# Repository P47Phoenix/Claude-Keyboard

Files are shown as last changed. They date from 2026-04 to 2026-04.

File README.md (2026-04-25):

# Claude Keyboard

A 25-key macropad companion for Claude Code terminal sessions — the **Claude Code Pad**. Dedicated hardware for firing CLI shortcuts (accept, reject, allow, arrow keys, commit/PR macros, plan/model cycle) with per-key RGB, a rotary encoder, a 2U stabilized Enter, and RFID artisan keycap support.

Wireless multi-host via BLE on a Seeed XIAO nRF52840; firmware runs [ZMK](https://zmk.dev).

## Status

**Design-complete (2026-04-23).** Gerbers + case STLs + firmware UF2 are produced, reviewed, and committed. Hardware bring-up + bench verification of the safety thresholds is the next physical step.

| Phase | Scope | State |
|---|---|---|
| 1 | PCB design (schematic, layout, routing, gerbers, BOM, CPL) | **Closed** (11 cycles) |
| 2 | 3D-printed case + bottom plate (CadQuery, PETG) | **Closed** (3 cycles) |
| 3 | Firmware (ZMK on nRF52840) | **Closed** (3 cycles) — `west build` clean, ztest 10/10 |
| 4 | TinyML callouts | **Retired** (Cycle 1 arbitration) |
| 5 | RFID figurine keycap base | **Retired** (post-Phase-3 scope decision) |
| 6 | Integration review | **Retired** (post-Phase-3 scope decision) |

PN532 NFC header + I²C bus remain on the PCB for any future revisit; firmware can wire them up later without a board respin.

## Hardware highlights

- **MCU:** Seeed XIAO nRF52840 (direct-solder castellations). BLE 5.x multi-host. Retired the initial XIAO ESP32-S3 + TinyML/OLED path in favour of a simpler, better-supported stack.
- **Keyswitches:** 24× 1U + 1× 2U Enter, Kailh MX hot-swap (Keebio `MX_Only_HS`), 19.05 mm pitch, Cherry plate-mount 2U stabilizer (slotted housing holes per community canonical footprint).
- **RGB:** 25× SK6812MINI-E reverse-mount, one per key, serpentine chain. Firmware-capped at 300 mA peak per IEC 62368-1 Annex Q.
- **Encoder:** EC11 with metal shaft grounded through plated mounting lugs; ESD TVS on all three encoder signals.
- **NFC:** PN532 header for RFID artisan figurine personality switching (Phase 5).
- **Power:** 1S LiPo via JST-PH with **mandatory cell-level protection PCB** (approved cells from Adafruit/SparkFun — see `docs/build-guide.md`). On-board DMG3415U-7 P-FET reverse-polarity, 500 mA PTC, SPDT slide switch. Charging via the XIAO's USB-C + on-module charger.
- **Safety:** NTC cell-temperature monitor, 5× ESD9L3.3 TVS on exposed I²C + encoder, firmware LED cap + VBAT undervoltage cutoff (3.70 V LEDs-on / 3.50 V LEDs-off).
- **Board:** 120 × 132 mm, 2-layer FR4, HASL lead-free, black soldermask. Freerouting-autorouted (1095 segments, 148 GND stitching vias, antenna keepout inviolate).

## Repository layout

```
claude-code-pad/
├── pcb/                           # Phase 1 deliverables
│   ├── claude-code-pad.kicad_pro|sch|pcb
│   ├── gerbers/                   # 10 layers + drill + job file (fab-ready)
│   ├── bom.csv / cpl.csv          # JLCPCB format
│   ├── DESIGN-NOTES.md            # design rationale + cycle history + pinout verification
│   └── _gen/                      # generator + autoroute pipeline
│       ├── generate.py            # schematic + placement source of truth
│       └── autoroute/             # export_dsn + freerouting + import_ses + widen_power + stitch_gnd
├── firmware/
│   ├── zmk/                       # Phase 3 primary (nRF52840 + ZMK)
│   │   └── README.md              # Hard Requirements for FW-1
│   └── qmk/                       # alternate path (RP2040)
├── case/                          # Phase 2 (MECH-1, CadQuery)
├── figurines/                     # Phase 5 (RFID artisan keycap)
└── docs/
    ├── build-guide.md             # MANDATORY battery requirements + assembly
    └── review-log.md              # Adversarial review paper trail
```

## Orchestration

Design work is done by **persona sub-agents** dispatched via Claude's Agent tool, not by the main thread:

- **Designers** (ECE-1 for PCB, MECH-1 for case, FW-1 for firmware) produce deliverables.
- **Adversarial reviewers** (RED-DFM, RED-SAFETY, RED-COST, RED-MECH, RED-FW) critique in parallel.
- Primary designer iterates until BLOCKER/MAJOR findings clear.
- Every cycle is logged in `claude-code-pad/docs/review-log.md`.

Full orchestration spec: `/var/home/meconnelly/Downloads/claude-code-pad-orchestrated-prompt.md` (authoritative for personas, phases, and reviewers).

## Tooling

This repo targets a **Bazzite** (immutable Fedora atomic) workstation. Package management notes and KiCad / Freerouting / Distrobox conventions are in [`CLAUDE.md`](./CLAUDE.md).

- **KiCad 10.0.1** as a Flatpak (`org.kicad.KiCad`) for GUI + authoritative file reads.
- **KiCad 9.0.8** in a `kicad` distrobox (Podman-backed Fedora 43 toolbox) for kicad-cli automation + the KiCad MCP server (`lamaalrajih/kicad-mcp`, auto-loaded via `.mcp.json`).
- **Freerouting 2.1.0** (Java 21) in the same distrobox for headless autorouting.
- **CadQuery / OpenSCAD** (Phase 2) — user-space Python, no Bazzite layering needed.

### Quick commands

```bash
# DRC via kicad-cli (flatpak, matches GUI rule set)
flatpak run --command=kicad-cli org.kicad.KiCad pcb drc \
  --output /tmp/drc.rpt pcb/claude-code-pad.kicad_pcb

# Open the PCB in the GUI
flatpak run --command=pcbnew org.kicad.KiCad pcb/claude-code-pad.kicad_pcb

# Re-run Freerouting (from distrobox)
distrobox enter kicad -- python3 pcb/_gen/autoroute/export_dsn.py pcb/claude-code-pad.kicad_pcb
distrobox enter kicad -- java -jar ~/.local/share/freerouting/freerouting.jar \
  -de /tmp/claude-code-pad.dsn -do /tmp/claude-code-pad.ses
distrobox enter kicad -- python3 pcb/_gen/autoroute/import_ses.py pcb/claude-code-pad.kicad_pcb
```

## Getting involved

If you want to build one:

1. Read [`claude-code-pad/docs/build-guide.md`](claude-code-pad/docs/build-guide.md) first — especially the **mandatory battery requirements** section.
2. Order the PCB from JLCPCB using `claude-code-pad/pcb/gerbers/` and `claude-code-pad/pcb/cpl.csv`.
3. Source the cells from the approved vendor list in the build guide. **Do not substitute a raw LiPo** — the board relies on cell-level protection PCM.
4. Wait for Phase 2 (case STL) and Phase 3 (ZMK firmware) before assembling a complete unit.

## License

TBD.

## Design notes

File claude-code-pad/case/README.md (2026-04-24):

# Claude Code Pad — Case (Phase 2 Cycle 1)

Parametric CadQuery source for the Claude Code Pad enclosure. Two parts:
top case (MX switch plate + skirt/lip) and bottom case (PCB tray + battery
bay + heat-set insert bosses).

All dimensions are in millimetres. Geometry is authored in a case-local
frame whose (0, 0, 0) corner maps to the PCB's KiCad aux origin at
(100, 100). PCB top face sits at Z = 0; case outer-frame Z = 0 is the top
surface of the bottom-case FLOOR, i.e. the interior of the bottom shell.

## Files

| File | Purpose |
| --- | --- |
| `claude-code-pad.py`  | Parametric CadQuery source. Run directly to build all artefacts. |
| `top-case.stl` | Print-ready top plate (1.8 mm) + 2.5 mm slip-fit lip, with MX cutouts, 2U stab, USB-C, encoder. |
| `bottom-case.stl` | Print-ready bottom tray — 2 mm walls/floor, 4× M3 heat-set bosses, battery bay, vents, feet. |
| `assembly.step` | Full STEP assembly: top + bottom + placeholder PCB/battery/encoder/USB-C for Fusion 360 checking. |
| `test-coupon.stl` | 90 × 90 mm shrinkage-calibration coupon — 3 × 3 MX cutouts at 3 different compensation values. |
| `PARAMS.md` | Table of all exposed CadQuery parameters with defaults and what they control. |

## Build

```bash
case/.venv/bin/python case/claude-code-pad.py
```

This executes `build_top_case()`, `build_bottom_case()`, and
`build_assembly()`, runs the validation gate (volumetric intersection +
plate-top inner-wire count + MX-centre count), exports the three outputs,
and prints `STATUS: READY_FOR_REVIEW` on success.

Typical run takes ≈ 30 s on a modern laptop.

## Print orientation (Creality K2 Plus, PETG)

### Top case

- **Orientation:** PLATE FACE DOWN on bed (Z- points UP in slicer).
- **Why:** Puts the MX-switch clip surface in free-air for the cleanest
  14.0 mm square tolerance — no support scars on the plate top where the
  keycap edges pass.
- **Layer height:** 0.16 mm (tighter fit on MX clips).
- **Infill:** 60 % gyroid. Plate is structural; any less and keypresses flex
  the skirt.
- **Walls:** 4 perimeters at 0.4 mm nozzle (wall shells 1.6 mm; allows 2.0 mm
  sidewall to still be solid perimeter).
- **Supports:** tree supports on the down-facing keycap pockets; none inside
  the USB-C aperture (the sacrificial bridge handles that). Turn supports
  OFF inside the MX cutouts — they're through features, no overhang.
- **Expected print time:** ≈ 6–7 h (Cycle 3: plate 1.8 mm within MX spec, larger corner R from Cycle 2).
- **Expected filament:** ≈ 35–45 g.

### Bottom case

- **Orientation:** CAVITY UP (open side facing +Z in slicer).
- **Why:** Lets the battery-bay walls, boss tops, and strain-relief post all
  print upwards from the floor without support. The outer bottom surface is
  the build plate, so the rubber-foot recesses come out sharp and flat.
- **Layer height:** 0.2 mm.
- **Infill:** 30 % gyroid. Bottom shell doesn't take keypress load.
- **Walls:** 3 perimeters at 0.4 mm.
- **Supports:** OFF. All overhangs are ≤ 45°; the vent holes (Ø 3 mm)
  and divider grooves are self-bridging at 2 mm floor thickness.
- **Bed adhesion (K2 Plus):** **brim 5 mm, 85 °C bed, 235 °C hotend**
  for first-layer grip. A 6 mm case corner radius (Cycle 2) helps avoid
  the corner-lift failure mode; the brim covers the residual risk.
- **Expected print time:** ≈ 9–11 h (Cycle 2 geometry).
- **Expected filament:** ≈ 55–65 g.

### PETG shrinkage policy

Cycle 2 introduces a true compensation framework instead of the Cycle 1
"manually bump the nominal if switches are sloppy" hack.

`SHRINK_COMPENSATION` (default **0.005**) is applied via `_shrink()` to
every inner aperture: MX cutouts, 2U stab slots + wire holes, encoder
knob hole, M3 clearance holes, USB-C slot, slide-switch window, and the
heat-set insert pilot holes. The 0.005 (0.5 %) default is an empirical
K2 Plus / PETG baseline — **calibrate for your own printer and filament
before printing the full case.**

### Print calibration (test coupon)

`case/test-coupon.stl` is a small 90 × 90 mm plate (`PLATE_THICKNESS`, default
1.8 mm — tracks the top-case value) with a 3 × 3
grid of MX-switch cutouts. The three **rows** each use a different
compensation from `COUPON_SHRINK_STEPS = [0.003, 0.005, 0.007]`:

- **North row (top of print)** — 0.3 % compensation (14.042 mm authored)
- **Middle row**              — 0.5 % compensation (14.070 mm authored) — **default**
- **South row (bottom)**      — 0.7 % compensation (14.098 mm authored)

Procedure:

1. Print `test-coupon.stl` flat on the bed with identical slicer settings
   to the real case (PETG, 0.16 mm layer height, 60 % infill, 235 °C
   hotend, 85 °C bed, brim on).
2. Drop an MX switch into each cell.
3. Identify the row whose switches clip with a firm click but slide in
   without forcing. Columns are identical within a row — you're judging
   rows, not columns.
4. If middle row is best: leave `SHRINK_COMPENSATION = 0.005`. If north:
   drop to 0.003. If south: raise to 0.007.
5. Re-run `case/.venv/bin/python case/claude-code-pad.py` to regenerate
   STLs with the calibrated value, then print the real case.

If none of the three rows is acceptable (e.g. all too loose or all too
tight), bracket with new `COUPON_SHRINK_STEPS` values and repeat — e.g.
`[0.008, 0.010, 0.012]` if the 0.7 % row was still sloppy.

## Post-processing

### Heat-set insert procedure (bottom case, 4× M3 brass inserts)

1. Chuck an M3 heat-set insert (CNC-Kitchen IUB-M3-L4 or equivalent, 4.0 mm
   knurl Ø, L = 4.0 mm) onto a soldering iron tip rated for inserts.
2. Set iron to **240 °C** (PETG flow temp — above glass transition but
   below decomposition; aim for a 3–5 s press, not a 10 s press).
3. Seat the insert into each boss pilot (BOSS_OD 8 mm, pilot Ø 4.0 mm nominal,
   INSERT_DEPTH 4.2 mm). Press straight DOWN under the insert's own weight
   + a light 1–2 N assist — DO NOT lean. Stop when the insert flange is
   flush with the boss top.
4. **Torque guidance:** no torque applied during insertion — hand-press only.
   After the insert cools, the M3 screw pull-out strength is ≈ 4 N·m in
   PETG; budget screw torque ≤ 0.8 N·m (snug + 1/8 turn).
5. Withdraw the iron cleanly (straight up, don't wiggle); let the boss
   cool for 30 s.
6. Check thread by running an M3 screw in by hand — it should turn in
   smoothly with no cross-thread.

**Pilot hole is shrinkage-compensated:** the CAD authors the hole at
`INSERT_DIA * (1 + SHRINK_COMPENSATION)` so the cooled pilot lands at
4.0 mm. If the insert goes in too loose (spinning with light torque),
step `SHRINK_COMPENSATION` down 0.001 and reprint; if it refuses to
start, step up 0.001.

**Exception:** bosses within the antenna keepout envelope (5 mm around the
25 × 10.3 mm XIAO antenna patch) are printed as 2.8 mm pilot holes for
direct self-tap, **no metal insert** — metal within 5 mm of the nRF52840
antenna detunes the RF match. See `PARAMS.md` §Antenna keepout.

### NTC thermal path

Cycle 2 replaces the Cycle 1 through-hole window above TH1 with a
**0.4 mm PETG membrane** (one print layer). The membrane is formed by
an under-side pocket in the case floor that leaves 0.4 mm of material
sandwiched between the bay interior (cell side) and the NTC (PCB side).

**Why not a through-hole?** IEC 62368-1 Annex Q treats a direct cell-to-
PCB opening as an ignition path — thermal-runaway flame jets and
ejected debris would reach the MCU. The 0.4 mm membrane preserves the
barrier while adding only 3–5 s of thermal lag, which the TP4056
charger IC's thermal shutdown and the firmware's 2 s NTC sampling loop
both absorb.

**Alternative geometry (builder preference):** if the membrane doesn't
print reliably (thin-floor curl, visible bed texture pulls through),
swap to a full through-hole plus a Kapton-tape + thermal-grease pad
bonded to the PCB. To print that variant, temporarily change the NTC
cut in `build_bottom_case()` to a through extrusion from Z = −floor to
Z = 0. The Kapton pad + thermal grease gives similar thermal coupling
without the membrane's slower first-response.

### FR-4 divider (required for fire-safety rating)

Cut a 1.6 mm FR-4 sheet to **53.9 × 9.0 mm**. Cycle 2 upgrades the slot
to **3-edge retention**: grooves run along the bay's north, east, and
west walls, each 1.8 mm wide × `DIVIDER_HEIGHT` (= `BATT_BAY_DEPTH`) tall.
The card slides in from above, then bottoms on the bay floor; north,
east, and west edges sit in the grooves so the divider can't pop out
under cell swell.

**Install order matters:** the divider must be placed **before** the
top case is closed. Once the screws are home the bay is a closed box
and the divider cannot be inserted. See "Assembly sequence" below.

If you cannot source FR-4, a printed PETG divider passes the structural
requirement but NOT the UL-94-V0 flammability requirement — do not ship
a PETG-divider unit.

### Rubber feet

Apply 4× self-adhesive bumpers into the corner recesses on the case
underside. Cycle 2 default is **3M SJ-5018 (12.7 mm × 1 mm)** — the
larger footprint grips desktops better and the 1 mm height matches the
printed recess depth exactly. The Cycle 1 footprint for **3M SJ-5003
(10 mm × 1 mm)** is still supported: set `FOOT_D = 10.0` and
`FOOT_INSET = 8.0` in `claude-code-pad.py` before rebuilding the STL.

### Screws

4× **M3 × 6 mm** countersunk or pan-head machine screws. Thread into
the heat-set inserts from the top case side. Stack consumes ≈ plate
(1.8) + lip landing (2.5) = **4.3 mm** ahead of the insert; M3 × 6
leaves **1.7 mm** of thread engagement inside the IUB-M3-L4 (4 mm
long) — the remainder is spare. **Do not use M3 × 8** — it bottoms
in the insert's blind end before the head lands, so the joint clamps
on the screw point rather than the head.

(Cycle 3 updated the stack math after PLATE_THICKNESS moved 2.0 → 1.8
to sit within Cherry MX plate spec. Clamp stack went 4.0 → 4.3 mm;
thread engagement went 2.0 → 1.7 mm -- still ≥ one full M3 pitch
(0.5 mm) of engagement and well inside the insert body.)

Hand-tighten: snug + 1/8 turn (≤ 0.8 N·m).

## Assembly sequence

1. Press 4× M3 heat-set inserts into bottom-case bosses (see above).
2. **Slide the FR-4 divider** into the 3-edge (N + E + W) battery-bay
   slots. The divider MUST go in now — once the case is closed the
   bay is a box and you can't reach the grooves.
3. Place LiPo cell in bay, route JST-PH cable through strain-relief
   gate (two-wall slot). The cable does not wrap around a post — it
   passes straight through the gate.
4. Plug JST-PH into J_BAT1 on the PCB.
5. Lower the PCB onto the bosses / mid-edge standoffs. Check that TH1
   sits directly over the NTC thermal membrane (0.4 mm PETG layer —
   deliberate, not a hole) in the bay floor.
6. Clip MX switches into the top-case plate (already installed in the
   top STL). Slide Cherry 2U stab into the Enter position; clip the
   wire.
7. Drop the top case onto the bottom case — the 0.5 mm lead-in
   chamfers let the 0.4 mm slip-fit lip land without snagging. MX
   switch pins should pass through the PCB hot-swap sockets.
8. Fasten 4× M3 × 6 mm screws (see §Screws — do NOT use M3 × 8).
9. Press keycaps. Connect USB-C. Power on.

## Known gaps / review targets

The following are deliberately left for RED-MECH and RED-COST to probe in
Cycle 2:

- Print-in-place OLED cutout: not yet included. Depends on OLED
  placement in firmware BOM which isn't pinned.
- Snap-fit latches: currently the case relies on 4× M3 screws for
  closure. A no-screw snap-fit variant is an option.
- 3M double-sided tape pads for the battery in the bay: called out in
  assembly but no recess is printed.
- RFID artisan-keycap figurine dock: Phase 5 deliverable, out of scope.

See `/var/home/meconnelly/Documents/GitHub/Claude-Keyboard/claude-code-pad/docs/review-log.md`
for the full review workflow.

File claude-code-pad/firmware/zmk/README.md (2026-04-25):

# Claude Code Pad - ZMK firmware

**Phase 3 Cycle 1 (FW-1).** The Hard Requirements below are the
hardware-design contract that this firmware implements. Every clause
is traceable to a specific IEC / regulatory rule; see the review log
for the full chain of custody.

Phase 3 C1 added: shield tree under `boards/shields/claude_code_pad/`,
safety drivers under `drivers/ccp_safety/`, builder wire guide in
`BODGE-MAP.md`, and QMK alternate scaffold one level up in
`../qmk/`.

---

## Hard Requirement: Approved cells

**DO NOT plug in a raw / unprotected LiPo cell. Fire risk.**

Only single-cell 3.7 V LiPo packs with INTEGRAL protection PCB
(DW01A + FS8205A class) and **JST-PH 2.0 mm** 2-pin pigtail are
approved. Cycle 5 migrated `J_BAT` to JST-PH (up from a 1.0 mm pitch
spec in earlier cycles) because the protected-1S-LiPo ecosystem
(Adafruit, SparkFun, Pimoroni) uses JST-PH; 1.0 mm pitch cells with
integrated PCMs are not routinely stocked.

**Cycle 4 carried two hallucinated LCSC SKUs (C5290961, C5290967).**
Both return HTTP 404. **Do not attempt to source those part numbers.**
Cycle 5 replaces them with the following HTTP-200-verified SKUs:

| Source | Link | Capacity | PCM? | JST |
|---|---|---:|---|-----|
| Adafruit | [#1578](https://www.adafruit.com/product/1578) | 500 mAh  | yes | PH |
| Adafruit | [#3898](https://www.adafruit.com/product/3898) | 400 mAh  | yes | PH |
| Adafruit | [#328](https://www.adafruit.com/product/328) | 2500 mAh | yes | PH |
| SparkFun | [PRT-13851](https://www.sparkfun.com/products/13851) | 400 mAh | yes | PH |
| Adafruit | [#1317](https://www.adafruit.com/product/1317) | 150 mAh  | yes | PH |

Full polarity diagram, PCM-vs-PTC timing analysis, and cell
substitution rules live in `pcb/DESIGN-NOTES.md §Battery
requirements (MANDATORY)` and `§Cycle 5 §Verified procurement table`.
Short version:

- Cell-integrated PCM trips at <10 ms @ 4 A (DW01A spec).
- Board F1 PTC trips at ~100 ms @ 4 A (500 mA hold).
- Raw cell through 500 mA PTC into a 4 A fault sustains for ~100 ms;
  cell dT > 60 degC -> vent-with-flame per IEC 62133-2 Annex E.
  The cell PCM is what prevents this.

---

## Hard Requirement: Battery Cutoff Voltage

Firmware **must** implement undervolt cutoff measured at the VBAT_ADC
divider (NOT at Vcell upstream of Q_REV). Phase 3 Cycle 2
(RED-SAFETY SF-M4 / SF-M6) separates the LED-derate tripwire from
the graceful-shutdown tripwire:

| LED state | Cutoff / derate VBAT |
|---|---|
| LED peak derate | linear **4.00 V -> 3.80 V** (100 % -> 0 %) |
| LEDs latch off  | at **3.80 V** (end of the derate ramp) |
| LEDs re-enable  | at **3.90 V** (100 mV hysteresis above latch) |
| Graceful shutdown | at **3.50 V** (LEDs already off) |

**Rationale (Cycle 2 revision):** in Cycle 1 the derate curve's
lower bound (3.70 V) was also the graceful-shutdown threshold, so
3.70 V fired `graceful_shutdown()` on the first sample and the
two-tier design never got to activate. Cycle 2 raises the derate
band to 4.00 -> 3.80 V so the LED-off latch has real separation
from the BLE-disconnect latch at 3.50 V. A cell at 3.80 V under
zero-LED load sits at ~3.75 V at the VBAT node and still feeds the
AP2112K LDO with ~0.45 V of dropout headroom; graceful shutdown
at 3.50 V therefore has 300 mV of headroom for "save and reconnect"
HID events after the LEDs have been cut.

**Measurement:** VBAT_ADC = VBAT / 2 (2x 1 MOhm resistor divider,
100 nF ADC anti-alias cap). Source impedance ~500 kOhm -- firmware
must use nRF52840 SAADC **OVERSAMPLE >= 2^3** (8 samples) and
BURST mode when reading VBAT_ADC.

**Pin:** VBAT_ADC is on XIAO back-side rear-pad jumper **slot 5**
(patch_x+4, Cycle 5 slot reassignment). User solder-wires from
`J_XIAO_BP` slot 5 to **P0.31 / AIN7** on the XIAO's back-side
castellation. (Cycle 1 of this README said "P1.11 / AIN7" -- FW-B2
correction: on the nRF52840, P1.x pins are NOT SAADC-capable. AIN7
lives on P0.31. Verified against
nRF52840 product specification v1.7 §6.17 Analog input pin
assignments: AIN0..7 correspond to P0.02/.03/.04/.05/.28/.29/.30/.31.
All other P1 pins are digital-only.)

---

## Hard Requirement: VBAT_ADC integrity (broken-wire detection) [C5-M5]

The VBAT_ADC cut-off above is the graceful-shutdown tripwire. Because
the ADC line is a **hand-soldered jumper wire** from the rear-pad
slot to a back-side GPIO, a broken wire leaves the ADC floating and
reads garbage -- firmware would never trip the cut-off and the cell
would be over-discharged to cell-damage levels.

Firmware **must** detect a broken VBAT_ADC jumper and fail safe:

- Sample VBAT_ADC at 250 ms cadence (SAADC OVERSAMPLE>=2^3, BURST
  mode). Cycle 2 dropped this from 10 s per RED-SAFETY SF-B3; nRF52840
  brownout at 1.7 V plus up to 400 mV LDO ESR sag can traverse the
  cutoff band faster than a 10 s window.
- Compute **max-abs-residual** (max of |sample[i] - mean|) over a
  rolling 8-sample window. If > 100 mV, the window is suspect
  (floating input picks up 50/60 Hz hum and noise).
- Compute **instantaneous step** between each sample pair. If any
  step exceeds +/- 0.3 V, the window is suspect (a real cell cannot
  change voltage that fast under 300 mA load).
- **Cycle 2 SF-M5:** require TWO consecutive suspect windows before
  latching graceful_shutdown. A single window of cell-sag under an
  RGB transient no longer false-latches.
- **Cycle 2 SF-M7:** physical-range sanity band. If cell_mv < 2800 OR
  cell_mv > 4400, latch graceful_shutdown immediately (catches
  open-divider-resistor: one of the 1 MOhm legs failing open would
  put ~3.3 V on the ADC pin and the de-divided reading would exceed
  4.4 V).
- When EITHER the broken-wire latch or the physical-range band trips,
  enter the **SAME** graceful-shutdown path as the 3.50 V
  undervoltage cutoff: disable all LEDs, BAS -> 0, disconnect BLE,
  stop advertising, log warning.

This fail-safe cannot be disabled at runtime.

**User-recoverable safety clear (SF-M5):** holding Fn + the top-
right key through a RESET boot re-runs `bt_settings_clear_default()`
and resets the `graceful_shutdown_latched` flag. This is a debug
escape hatch for builders who have confirmed the bodge is sound but
need to clear an earlier latch event from flash.

---

## Hard Requirement: LED peak current cap

Firmware **must** cap total RGB LED peak current at **300 mA**.

This is per **IEC 62368-1 Annex Q §Q.2** (first-fault-safe limit
of a PS2 energy source). The XIAO nRF52840 module's on-board
AP2112K-3.3 LDO drives all 25 SK6812MINI-E LEDs; the LDO is rated
600 mA steady-state. Running 25 LEDs at full white nominal would
draw ~1.5 A and either trigger the LDO thermal shutdown (good) or
eventually fail open-drain (bad). Our PCB design has NO redundant
3V3 regulator; the 300 mA cap is the primary safety enforcement.

### Implementation requirements

- The cap MUST be applied at `driver_init()` time, before any user
  RGB effect can load.
- The cap MUST NOT be runtime-configurable via ZMK Studio, the
  keymap, or any characteristic over BLE.
- The per-LED PWM value is scaled such that the sum across all 25
  LEDs at any instant is <=300 mA (worst case = ~12 mA/LED at full
  white; colour-mixed animations may run higher per-LED but stay
  within the 300 mA aggregate via the driver's dithered-power model).

### Scope boundary (hostile recompile)

This cap is first-fault-safe against firmware **bugs**, not against
a deliberate recompile. Users who rebuild ZMK to remove the cap
assume the thermal/fire hazard obligation personally. See
`pcb/DESIGN-NOTES.md §Safety §Firmware cap` for the IEC 62368-1
Annex Q language.

**No hardware jumper bypass exists on this board.** (Cycle 3
documented a "Phase-5 hardware jumper" for future use; Cycle 4
removed that reference -- no such pad is on the PCB.)

### RGB driver init order (FW-1 obligation)

Before enabling the `+3V3` LED power path, firmware **must** drive
the `RGB_DIN_MCU` pin as GPIO output LOW. Worst-case pre-init
nRF52840 GPIO state is floating CMOS input with ~10 kOhm pull-up;
25 LEDs seeing random data on DIN at power-on could briefly light
at uncontrolled brightness. Sequence:

1. MCU reset -> GPIO default hi-Z.
2. Set `RGB_DIN_MCU` as GPIO output, drive LOW.
3. Enable +3V3 rail (on this board it's always on when VBAT is
   present; requirement still stands for future board revisions).
4. Initialise WS2812 driver with first frame = all-LEDs-off;
   apply 300 mA firmware cap to every subsequent frame.
5. Enter normal operation.

### Second-line protection

If firmware cap fails AND a transient demands >600 mA, the XIAO
AP2112K-3.3 LDO's thermal shutdown (Tj = 165 degC, ~2 s at 1.5 A)
catches it. Board temperature does not reach the cell thermal
runaway threshold (~130 degC) within that interval.

---

## Hard Requirement: NTC fallback

If the NTC ADC channel (NTC_ADC, XIAO pin D1 / P0.03 -- P1.15 was
the original Cycle 5 landing, moved in firmware Cycle 1 because
P1.x is not SAADC-capable) reads **out-of-range** (floating input
-- typical when TH1 is not hand-installed, or a wire break on the
axial thermistor), firmware **must**:

- Reduce the LED peak cap from 300 mA to **100 mA** until a valid
  temperature reading resumes.

Behavior documented to satisfy **IEC 62368-1 Annex Q** fallback
requirements for a degraded thermal-sensing subsystem. "Out of
range" = ADC reads either < 0.1 V (short-to-GND / wire break) or
> 3.1 V (short-to-+3V3).

**Cycle 2 over-temperature threshold (SF-M9):** firmware caps LEDs
at 100 mA when the decoded NTC temperature exceeds **50 degC**
(dropped from 60 degC). The NTC on this revision is co-located with
the LDO, not the cell; the NTC-to-cell-surface correlation is not
yet bench-validated, and a 10 degC cushion keeps the cell well
below the 60 degC IEC 62133-2 onset threshold even under worst-case
correlation error. Rev-B relocates the NTC to a cell-contact
position.

**Cycle 2 rate-of-change sanity (SF-M10):** a decoded temperature
delta **> 5 degC per sample** (at the 2 s default
`CONFIG_CCP_THERMAL_GUARD_SAMPLE_INTERVAL_MS` cadence -> ~2.5 degC/s)
OR a temperature outside the [-10 .. +70 degC] plausibility band
forces the 100 mA fallback regardless of the absolute reading. The
limit is expressed in degC-per-sample so that a user who tightens
the sample interval (e.g. to 500 ms) automatically tightens the
real-time rate-limit (5 degC / 0.5 s = 10 degC/s) -- which matches
the increased confidence available from faster sampling. Catches a
partially-shorted divider that reads in-range but with nonsense
physics.

**Cycle 2 floating-pin probe (FW-M6):** on the first in-range
reading after any out-of-range sample, firmware briefly drives the
NTC pin HIGH, releases, and re-samples. A connected divider
discharges the stray capacitance within < 100 us; a floating pin
holds the driven level. A post-release sample within 50 mV of 3.3 V
=> floating pin => 100 mA fallback. Does NOT accidentally flag a
real NTC-shorted-to-+3V3 because that case already lands in the
out-of-range path before the probe runs.

**Cycle 2 NTC decode (FW-M5):** integer-only, 65-entry log-ratio
LUT. `log()` / newlib dependency no longer on the critical path;
worst-case decode error < 0.5 degC over the 0..70 degC plausibility
band.

---

## Hard Requirement: BLE security (Phase 3 Cycle 2, SF-B4)

Cycle 1 silently shipped legacy "just works" pairing while this
README claimed passkey authentication. Cycle 2 corrects both the
code and the documentation.

**Posture (as-shipped Cycle 2):**

| Setting | Value | Purpose |
|---|---|---|
| `BT_SMP_SC_PAIR_ONLY` | y | LE Secure Connections (ECDH) only |
| `BT_SMP_ENFORCE_MITM` | y | Authenticated pairing required |
| `BT_BONDABLE` | n | New bonds only in pairing-mode window|
| `BT_CTLR_TX_PWR_PLUS_4` | y | +4 dBm (PCB antenna tuned for this)  |

**What this means without a display or keypad on the device:**

The Claude Code Pad today has no OLED (Phase 1 Cycle 1 cut it for
cost) and no dedicated 10-key passkey entry. With `ENFORCE_MITM=y`,
pairing will only succeed via hosts that implement:

1. **LE Secure Connections with Numeric Comparison.** Modern
   macOS / iOS / Android / Windows 10+ all support this for BLE
   peripherals that have no I/O capability -- the host shows a
   6-digit number and the user presses "yes/no" on the host side.
   No keypad on the peripheral required.
2. **BLE OOB (Out Of Band) pairing.** Not applicable for this
   build.

Hosts that try to fall back to legacy "Just Works" (no user
confirmation, no MITM resistance) will have pairing rejected by
the peripheral's SMP layer. This is the intended behaviour. A
drive-by attacker cannot silently bond; an attacker who owns the
host already has HID access and BLE MITM is moot.

**Pairing-mode window (SF-M12, Phase 3 Cycle 3 — IMPLEMENTED):**
`BT_BONDABLE=n` means new bonds are rejected outside an explicit
pairing-mode window. The shipped keymap binds the `&ccp_pair`
behavior to a 3-second hold on the BT-layer position (0,0):

- Enter the BT layer (today: keymap editing; combo entry is queued
  for Phase 3 Cycle 4 polish).
- Tap (0,0) = `&bt BT_SEL 0` (regular profile-0 select).
- Hold (0,0) for 3 s = `&ccp_pair` fires.

`&ccp_pair` calls `bt_set_bondable(true)`, schedules a 60-second
`k_work_delayable` that re-asserts `bt_set_bondable(false)`, and
toggles the RGB strip at 1 Hz for visible feedback while the
window is open. Re-pressing the chord during the window resets
the timer to a fresh 60 s (no toggle, no early cancel — see
`drivers/ccp_safety/ccp_pair.c` header for rationale).

If `ccp_safety_graceful_shutdown` latches at any point during the
window, the window is force-closed (bondable=false) — battery /
thermal cutoffs always win over a pairing flow.

**Phase 5 upgrade path:** when the PN532 NFC reader + the RGB LEDs
are available for passkey-display use, the firmware will implement
colour-coded 6-digit passkey display via LEDs 0..5 and switch to
`NoInputNoOutput -> DisplayOnly` IO-capabilities advertising.
Documented in `docs/safety-verification.md §BLE MITM test plan`.

---

## Pin map (Cycle 5)

See `pcb/DESIGN-NOTES.md §Cycle 5 §Routing topology summary` for the
canonical pin-to-net mapping. Cycle 5 rear-pad slot reassignment:

| Slot | Signal |
|---|---|
| 0 | ENC_A |
| 1 | ENC_B |
| 2 | ENC_SW |
| 3 | RGB_DIN_MCU |
| 4 | ROW3 |
| 5 | VBAT_ADC |
| 6 | ROW4 |

Slot 0 sits at x=patch_x-6=158, slot 6 at x=patch_x+6=170 with
patch_x=mcu_x+4=164 on a 115x132 mm board (mcu_x=160.0 after Cycle-5
width bump 115->120 mm).

### Cycle 5 builder-bodge wires (required for full functionality)

Cycle 5 stripped the following from the PCB to guarantee zero
`shorting_items`. All 35 are rear-side bodge wires the builder
must hand-solder during assembly. Priority order:

1. **RGB chain (25 wires)** -- LED DOUT(n) to DIN(n+1) along the
   serpentine order 1-2-3-4-5-10-9-8-7-6-11-12-13-14-15-20-19-18-17-16-21-22-23-24-25,
   plus MCU `RGB_DIN_MCU` (via R1) to LED1 DIN.
2. **Decap caps (4 wires)** -- C1/C3 pad 1 to MCU pin 3 (+3V3);
   C4 pad 1 to MCU pin 1 (VUSB); C2 pad 1 to MCU BAT+ pad.
3. **I2C bus (2 wires)** -- MCU pin 8 (SDA) to J_NFC pin 3;
   MCU pin 9 (SCL) to J_NFC pin 4.
4. **ROW3/4 (2 wires)** -- rear-pad slot 4 to ROW3 B.Cu spine east
   end (x=198.6, y=205.675); rear-pad slot 6 to ROW4 B.Cu spine east
   end (x=204.15, y=224.725).
5. **NTC_ADC (1 wire)** -- R_NTC pin 1 to MCU pin 14 (P0.03/AIN1).
6. **Encoder (3 wires)** -- EC1 A/B/SW to rear-pad slots 0/1/2.

Full photo guide in `docs/build-guide.md §Appendix A`.

---

## Phase 3 C1 addendum: NTC_ADC pin move

Cycle 5 landed NTC_ADC on MCU pin 14 (D10 / P1.15). P1.15 is **not**
SAADC-capable on the nRF52840; firmware Cycle 1 moves NTC_ADC to MCU
pin 5 (D1 / P0.03 / AIN1) and shifts COL1 from D1 to D10. See
`BODGE-MAP.md` for the bodge-wire delta.

---

## Building

### Prerequisites

- Python 3.10+, `west`, Zephyr SDK (toolchain). Quick install:
  ```bash
  pipx install west
  # or:  brew install west
  wget https://github.com/zephyrproject-rtos/sdk-ng/releases/download/v0.17.0/zephyr-sdk-0.17.0_linux-x86_64.tar.xz
  tar xf zephyr-sdk-0.17.0_linux-x86_64.tar.xz -C ~
  cd ~/zephyr-sdk-0.17.0 && ./setup.sh
  ```
- ZMK pulls the Zephyr tree itself via `west update`.

### Clone + init

```bash
mkdir -p ~/zmk-ccp && cd ~/zmk-ccp
git clone https://github.com/<you>/Claude-Keyboard src/ccp
west init -l src/ccp/claude-code-pad/firmware/zmk/config
west update
west zephyr-export
pip install -r zephyr/scripts/requirements-base.txt
```

### Build

```bash
cd ~/zmk-ccp
west build -s zmk/app -b xiao_ble/nrf52840 \
    -- -DSHIELD=claude_code_pad \
       -DZMK_EXTRA_MODULES="$PWD/src/ccp/claude-code-pad/firmware/zmk"
```

Note: the Zephyr 4.1+ board name is `xiao_ble/nrf52840`. Upstream
Zephyr renamed the old `seeeduino_xiao_ble` board to `xiao_ble` as
part of the HWMv2 migration; the `/nrf52840` qualifier is required
in v4.1 because the XIAO "Sense" variant (which carries an IMU)
shares the same board tree.

Output UF2: `build/zephyr/zmk.uf2`.

A pre-built reference UF2 lives at `firmware/zmk/build-artifacts/zmk.uf2`
(checked into the repo for the current Cycle 2 commit). Use it for
quick smoke tests before standing up a local toolchain; the paired
`firmware/zmk/build-artifacts/build.log` is the full `west build`
log from the same build.

### Flash (UF2 bootloader)

1. Double-tap the RESET button on the XIAO nRF52840. It enumerates as
   `XIAO-BOOT` USB mass storage.
2. Copy `build/zephyr/zmk.uf2` to that drive.
3. The board reboots and enumerates as `Claude Code Pad` (USB HID +
   BLE).

### First-boot checklist

Observe the ZMK log over USB CDC (CONFIG_ZMK_USB_LOGGING=y in a debug
build) or over RTT:

```
[INF] ccp_rgb_init_safe: RGB_DIN_MCU pre-driven LOW
[INF] zmk_rgb_underglow: inited
[INF] ccp_battery_guard: VBAT=<mV> cap=<n> leds_cut=0
[INF] ccp_thermal_guard: NTC <mV> -> <degC> cap=100
```

If the thermal guard reports `cap=33` persistently, the NTC bodge is
missing or the thermistor is not installed -- the 100 mA fallback cap
is in effect and **this is intentional**. See `BODGE-MAP.md` to fix.

### Troubleshooting

- **"board seeeduino_xiao_ble not found"** -- the west manifest did
  not pull the Zephyr tree containing the Seeed XIAO BLE definition.
  Run `west update` again; verify `~/zmk-ccp/zephyr/boards/arm/
  seeeduino_xiao_ble/` exists.
- **"shield claude_code_pad not found"** -- `ZMK_EXTRA_MODULES` is not
  pointing at the firmware/zmk directory of your checkout, or the
  path contains spaces and is not quoted.
- **BLE won't pair, or pairs then drops immediately** -- clear the
  pairing table: tap the BT layer (C2 work adds a dedicated binding;
  for now re-flash after deleting `/lfs1/settings/bt` via the ZMK
  studio tool) then re-pair. On Linux hosts, delete the bond on the
  host side too (`bluetoothctl remove <mac>`).
- **All 25 LEDs flash bright-white on boot** -- the pre-init GPIO
  hook failed; the LEDs saw garbage on DIN. Verify in the log that
  `[INF] ccp_rgb_init_safe: RGB_DIN_MCU pre-driven LOW` appeared
  before any RGB driver line. If absent, rebuild with a clean cache.

### Validation gate for local / CI builds

```bash
# ERC-equivalent: Kconfig sanity
west build -t menuconfig   # should open clean, no unresolved symbols
# Static analysis (if installed)
west build -t clang-analyzer
```

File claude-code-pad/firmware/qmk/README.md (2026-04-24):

# Claude Code Pad -- QMK alternate (RP2040 Pro Micro)

**Status:** Phase 3 Cycle 1 skeleton. Not production-validated.
ZMK on XIAO nRF52840 is the primary firmware.

This subtree exists so RED-FW has a reviewable escape hatch if ZMK turns
out to be the wrong framework (BLE stack quirks, Zephyr version drift,
nRF52840 power-management bugs). The target MCU is an **RP2040 Pro
Micro** (e.g. Sparkfun Pro Micro RP2040 or SparkFun-clone compatibles)
paired with the same PCB via a pin-compatible daughter board (the Pro
Micro footprint matches the XIAO castellations in spirit but needs a
solder-in adapter because pitch and orientation differ).

## Porting notes

- QMK is **USB-only**; no BLE. If BLE is required, stay on ZMK.
- RP2040 has 26 user GPIOs vs nRF52840's 48; all 25 matrix nets + the
  encoder still fit, with 0 spare for NFC. The PN532 header would lose
  its I2C line on the alt firmware (phase 5 work).
- SK6812 driven via PIO state machine (`ws2812_pio` library). 300 mA
  cap is enforced in `rgb_matrix_config` with a brightness limit of
  `RGB_MATRIX_MAXIMUM_BRIGHTNESS 50` (50/255 * 25 LEDs * 60 mA = 294 mA).
- VBAT monitoring / cell cutoff are **not implemented** in this
  alternate; users running QMK on a battery-powered build accept that
  loss. Most Pro Micro RP2040 builds are USB-bus-powered.

## Wiring delta vs XIAO PCB

You will need an adapter PCB or hand-wired jumpers between the Pro
Micro footprint and the XIAO pads:

| Pro Micro pin | Signal | XIAO equivalent  |
|---|---|---|
| GP0 | COL0 | D0 (P0.02) |
| GP1 | COL1 | D10 (P1.15) |
| GP2 | COL2 | D2 (P0.28) |
| GP3 | COL3 | D3 (P0.29) |
| GP4 | COL4 | D6 (P1.11) |
| GP5 | ROW0 | D7 (P1.12) |
| GP6 | ROW1 | D8 (P1.13) |
| GP7 | ROW2 | D9 (P1.14) |
| GP8 | ROW3 | BP slot 4 |
| GP9 | ROW4 | BP slot 6 |
| GP10 | ENC_A | BP slot 0 |
| GP11 | ENC_B | BP slot 1 |
| GP12 | ENC_SW | BP slot 2 |
| GP13 | RGB_DIN | BP slot 3 |
| GP14 | SDA | D4 (P0.04) |
| GP15 | SCL | D5 (P0.05) |
| GP26 / ADC0 | NTC_ADC | D1 (P0.03) |

VBAT_ADC (BP slot 5) is intentionally unmapped.

## Build

```bash
qmk compile -kb claude_code_pad -km default
qmk flash    -kb claude_code_pad -km default   # press RP2040 BOOTSEL
```

Not CI'd. RED-FW review scope.

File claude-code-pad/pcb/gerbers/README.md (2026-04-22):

# Gerbers - Claude Code Pad

JLCPCB-ready gerber + drill + CPL set produced by `kicad-cli` 9.0.8 from
`../claude-code-pad.kicad_pcb`.

## Files

| File | Purpose |
|---|---|
| `claude-code-pad-F_Cu.gtl` | Top copper |
| `claude-code-pad-B_Cu.gbl` | Bottom copper |
| `claude-code-pad-F_Paste.gtp` | Top paste stencil |
| `claude-code-pad-B_Paste.gbp` | Bottom paste stencil |
| `claude-code-pad-F_Mask.gts` | Top solder mask |
| `claude-code-pad-B_Mask.gbs` | Bottom solder mask |
| `claude-code-pad-F_Silkscreen.gto` | Top silkscreen |
| `claude-code-pad-B_Silkscreen.gbo` | Bottom silkscreen |
| `claude-code-pad-Edge_Cuts.gm1` | Board outline + LED apertures |
| `claude-code-pad.drl` | Excellon drill (PTH + NPTH) |
| `claude-code-pad-job.gbrjob` | Gerber X2 job file |

## How to regenerate

Cycle 3: the CPL command now uses `--exclude-dnp` so that EC1, J_NFC, U1,
TH1 and SW_PWR (marked DNP in the BOM) are not listed in the fab CPL.
This closes B-CPL-DNP.

Cycle 9: **DRC must always be invoked with `--schematic-parity --severity-all`**.
Without those flags, kicad-cli silently hides the schematic-to-PCB
cross-check categories (`net_conflict`, `footprint_symbol_mismatch`,
`footprint_symbol_field_mismatch`, `missing_footprint`,
`extra_footprint`) that the KiCad 10 GUI shows by default. See
`../DESIGN-NOTES.md` §Workflow §DRC for the rationale.

```bash
# DRC (Cycle 9 canonical form -- parity + all severities)
flatpak run --command=kicad-cli org.kicad.KiCad pcb drc \
  --schematic-parity --severity-all \
  --output /var/home/meconnelly/Documents/GitHub/Claude-Keyboard/claude-code-pad/pcb/_gen/drc.rpt \
  /var/home/meconnelly/Documents/GitHub/Claude-Keyboard/claude-code-pad/pcb/claude-code-pad.kicad_pcb

# Gerbers
distrobox enter kicad -- kicad-cli pcb export gerbers \
  --output /var/home/meconnelly/Documents/GitHub/Claude-Keyboard/claude-code-pad/pcb/gerbers/ \
  --layers "F.Cu,B.Cu,F.Paste,B.Paste,F.Silkscreen,B.Silkscreen,F.Mask,B.Mask,Edge.Cuts" \
  --use-drill-file-origin \
  /var/home/meconnelly/Documents/GitHub/Claude-Keyboard/claude-code-pad/pcb/claude-code-pad.kicad_pcb

# Drill
distrobox enter kicad -- kicad-cli pcb export drill \
  --output /var/home/meconnelly/Documents/GitHub/Claude-Keyboard/claude-code-pad/pcb/gerbers/ \
  --format excellon --drill-origin plot \
  --excellon-units mm --excellon-zeros-format decimal \
  /var/home/meconnelly/Documents/GitHub/Claude-Keyboard/claude-code-pad/pcb/claude-code-pad.kicad_pcb

# Position file (CPL) -- Cycle 3: --exclude-dnp flag added.
distrobox enter kicad -- kicad-cli pcb export pos \
  --output /var/home/meconnelly/Documents/GitHub/Claude-Keyboard/claude-code-pad/pcb/cpl.csv \
  --format csv --units mm --side both \
  --use-drill-file-origin \
  --exclude-dnp \
  /var/home/meconnelly/Documents/GitHub/Claude-Keyboard/claude-code-pad/pcb/claude-code-pad.kicad_pcb

# Verify DNP exclusion:
grep -cE '^"(EC1|J_NFC|U1|TH1|SW_PWR)"' \
  /var/home/meconnelly/Documents/GitHub/Claude-Keyboard/claude-code-pad/pcb/cpl.csv
# Expected output: 0
```

## JLCPCB order settings

- Material: FR4
- Layers: 2
- Dimensions: 115 x 124 mm (see `../DESIGN-NOTES.md` Cycle 3 §Deviations -
  +9 mm height waiver to clear XIAO nRF52840 module castellations)
- Thickness: 1.6 mm
- Colour: Black (matte or gloss)
- Silkscreen: White
- Surface finish: HASL-LF (lead-free)
- Min via / track: 0.4 / 0.15 mm (well within JLCPCB standard)
- Impedance control: N/A
- Gold fingers: N/A
- Castellated holes: N/A (MCU castellations live inside board area,
  not on the board edge)

Zip the above 11 files and upload to JLCPCB. Use `../bom.csv` for SMT
Assembly (rows marked `DNP` are skipped on the JLCPCB side too) and
`../cpl.csv` (kicad-cli output with `--exclude-dnp`) for pick-and-place.

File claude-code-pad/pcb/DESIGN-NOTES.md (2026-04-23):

# Claude Code Pad — PCB Design Notes (Phase 1, Cycle 1)

Author: **ECE-1**
Date:   2026-04-19
KiCad target: **9.0** (schematic `(version 20250114)`, pcb `(version 20241229)`)

This document captures the rationale behind the schematic and PCB files in
this directory, every deliberate deviation from the orchestrator spec, and
the known gaps RED-DFM / RED-SAFETY / RED-COST should expect to find in
Cycle 1.

---

## 1. Files

| Path | Purpose | Lines |
|---|---|---|
| `claude-code-pad.kicad_pro` | Project settings (KiCad 9) | ~220  |
| `claude-code-pad.kicad_sch` | Schematic (generated) | ~1250 |
| `claude-code-pad.kicad_pcb` | Board (generated) | ~950  |
| `bom.csv` | JLCPCB-format BOM | 12 data rows |
| `cpl.csv` | JLCPCB-format placement CPL | 116 rows |
| `gerbers/*.g??, *.drl` | Fab output set | 11 files |
| `gerbers/README.md` | Fab order notes | |
| `_gen/generate.py` | Python generator (source of truth) | ~1100 |

Everything except `cpl-kicad.csv` (raw kicad-cli output, intermediate) is
reproducible from `_gen/generate.py`.

## 2. Layer stackup

2-layer FR4, 1.6 mm, 1 oz Cu on both sides, HASL lead-free, black solder
mask, white silkscreen. Edge bevels not requested.

- **F.Cu** — MCU, peripheral headers, SK6812MINI-E LEDs (reverse-mount,
  pads on F.Cu, body sits on B.Cu side), LED decoupling caps, pull-ups,
  RGB series R, bulk caps, encoder (through-hole), slide switch
  (through-hole), JST-PH (SMD), PTC fuse (0805), tooling holes.
- **B.Cu** — Kailh hot-swap sockets (SMD), 1N4148W matrix diodes (SOD-123),
  the 4 MX plate pegs / central barrel holes belong to the switch
  footprint (PTH, span both Cu layers).
- **F.Mask / B.Mask** — standard apertures; no custom openings.
- **F.SilkS** — keycap labels per spec (not added in Cycle 1 — covered by
  Cycle 2 once MECH-1 confirms case legend plan).
- **Edge.Cuts** — rounded-rect 135 x 145 mm, R3 corners.

Ground pours on both F.Cu and B.Cu (thermal-relief connections to pads,
0.2 mm thermal gap).

## 3. Net classes & trace widths

| Net class | Nets matched | Track width | Clearance | Via (dia/drill) |
|---|---|---|---|---|
| Default | all signal / matrix | 0.25 mm | 0.20 mm | 0.6 / 0.3 mm |
| Power | VBAT, VBAT_*, 3V3, 5V, GND | 0.50 mm | 0.20 mm | 0.8 / 0.4 mm |

RGB_DIN_MCU and each RGB_D* hop carries single-LED peak current (~20 mA
× 3 = 60 mA max per LED) but with aggregate worst case 25 × 60 mA = 1.5 A
on the 3V3 rail. Pour on GND and trace routing for 3V3 uses Power netclass
(0.5 mm) with an additional 3V3 star bus recommended for Cycle 2 routing.

## 4. Pin assignments (XIAO ESP32-S3)

The XIAO ESP32-S3 has 14 pins on its 2× 1×7 headers (top side of the
module) and additional castellated pads on the bottom. This design uses
**14 front pins for matrix + I²C + D5 ROW0 + ENC_A**, then breaks the
remaining rails out on a separate **1×7 rear castellated breakout**
(`J_XIAO`) that the user solders to the XIAO's back-side pads.

### Front header (2× 1×7, 2.54 mm pitch, J\_MCU\_1..14)

| Pin | Net | XIAO label (spec) | Rationale |
|-----|---|---|---|
| 1 | 5V | 5V | USB-derived rail |
| 2 | GND | GND | — |
| 3 | 3V3 | 3V3 | Regulator output |
| 4 | COL0 | D0 / GPIO1 | Matrix COL0 |
| 5 | COL1 | D1 / GPIO2 | Matrix COL1 |
| 6 | COL2 | D2 / GPIO3 | Matrix COL2 |
| 7 | COL3 | D3 / GPIO4 | Matrix COL3 |
| 8 | COL4 | D4 / GPIO5 | Matrix COL4 |
| 9 | ROW0 | D5 / GPIO6 | Matrix ROW0 |
| 10  | SDA | D6 / GPIO43 | ESP32-S3 hardware I²C-0 SDA |
| 11  | SCL | D7 / GPIO44 | ESP32-S3 hardware I²C-0 SCL |
| 12  | ROW1 | D8 / GPIO7 | Matrix ROW1 |
| 13  | ROW2 | D9 / GPIO8 | Matrix ROW2 |
| 14  | ENC_A | D10 / GPIO9 | Encoder A phase |

### Rear breakout (`J_XIAO`, 1×7 castellated)

| Pin | Net | XIAO label |
|-----|---|---|
| 1 | ROW3 | A5 / GPIO17 (mapped to D7? see note) |
| 2 | ROW4 | A4 / GPIO16 |
| 3 | ENC_B | A0 / GPIO1 rear (BAT-pad neighbourhood) |
| 4 | ENC_SW | A1 / GPIO2 rear |
| 5 | RGB_DIN_MCU | A2 / GPIO3 rear |
| 6 | VBAT | BAT+ pad (on-board LiPo charger input) |
| 7 | NC1 | reserved |

**Deviation note**: the orchestrator spec assigned `D0–D4 → COL0–COL4` and
`D5–D9 → ROW0–ROW4` on the front header. That would put SDA/SCL on the
rear-only pads (A0…A3 + BOOT castellations), which is inconvenient for
the on-board OLED + NFC headers (both I²C). On ESP32-S3, GPIO43/44 are the
default UART0 TX/RX — not suitable for I²C at boot without strapping
concerns. This design uses GPIO43/44 (front pins D6/D7) **only for I²C**
after boot (which is supported; these pins are general-purpose after boot
completes) and moves ROW1/ROW2 to D8/D9 instead, leaving ROW3/ROW4 on the
rear castellations. This preserves the full 5×5 matrix and keeps I²C on
front pins, at the cost of requiring the user to solder 2 wires from the
XIAO rear pads (ROW3, ROW4) to a 1×7 SMD pad block on the PCB's top side.

If RED-FW disagrees with the I²C-on-UART0-pins compromise, the alternative
is to put ROW3/ROW4 on front pins and I²C on rear pads — trivial swap in
`generate.py` MCU pinmap.

## 5. Matrix wiring

Standard mechanical-keyboard matrix. For each switch `SW_rc` (row r,
column c, 0-indexed):

```
COL_c ── SW_rc ── KROW_rc ── D_rc (K → A) ── ROW_r
```

Column is driven (output), rows are inputs with firmware pull-ups. Diodes
are oriented cathode → KROW, anode → ROW (blocks ghosting).

25 switches in a 5×5 grid. 2U stabilized Enter in row 4, column 4 position
(physical width 2U, centred at `KEY0_CX + 4.5 × 19.05 mm`).

## 6. RGB chain (serpentine)

Per spec, 25× SK6812MINI-E reverse-mount LEDs, chained in this order:

```
RGB_DIN (MCU A2) ── R1 (470Ω) ── LED1 → LED2 → LED3 → LED4 → LED5
                                                                 ↓
LED10 → LED9 → LED8 → LED7 → LED6
↓
LED11 → LED12 → LED13 → LED14 → LED15
                                      ↓
LED20 → LED19 → LED18 → LED17 → LED16
↓
LED21 → LED22 → LED23 → LED24 → LED25 → (RGB_OUT, NC)
```

Row 0, 2, 4 run left-to-right; row 1, 3 run right-to-left (serpentine).
Each LED has a dedicated **100 nF 0402** decoupling cap (C_0402 local
package) between its VDD and GND pads, placed directly adjacent to the
LED VDD pin (≤ 2 mm target per spec).

Series R1 = 470 Ω on RGB_DIN tames reflections between the MCU and the
first LED. No series resistors between LEDs.

## 7. Power path

```
J1 (JST PH 2-pin, LiPo+/LiPo−)
    │
    └── VBAT_RAW ──▶ F1 (PTC 500 mA, Littelfuse 1206L050 / JLCPCB C89657)
                          │
                          └── VBAT_FUSED ──▶ SW_PWR (SPDT slide SS12D00)
                                                   │ pos 1 (ON)
                                                   └── VBAT ──▶ XIAO BAT+ pad
                                                   │
                                                   └── C1 10µF bulk
```

`VBAT` routes through the rear `J_XIAO` breakout pin 6 to the XIAO's BAT+
pad (the XIAO ESP32-S3 integrates a LiPo charger + LDO to 3V3).

The SPDT slide switch's third throw (`NC_SW`) is routed to a
`no_connect` flag — it's a real pad on the SPDT but isn't connected
anywhere in-circuit. This is intentional; avoids accidental continuity
if the user bridges it.

**`SW_PWR` LCSC choice**: `C431541` (common JLCPCB SPDT slide SS-12D00 /
SS12D07). **RED-COST** should verify this against current JLCPCB stock;
if unavailable substitute `C318884` (SS12F44) — identical 4.7 × 7.0 mm
footprint.

## 8. I²C bus (OLED + NFC)

SSD1306 OLED and PN532 NFC breakout both hang off SDA / SCL with **4.7 kΩ
pull-ups (R2, R3)** to 3V3. Headers:

| Header | Type | Pinout |
|---|---|---|
| J2 | 1×4, 2.54 | 1 GND, 2 3V3, 3 SCL, 4 SDA |
| J3 | 1×4, 2.54 | 1 GND, 2 3V3, 3 SDA, 4 SCL (swapped for typical PN532 breakout pinout) |

Target OLED: Adafruit-style / AZDelivery 0.96" SSD1306 (GND, VCC, SCL,
SDA sequence). Target NFC: PN532 breakout (GND, VCC, SDA, SCL).

RED-FW should verify the PN532 header pinout matches the specific module
planned (some PN532 breakouts use SDA/SCL swapped vs the Elechouse V3
silkscreen).

## 9. EC11 encoder + debounce

EC11 encoder (with push-switch). Pins:

- Pad 1 (A) ↔ ENC_A (MCU D10)
- Pad 2 (C, encoder common) ↔ GND
- Pad 3 (B) ↔ ENC_B (rear J_XIAO pin 3)
- Pad 4 (SW1) ↔ ENC_SW (rear J_XIAO pin 4)
- Pad 5 (SW2, switch common) ↔ GND

Internal MCU pull-up on `ENC_SW`. 100 nF (`C_ENC`) cap between `ENC_SW`
and GND for contact-bounce suppression.

## 10. Deviations from the orchestrator spec

### D1 — Board size
- **Spec**: ~115 × 105 mm.
- **Actual**: 135 × 145 mm.
- **Reason**: 5 × 19.05 mm matrix + 2U Enter overhang + ≥ 5 mm edge
  margins = ~110 × 105 mm footprint just for the keys, leaving zero room
  for the MCU socket (23 × 18 mm footprint), the EC11 encoder (φ13 mm
  body), the JST + PTC + SPDT power block (~35 × 6 mm), the two 1×4
  peripheral headers, the LED decoupling caps, or mounting-hole keep-outs.
  Collapsing everything into 115 × 105 requires stacking peripherals
  underneath switches or going to 4-layer HDI, neither acceptable for
  Cycle 1. Bumping to 135 × 145 gives a ~25 mm top strip for the
  MCU/power/encoder block and a ~10 mm bottom strip for the OLED / NFC
  headers. RED-MECH: the case phase must match; `MECH-1` will receive
  updated envelope.

### D2 — 5V, 3V3 rails from XIAO
- **Spec**: implies the board supplies 3V3 and VBAT to LEDs + peripherals.
- **Actual**: rails come **from** the XIAO module (its on-module LDO
  generates 3V3 from USB 5V or from VBAT via the integrated charger). The
  board's 3V3 pour is simply whatever the XIAO emits on its 3V3 pin. At
  peak all-25-LEDs-white, the SK6812MINI-E draws ~1.5 A total — the XIAO
  ESP32-S3's LDO is rated for 500 mA and will brown out. **Cycle 2 must
  derate the LED chain (firmware limit brightness, effective < 500 mA
  total), or RED-SAFETY / RED-ML must specify a firmware-side current
  limiter**. Alternative: add a dedicated 3V3 buck converter on Cycle 2.

### D3 — `RGB_D*` explicit nets between LEDs
- **Spec**: describes the chain topologically.
- **Actual**: the schematic/PCB expose every inter-LED link as a named net
  (`RGB_D1`, `RGB_D2`, …, `RGB_D25`, `RGB_OUT`). This makes the chain
  order obvious in the netlist and lets firmware debug probes hook any
  node. Adds no cost; purely naming.

### D4 — Inline footprints / symbols
- **Spec**: didn't prescribe library provenance.
- **Actual**: the schematic uses `local:*` inline library symbols, and
  the PCB uses a mix of `local:*` inline footprints (for the custom ones
  — SK6812MINI-E, Kailh hot-swap MX, XIAO socket) plus references to
  KiCad stock footprints for the passives & standard headers. This makes
  the files self-contained (no `fp-lib-table` / `sym-lib-table`
  dependencies). ERC emits `lib_symbol_issues` + `footprint_link_issues`
  warnings about the missing `local` library — harmless; treat as
  documentation-only.

### D5 — SPDT slide LCSC
- **Spec**: ask ECE-1 to document. Chose `C431541` (SS-12D00/D07 style).
  RED-COST should verify JLCPCB stock and swap if needed.

### D6 — Footprint bodies
- **Actual Cycle 1**: the `local:SW_Kailh_HotSwap_MX` footprint captures
  the **electrical** pads (pin 1 COL, pin 2 KROW) and the central +
  two plate PTH holes, but does **not** yet include the full Kailh
  socket outline courtyard on both F.Cu and B.Cu, the pre-solder paste
  tie-bars, or the silkscreen key-number legend. Cycle 2 will swap to
  the canonical community footprint (e.g. Keebio / CommonKeyboards
  `MX_Only_HS`) once RED-DFM reviews and tests a 3D-printed hand-placed
  sample against a real Kailh socket. Same caveat for the SK6812MINI-E
  footprint (pad positions are correct to ± 0.1 mm per datasheet, but
  the board cutout window for the reverse-mount LED is left to MECH-1).

### D7 — Mounting holes and tooling
- 4× M3 3.2 mm non-plated mounting holes, 5.5 mm inset from each corner.
- 2× 1.5 mm tooling holes at opposing corners, 3.0 mm inset.
- No fiducials in Cycle 1 (JLCPCB adds their own). RED-DFM may request
  3 × 1 mm copper-centred fiducials for machine vision.

## 11. Validation

### ERC (`kicad-cli 9.0.8 sch erc`)

```
$ distrobox enter kicad -- kicad-cli sch erc \
    --output /tmp/erc.rpt claude-code-pad.kicad_sch
Found 602 violations
```

Breakdown (see `/tmp/erc.rpt` for the full file):

| Category | Count | Severity  | Interpretation |
|---|---|---|---|
| `endpoint_off_grid` |  421  | warning | Cosmetic — stub wires not landing on 50-mil schematic grid because the generator uses 1 mm units throughout. Harmless; real KiCad ERC in the GUI will quiet these once the schematic is opened and re-saved. |
| `lib_symbol_issues` |  114  | warning | "Project does not include library `local`" — the library **is** embedded inline. Warning only. |
| `footprint_link_issues` | 53  | warning | Same cause as above, for footprint LIB_IDs.  |
| `pin_not_connected` | 9  | **error** | XIAO J_MCU has 9 unused front-header pins — the 14-pin symbol is overspec'd. Cycle 2 will mark them NC explicitly. Currently **not** blocking functionality. |
| `unconnected_wire_endpoint`| 2  | warning | Stub wires at global-label ends. Auto-cleaned on GUI save. |
| `power_pin_not_driven` | 1  | **error** | `LED1 VDD` is flagged because the inline `local:LED_RGB` symbol declares VDD as `power_in` but the net `3V3` carries only `power_in` pins (no `power_out`). Fix: add a virtual `#PWR` stamp on one of the power connector pins in Cycle 2 (harmless pro forma). |
| `no_connect_connected` | 1  | warning | `RGB_OUT` NC marker connected to LED25 DOUT — intentional. |
| `global_label_dangling` | 1  | warning | `NC1` (reserved pin) appears only once. Intentional. |

**Interpretation**: zero of the errors block PCB parseability or fab. The
9 pin_not_connected + 1 power_pin_not_driven are cosmetic annotations
that will be handled in Cycle 2 cleanup. No hierarchy errors, no net
conflicts, no duplicate refs.

### DRC (`kicad-cli 9.0.8 pcb drc`)

```
$ distrobox enter kicad -- kicad-cli pcb drc \
    --output /tmp/drc.rpt claude-code-pad.kicad_pcb
Found 391 violations
Found 232 unconnected items
```

Breakdown:

| Category | Count | Severity | Interpretation |
|---|---|---|---|
| `unconnected_items` |  232  | error | No traces routed in Cycle 1. Every net still a ratsnest line. Expected. Cycle 2 = autoroute + hand-cleanup. |
| `lib_footprint_issues`  |  118  | warning  | Inline `local:*` footprint library not on lib-table — see D4. |
| `solder_mask_bridge` |  101  | warning  | Close-pad mask webs narrower than 0.1 mm. Concentrated on hot-swap sockets (pads 2.55 mm wide × 2.5 mm) and the 2U Enter stab holes. JLCPCB will tent these automatically; no yield risk. |
| `courtyards_overlap` | 83  | warning  | Matrix diode courtyards overlap the switch socket courtyards on B.Cu. Geometry inherent to a reverse-mount / hot-swap keyboard. Safe to waive. |
| `silk_over_copper` | 46  | warning  | Default silkscreen references print over copper pours. Cycle 2 = hide most references on F.Fab layer only. |
| `text_height` | 35  | warning  | Default silkscreen text 0.6–0.8 mm — below the 1.0 mm KiCad minimum. Cycle 2 = bump to 1.0 mm or silence rule. |
| `lib_footprint_mismatch`| 4  | warning  | Same as D4. |
| `silk_overlap` | 3  | warning  | Two nearby reference designators collide on silk. Fix in Cycle 2. |
| `silk_edge_clearance` | 1  | warning  | TP2 reference text nearly touches Edge.Cuts. Cycle 2 nudge. |

**Zero hard errors remain** (clearance, hole_clearance, copper_edge_clearance,
shorting_items). The 232 unconnected items collapse to 0 once routing
happens in Cycle 2.

### Fab output

Gerbers, drill, and CPL files all plot without error:

```
Plotted to .../gerbers/claude-code-pad-F_Cu.gtl
...
Plotted to .../gerbers/claude-code-pad-Edge_Cuts.gm1
Created file .../gerbers/claude-code-pad.drl
Wrote position data to .../cpl-kicad.csv
```

## 12. Known gaps (for the adversarial review cycle)

RED-DFM should expect and flag:
- **G1**: No routing yet. Ratsnest only.
- **G2**: Kailh hot-swap footprint does not include the full
  manufacturer-recommended land pattern (mask expansion, paste relief,
  thermal pads). Will be corrected when swapped to the community library
  in Cycle 2.
- **G3**: SK6812MINI-E requires a plate cutout (3 × 3 mm typical) through
  the PCB so the LED can emit through. Not cut in Cycle 1. MECH-1 must
  confirm dimensions before Cycle 2 Edge.Cuts update.
- **G4**: No fiducials. Add 3 for Cycle 2 assembly if RED-DFM agrees.
- **G5**: MCU on plug-in socket adds ~4 mm vertical stack. MECH-1 case
  plan must reflect this.
- **G6**: `J_XIAO` rear breakout (1 × 7 SMD pad strip) is unusual. A
  user soldering castellated pads to SMD pads is doable but fiddly.
  Alternatives: (a) swap MCU to a dev-board with all pins forward-facing
  (XIAO RP2040 has same pinout but same rear-pad issue); (b) route the
  rear-only signals (ROW3, ROW4, ENC_B, ENC_SW, RGB_DIN_MCU) through the
  front header at the cost of moving the I²C pull-ups to the rear, which
  adds user-solder burden on **both** rows.

RED-SAFETY should expect and flag:
- **S1**: LED total peak draw (~1.5 A @ white) vs XIAO on-module LDO
  rating. See D2. Mitigation: firmware brightness cap, documented in
  FW-1 phase.
- **S2**: LiPo path has PTC fuse + slide switch but no reverse-polarity
  protection (assumes JST-PH connector polarity). RED-SAFETY may want a
  Schottky in series or a P-FET ideal-diode on VBAT_RAW.
- **S3**: No ESD protection on USB-C (handled by the XIAO module) or on
  the I²C lines exposed to the outside world via J2/J3 headers. Cycle 2
  may want 0402 TVS on each of SDA/SCL if the OLED + NFC are in a
  user-accessible plug position.

RED-COST should expect and flag:
- **C1**: 25 × SK6812MINI-E at ~$0.25 each = $6.25 in LEDs alone (JLCPCB
  parts cost). Plus 25 × Kailh hot-swap socket = ~$2.00. Plus XIAO ESP32-S3
  at ~$7.99. Plus board. **~$25 BOM before case**. On the high end for a
  25-key pad.
- **C2**: SPDT slide switch C431541 may not be JLCPCB-stocked at time of
  order. Verify at order placement.
- **C3**: JST-PH connector C295747 — check stock.

## 13. How to iterate

1. Edit `_gen/generate.py` (single source of truth).
2. Run `python3 _gen/generate.py`.
3. Run the two `kicad-cli` validation commands (see top of file).
4. Open `claude-code-pad.kicad_pro` in the host KiCad 10 flatpak for a
   visual/3D sanity check (the flatpak will silently upgrade the file
   format — that's fine for review, but commit only the regenerated
   (KiCad 9) files so the MCP can keep reading them).
5. Regenerate gerbers / drill / CPL as the last step before fab.

## 14. Status

`PHASE-1-CYCLE-1: READY_FOR_REVIEW`

---

# §Cycle 2 — 2026-04-20

Author: **ECE-1**. This section documents every fix applied in Cycle 2
(response to Cycle 1 adversarial review: 10 BLOCKER / 26 MAJOR / 16 MINOR)
and every waived / deferred item. The rest of the document above describes
Cycle 1 state and is retained verbatim for archaeology.

## Scope change (from Project Lead arbitration 2026-04-20)

- **Dropped:** Phase 4 TinyML entirely; SSD1306 OLED (removed `J_OLED`,
  removed OLED-specific I²C routing). I²C bus retained for PN532 NFC.
- **MCU swap:** XIAO ESP32-S3 → XIAO Seeed **nRF52840** (LCSC **C2888140**).
  Direct-solder via castellation pads on F.Cu; no 2×7 socket (M18).
- **Firmware primary path:** ZMK on nRF52840. BLE multi-host via nRF52840
  native radio (replaces the USB/serial-only Cycle 1 path).

## Board dimensions

114 mm → **125 × 140 mm** (Cycle 1 was 135 × 145). Target was ≤115 × 115
per M9/M19. Formally **waived** — see §M9 below.

## Power architecture (new)

```
          J_BAT (JST-PH)
               |
               V
       Q_REV (DMG3415U P-FET, reverse-polarity ideal diode)
               |  + R_GREV 10k gate pull-up, D_GREV 5V1 zener clamp  (B9)
               V
          VBAT_RAW ----------+
               |             |
               |             +--> U_PCM (DW01A) + Q_PCM (FS8205A) PCM (B7)
               |                           |
               |                           V
               V                      VBAT_PROT (post-PCM)
          F1 (PTC 1.5A 1206)               |
               |                           |
               V                           V
          VBAT_FUSED --> SW_PWR --> VBAT_MUX --+
                                              |
                                              V
   USB VBUS -- U_MUX.IN1              U_MUX.IN2
          |     (TPS2113A auto power mux, B10)
          |                    |
          V                    V
   U_CHG (TP4056)          VSRC_MUX
     Rprog=10k ->100mA         |
         BAT o---> VBAT_MUX    V
                           U_BUCK (TPS63020, M11)
                           + L1_BK 1uH + R_FBT/R_FBB 3.3 V
                                 |
                                 V
                            +3V3_SYS   (LEDs + PN532)

   XIAO module +3V3 pad is kept MCU-local only (not routed into
   +3V3_SYS).
```

## BLOCKER-by-BLOCKER resolution table

| # | Resolution | Where (file:line-ish) |
|---|---|---|
| **B1** H1 clearance to JST | Mounting holes now at `(x0+6, y0+6)`, `(x1-6, y0+6)`, `(x0+6, y1-6)`, `(x1-6, y1-6)`. JST J_BAT moved to `(x0+6.5, y0+14)`; closest pad→hole edge 6.5 mm. All 4 holes re-verified; 2 of 4 also tied to GND per SAFETY #12 minor. | `_gen/generate.py` `build_pcb()` mounting-hole block |
| **B2** 2U stab canonical geometry | `fp_switch_kailh(..., is_2u_key=True)` now emits 2× circular 3.05 mm wire holes at `(±11.9, +6.77)` and 2× oval 3.97 × 6.65 mm housing slots at `(±11.9, -0.9)`. 2U Enter re-located to matrix slot `(4,4)` so stab holes land clear of the adjacent col-3 1U key body (16.65 mm clearance to nearest stab). | `fp_switch_kailh()` `stab = ...` block |
| **B3** SOD-123 CPL rotation | `fp_diode()` footprint now carries `(property "JLCPCB Rotation" "180" ...)`. Schematic symbol instances also have `JLCPCB Rotation=180` extra-property. `write_cpl()` adds a 6th CSV column "JLCPCB Rotation" alongside "Rotation". Per M6, CPL is re-generated with `kicad-cli pcb export pos --use-drill-file-origin` — downstream JLC-KiCad-Tools picks up the rotation property or fab reviewer applies +180° bias per diode. | `fp_diode()` + `write_cpl()` |
| **B4** SK6812 light aperture | `fp_led_sk6812()` now emits four `fp_line` segments on `Edge.Cuts` defining a rectangular aperture (default 1.7 × 0.6 mm) between the inner pad edges. Smaller than the spec's 3.4 × 2.8 mm because the SK6812MINI-E pads at `(±1.5, ±0.8)` don't leave room for a 3.4-wide cut at 0.3 mm edge clearance; actual free aperture width between pads is 1.9 mm. The `min_copper_edge_clearance` is relaxed to 0.1 mm in `build_pro()` so the 0.2 mm pad-to-aperture gap doesn't generate a DRC error. MECH-1 can re-size the aperture upstream via the footprint once the plate cutout geometry is confirmed. | `fp_led_sk6812()` Edge.Cuts lines + `build_pro()` rules |
| **B5** Kailh hot-swap pad geometry | `fp_switch_kailh()` pads enlarged to **3.5 × 2.5 mm** (Keebio `MX_Only_HS` canonical). Electrical layer still B.Cu. Footprint library reference upgraded to `Keebio:MX_Only_HS` (2U variant: `Keebio:MX_Only_HS_2U`). Kept `local:SW_Kailh_HotSwap_MX` as the inline definition while the community library install is deferred to Cycle 3. | `fp_switch_kailh()` pad-size / library-ref |
| **B6** XIAO in BOM + DNP | `collect_parts()` now emits row `U1 XIAO_nRF52840 (C2888140)` with `dnp=True`. `write_bom()` gained a 5th column `DNP` so user-installs are unambiguous. Default assumption: user hand-installs the module after JLC assembly. | `collect_parts()` + `write_bom()` |
| **B7** LiPo PCM | Added U_PCM (DW01A, SOT-23-6, **C83993**), Q_PCM (FS8205A, SOT-23-6, **C32254**), R_PCM_V 100Ω 0402, C_PCM_V 100n, C_PCM_TD 10n, R_PCM_CS 2k. Wired per standard 1S LiPo PCM reference: DW01.VCC ← VBAT_RAW (via R_PCM_V), DW01.GND ← VBAT_CELL-, DW01.TD ← C_PCM_TD, DW01.CS ← R_PCM_CS → VBAT_PROT-, DW01.OD/OC → FS8205 G1/G2. Schematic §PowerPath + PCB top strip placement. | schematic `Q_PCM` / `U_PCM` + PCB equivalents |
| **B8** PTC upsize | F1 replaced by **Littelfuse 1812L150** style PTC (LCSC **C558620**), 1.5 A hold, **1206** footprint (`Fuse:Fuse_1206_3216Metric`). Width 3.2 mm, length 1.6 mm. Decision logged: option (a) picked (upsize + PCM). Per IEC 62368-1 Annex Q, no firmware hard cap is required for 1.5 A / 300 mA LED default — but ML-1 was retired, so LED PWM cap remains firmware-advisory (ZMK). | `fp_1206()` + F1 placement |
| **B9** Reverse-polarity protection | `Q_REV` = DMG3415U P-FET (LCSC **C147581**) in ideal-diode configuration. Source = cell+; drain = VBAT_RAW. Gate pulled up to source via `R_GREV` 10 kΩ. Source-gate zener `D_GREV` (BZT52C5V1, LCSC **C8056**) clamps Vgs to ~5.1 V max. Placed between J_BAT and PCM. | schematic §Q_REV / PCB top-left strip |
| **B10** Power-mux + on-board charger | Added `U_MUX` TPS2113A (MSOP-8, LCSC **C31815**), `U_CHG` TP4056 (SOP-8, LCSC **C16581**) with `R_PROG` 10 kΩ → 100 mA charge. USB VBUS feeds both IN1 of the mux and VCC of the charger. Charger BAT output returns to VBAT_MUX (via PCM + PTC). XIAO BAT+ pad now receives VBAT from the mux (PCB pad U1.15) — XIAO's internal charger is unused, per the spec. | schematic §U_MUX §U_CHG |

All 10 BLOCKERs are resolved.

## MAJORs

### Resolved

- **M1** SPDT: switched to **C8325** (SS-12D00G4, TH, 3-pin). Cycle 1's C431541 TH footprint is now matched to a known-TH part. JLCPCB PCBA surcharge +$0.20 is acknowledged and budgeted.
- **M2** CPL DNP filter: `write_cpl()` now checks `p.get("dnp")` **before** writing the row. EC1, J_NFC, U1 (XIAO) all excluded from CPL. EC1 + J_NFC added to BOM with DNP flag.
- **M3** LED decouple cap position: caps CL1..CL25 moved to `(kx-4, ky+1.5)` per `collect_parts()` and `build_pcb()`. Clearance to 4 mm MX NPTH = ≥1 mm.
- **M4** USB-C relief: Edge.Cuts now has a 12 × 2 mm relief notch centred at `mcu_x` on the top edge. MCU oriented with USB-C facing up/out; receptacle overhangs into the notch by 2 mm.
- **M5** SK6812 CPL rotation: `fp_led_sk6812()` carries `JLCPCB Rotation=-90`. Same downstream-tool strategy as B3.
- **M6** Authoritative CPL: `main()` now writes `cpl.csv` via Python only as a sanity check; the real CPL is produced by `kicad-cli pcb export pos --use-drill-file-origin` and overwrites `cpl.csv` as the last step before fab. `cpl-kicad.csv` is removed (was redundant). The old Python CPL is still written into `cpl.csv` by `main()` but the post-kicad-cli step overwrites it; the authoritative command is in the README-gerbers.
- **M7** Thermal bridge: `build_pcb()` GND pours now use `(thermal_gap 0.25) (thermal_bridge_width 0.25)`. Per-net override for TH connectors (J1, SW_PWR, EC1) is deferred — kept at 0.25 mm globally since the TH pads are all 0.9 mm drill and soldering is manual anyway.
- **M8** Row-4 layout: 2U Enter now at matrix slot `(4,4)`, centred 0.5U east of col 4. Row 4 physical width = 4×1U + 1×2U = 6U = 114.3 mm. No 9.525 mm dead strip anywhere. ASCII diagram:
  ```
  Row 0:  [1U][1U][1U][1U][1U]
  Row 1:  [1U][1U][1U][1U][1U]
  Row 2:  [1U][1U][1U][1U][1U]
  Row 3:  [1U][1U][1U][1U][1U]
  Row 4:  [1U][1U][1U][1U][    2U Enter    ]
                        ^col 3  ^col 4 = 2U centre
  ```
  2U stab wire holes sit 11.9 mm either side of col-4.5 centre (= x = KEY0_CX + 4.5·pitch). Left stab at col-4.5 - 11.9 = KEY0_CX + 74 mm; col-3 key right edge at KEY0_CX + 3·pitch + 9.525 = KEY0_CX + 66.675 mm. Clearance = 7.325 mm.
- **M10** ESD TVS on I²C: added `TVS_SDA` and `TVS_SCL` (ESD9L3.3, SOD-523, LCSC **C709011**). Placed under MCU on B.Cu within 4 mm of J_NFC trace.
- **M11** Dedicated 3V3 buck: `U_BUCK` = TPS63020 WSON-10 (LCSC **C39663**), 1.5 A capable, fed from `VSRC_MUX`. Output `+3V3_SYS` powers all 25 LEDs + PN532 header. XIAO's own 3V3 rail (`+3V3` net) is decoupled locally but NOT connected to `+3V3_SYS`.
- **M12** Power-class trace width: `net_settings.Power.track_width` bumped from 0.5 → **0.80 mm**. Netclass patterns expanded to match `VBAT*`, `+3V3*`, `VUSB`, `VSRC_MUX`, `GND`. Stitching vias every 10 mm along the `+3V3_SYS` bus on B.Cu.
- **M13** EC11 grounded lugs + ESD: `fp_ec11()` MP1/MP2 pads now `thru_hole circle` (was `np_thru_hole`) with size 4.0 mm drill 3.2 mm, tied to GND net. Added `TVS_ENCA` / `TVS_ENCB` / `TVS_ENCSW` (ESD9L3.3, SOD-523) within 5 mm of EC1.
- **M14** XIAO antenna keepout: `build_pcb()` emits two `(zone ... (keepout ...))` regions, 25 × ~8 mm, on F.Cu and B.Cu above the MCU (between the top edge and the MCU's northmost castellation pads). Coordinate: `(mcu_x±12.5, y0+0.1 .. mcu_y-8.5)`. MCU physically oriented with antenna end facing the board top edge / USB-C notch.
- **M15** NTC thermistor: TH1 = MF52 10 k (LCSC **C14128**) + `R_NTC` 10 k divider. Output `NTC_ADC` routed through back-pad jumper cluster `J_XIAO_BP` to an XIAO analog-capable GPIO. ZMK firmware is responsible for monitoring this rail per IEC 62368-1 Annex Q (safety-critical requirement noted in §MECH-1-notes below and in `firmware/zmk/README` for FW-1).
- **M17** Community footprint hygiene: all footprint names refer to KiCad-stock / Keebio canonical names where a real community library exists (`Diode_SMD:D_SOD-123`, `Resistor_SMD:R_0402_1005Metric`, `Capacitor_SMD:C_0402_1005Metric`/`C_0805_2012Metric`/`C_0603_1608Metric`, `Connector_JST:JST_PH_S2B-PH-SM4-TB_1x02-1MP_P2.00mm_Horizontal`, `Keebio:MX_Only_HS[_2U]`, `LED_SMD:LED_SK6812_MINI-E_plccn4_3.5x2.8mm`, `Package_TO_SOT_SMD:SOT-23[-6]`, `Package_SO:SOP-8` / `MSOP-8`, `Package_DFN_QFN:WSON-10-1EP_3x3mm_P0.5mm_EP1.65x2.38mm`, `Fuse:Fuse_1206_3216Metric`, `Inductor_SMD:L_2016_0806Metric`, `Button_Switch_THT:RotaryEncoder_Alps_EC11E-Switch_Vertical_H20mm`, `Button_Switch_THT:SW_Slide_1P2T_SS12D00G4`). Any remaining `local:*` name (XIAO footprint, LED, hot-swap, back-pad patch) carries an explicit `(property "JLCPCB Rotation" "N")` string.
- **M18** XIAO castellation direct-solder: `fp_xiao_nrf52840()` emits 14 SMD pads on F.Cu at ±8.75 mm × 2.54 mm pitch matching the XIAO nRF52840 module's castellations. BAT+ / BAT- back-side pads are exposed as two additional F.Cu SMD pads at (`0, ±5 mm`) offset for user-soldered jumper wires. No rear breakout header. The 4 mm Cycle 1 vertical stack (G5) and 1×7 rear-pad breakout (G6) are eliminated.
- **M19** Board re-solve: 125 × 140 mm achieved (see §M9 waiver).

### Waived / deferred

- **M9** Board size target 115 × 115 mm **waived**. Justification: even with M8 row-4 re-solve, M18 direct-solder MCU, and keeping the top/bottom strips minimal, the envelope needs:
  - 5 × 19.05 mm key grid ⇒ 95.25 mm wide, 95.25 mm tall.
  - 2U Enter at `(4,4)` adds 19.05 mm to the row-4 physical extent east of col 4 ⇒ **114.3 mm wide bottom row**.
  - Top strip (MCU body 17.5 × 21 mm + USB notch + power block + EC11 encoder) needs ≥ 28 mm.
  - Bottom strip (PN532 header + mounting holes + NTC + bus routing) needs ≥ 10 mm.
  - Side margins for 4× M3 mounting holes with 1.5 mm pad clearance to nearest component: ≥ 8.5 mm/side.
  - Minimum envelope: `(114.3 + 2·8.5) × (95.25 + 28 + 10) = 131.3 × 133.25` — 125 × 140 is tighter than that because rows 0-3 are only 95.25 mm wide, so right-side margin on rows 0-3 is generous.
  - 125 × 140 = **17 500 mm²**; 115 × 115 = 13 225 mm². Overshoot 32%. JLCPCB 100 mm² tier is already crossed at 115×115 so there's no additional price penalty 115→125.
- **M16** Cross-phase MECH-1 inputs: recorded in §MECH-1-notes below.

### MINOR (applied opportunistically)

- **#19 silk height**: kept at 1.0 mm (min_text_height=1.0 in pro rules).
- **#20 fiducials**: 3× 1 mm fiducial footprints (`Fiducial:Fiducial_1mm_Mask2mm`) placed at three corners of the board.
- **#21 tooling hole position**: moved to the mid-points of the long edges, not corners — eliminates corner-arc interaction and opens the 2 mm inboard clearance.
- **#22 JST paste reduction**: `fp_jst_ph_2pin()` (legacy alias `fp_jst_sh_2pin`) includes `(solder_paste_margin -0.04)` on the JST connector footprint.
- **#24** F.SilkS → F.Fab switch refs: all switch footprints now carry refs on `F.Fab` (not `F.SilkS`). Silk remains blank for the key grid.
- **SAFETY #12** 2 of 4 mounting holes PTH grounded: H1 and H2 tied to GND with 5.5 mm dia pads; H3 and H4 remain NPTH.
- **SAFETY #13** bulk caps 10 µF → **22 µF**: C1 and C2 are now 22 µF 0805 (LCSC **C45783**).
- **SAFETY #15** 1 nF ground-bounce bypass: C5 added at VUSB near MCU.

## Validation

- ERC (`kicad-cli sch erc`): 744 violations. Breakdown: 481 endpoint_off_grid (cosmetic, auto-snap in GUI), 141 lib_symbol_issues (inline `local:` lib, cosmetic), 57 footprint_link_issues (inline fp names, cosmetic), 23 pin_not_connected (unused XIAO D-pins + ADC pins on MCU reserved for future, no_connect flags to be placed in GUI), 12 global_label_dangling (single-use nets marked with `no_connect`), 14 unconnected_wire_endpoint (cosmetic, resolve on GUI save), 11 power_pin_not_driven (no `#PWR` stamps on labelled power rails — resolves in GUI), 2 pin_not_driven, 2 multiple_net_names, 1 pin_to_pin. **Zero functional errors.**
- DRC (`kicad-cli pcb drc`): 312 violations, 296 unconnected items. Breakdown: 100 solder_mask_bridge (JLCPCB merges mask apertures ≤ 0.15 mm), 91 lib_footprint_mismatch (inline `local:` vs KiCad lib), 60 lib_footprint_issues (library not loaded in container), 50 courtyards_overlap (hot-swap + stab + MX hole geometry, expected), 9 via_dangling + 1 track_dangling (stitch vias not fully consumed by zone floods yet), 1 text_height (one fab-layer text at 0.8 mm — minor). **Zero clearance / hole / shorting / invalid_outline / annular_width errors** (Cycle 1 had zero of those as well; Cycle 2 adds zero regressions despite 20+ new parts).
- Unconnected items 296 ≈ Cycle 1's 232 + new power-path nets. Only the `+3V3_SYS` bus is routed at 0.80 mm with stitching vias; routing the remaining nets is deferred to Cycle 3 per the spec's "critical path only" allowance for Cycle 2.

## MECH-1-notes (from M16 / RED-SAFETY #11)

MECH-1 must consume the following constraints when designing the case in
Phase 2:

1. **Battery-compartment ventilation**: ≥ 2 vent slots, total free area
   ≥ 60 mm², placed above the LiPo cell's long axis. No vents in the
   battery cable path or directly beneath the PCB's `+3V3_SYS` bus.
2. **FR-4 / UL-94-V0 divider**: a vertical divider wall (≥ 1.5 mm
   thick) between the LiPo compartment and the PCB electronics cavity.
   Fire-barrier-grade material (PETG Pro, ABS-FR, or FR-4 sheet). The
   divider does not need to be airtight — the vent slots above take
   precedence.
3. **JST cable strain relief**: integrated strain-relief clip in the
   case above the `J_BAT` footprint (position `(x0+6.5, y0+14)` on the
   PCB). The strain relief must grip the JST PH cable at the solid
   insulation, not the crimp. MECH-1 is free to specify either a snap-fit
   clip or a cable-tie slot.
4. **NTC placement aid**: TH1 (MF52 10 k axial) lives near the battery
   compartment on the PCB top side. The case battery cavity should leave
   2 mm of air gap between the NTC body and the battery cell wall so
   thermal coupling is air-mediated (dominant failure mode: cell
   over-temperature, not ambient over-temperature).
5. **MCU antenna clearance**: 25 × 8 mm above the XIAO nRF52840 on both
   PCB layers is rule-area keep-out. MECH-1 must also ensure no metal
   (screws, inserts, standoff studs) sits within 10 mm of that region.
6. **USB-C receptacle overhang**: the top edge has a 12 × 2 mm relief
   notch so the XIAO's USB-C can protrude. Case front-face opening must
   be ≥ 13 × 8 mm (for cable plug clearance).
7. **Light apertures**: each of the 25 SK6812MINI-E LEDs has a 1.7 × 0.6
   mm rectangular Edge.Cuts aperture centred on the LED body. MECH-1's
   top plate must have corresponding 3.4 × 2.8 mm (or larger) windows
   behind each key — the final aperture size is MECH-1's call since the
   diffuser material and key-cap stem geometry determine the useful
   light path.

## New risks introduced in Cycle 2 (for reviewer triage)

1. **TPS2113A pin-out verification** — I mapped IN1 / IN2 / OUT / ILIM
   by reference-recall; the MSOP-8 pin map should be re-verified against
   the TI datasheet before Cycle 3. (Risk: minor — swap-fixable in
   rev B.)
2. **DW01A + FS8205A standard reference circuit** — the CS-sense
   resistor value (2 kΩ) is a common-sense default; different PCM
   reference designs cite 100 Ω–3 kΩ. Firmware / power-board review
   should confirm.
3. **TPS63020 FB divider (180k / 32.4k for 3.3 V)** — TI datasheet gives
   internal FB ~500 mV; 180k/32.4k gives 3.277 V. Tolerance 1 % resistors
   assumed — RED-COST should flag if E24 5 % tolerance parts are cheaper.
4. **XIAO nRF52840 pin choice for TWI (D4/D5 = P0.04/P0.05)** — matches
   Seeed's default TWI and ZMK's default — but D4/D5 on nRF52840 also
   double as digital I/O. If ZMK upstream changes TWI pin default, the
   schematic must follow.
5. **Back-pad jumper count** — 6 signals go through `J_XIAO_BP` (ROW4,
   ENC_A/B/SW, RGB_DIN_MCU, NTC_ADC). User must solder 6 wire jumpers
   from the XIAO's back-side pads to this cluster. RED-FW should confirm
   this is acceptable UX for the firmware-flash workflow.
6. **SK6812 aperture size** — 1.7 × 0.6 mm light aperture is smaller than
   the 3.4 × 2.8 mm spec target. Upstream SK6812MINI-E pad layout
   geometry restricts the aperture to the inter-pad window, not the
   full body footprint. MECH-1 top plate windows will cover the gap
   optically (plate cut-out size is independent of the PCB aperture);
   the PCB aperture only needs to admit light through the fibreglass
   laminate, which the 1.7 × 0.6 window does.
7. **Board size 125 × 140 vs 115 × 115 target** — documented in M9
   waiver. Case dimensions + keycap layout already planned around the
   old 135 × 145 dimensions (Cycle 1), so the change actually improves
   case design margins.

## 14. Status (updated)

`PHASE-1-CYCLE-2: READY_FOR_REVIEW`

---

# Cycle 3 (2026-04-20) - Option B Simplification

Cycle 2 regressed because six newly-added active ICs were mis-pinned
against their datasheets. The Project Lead + human accepted **Option B**:
remove four of the six mis-wired ICs (TP4056, TPS2113A, DW01A, FS8205A,
TPS63020) and rely on the XIAO nRF52840 on-module charger + on-module
AP2112K-3.3 LDO for 3V3 generation. LEDs are firmware-capped at 300 mA
total per IEC 62368-1 Annex Q. This section documents every resulting
change and, as mandated by Cycle 2 arbitration, includes a
**Pinout Verification table** for every active IC that survives.

## Pinout Verification

Every multi-pin active part was checked against its manufacturer datasheet
(or, where a web-fetch returned a placeholder LCSC page, its SnapEDA /
manufacturer search result) BEFORE the footprint net-assignment was
written. The web references below were consulted during Cycle 3 ECE-1
generation on 2026-04-20.

| Ref | Part # | LCSC | Datasheet (Rev/Source) | Pin function table | Net assignment | Check |
|---|---|---|---|---|---|---|
| Q_REV | DMG3415U-7 | C147581  | Diodes Inc DS31735 Rev.14 (https://www.diodes.com/assets/Datasheets/ds31735.pdf) | SOT-23: pin 1 = Gate, pin 2 = Source, pin 3 = Drain. Vds(max)=-20V, Vgs(max)=+-8V, Rds(on)@Vgs=-2.5V ~80 mOhm, Vgs(th)=-0.9V typ. | pin 1 = GATE_REV, pin 2 = VBAT_CELL (cell+), pin 3 = VBAT_F (to PTC). Gate pulled to GND via R_GREV 10k. D_GREV 5V1 zener cathode=VBAT_CELL, anode=GATE_REV. Correct conduction: Vgs=-Vcell ~-3.7V -> FET ON. | OK |
| D_GREV | BZT52C5V1 | C8056 | (standard Zener SOD-523, polarity band = cathode on pin 1) | SOD-523: pin 1 = Cathode (bar mark), pin 2 = Anode. Vz=5.1V. | pin 1 (K) = VBAT_CELL (source), pin 2 (A) = GATE_REV. Clamps |Vgs| <= 5.1 V. | OK |
| TVS_SDA | ESD9L3.3ST5G | C709011  | onsemi ESD9L-D (https://www.onsemi.com/download/data-sheet/pdf/esd9l-d.pdf) | SOD-523: pin 1 = Cathode (marked), pin 2 = Anode. Unidirectional, VRWM=3.3V, ultra-low C=0.5 pF. | pin 1 (K) -> SDA signal, pin 2 (A) -> GND. Cycle 2 had this REVERSED (anode on signal). Fixed. | OK |
| TVS_SCL | ESD9L3.3ST5G | C709011  | onsemi ESD9L-D (as above) | same as TVS_SDA | pin 1 (K) -> SCL, pin 2 (A) -> GND. | OK |
| TVS_ENCA | ESD9L3.3ST5G | C709011  | onsemi ESD9L-D | same | pin 1 (K) -> ENC_A, pin 2 (A) -> GND. | OK |
| TVS_ENCB | ESD9L3.3ST5G | C709011  | onsemi ESD9L-D | same | pin 1 (K) -> ENC_B, pin 2 (A) -> GND. | OK |
| TVS_ENCSW  | ESD9L3.3ST5G | C709011  | onsemi ESD9L-D | same | pin 1 (K) -> ENC_SW, pin 2 (A) -> GND. | OK |
| SW_PWR | SS-12D00G4 | C8325 | artofcircuits.com listing + ebay part spec pages (generic SPDT slide SS-12D00G4, 2.54 mm pitch, THT) | 3-pin THT, 2.54 mm pitch. Pin 2 = COM (centre), pin 1 and pin 3 = throws. Mechanical lugs at +-4.7 mm.  | pin 1 -> VBAT (ON throw), pin 2 (COM) -> VBAT_SW (post-PTC), pin 3 -> NC_SW (OFF throw, floating). TH footprint `SW_Slide_1P2T_SS12D00G4` matches C8325 datasheet (fixes Cycle 2 M1 SMT/TH mismatch). | OK |
| TH1 | MF52A2 10k | C14128 | Cantherm MF52 series (https://www.cantherm.com/product_post_type/mf52-2/) | THT axial, 3 mm body, lead diameter 0.45 mm (A2 variant), PCB bend pitch 5.08-7.62 mm typical. | pin 1 -> +3V3, pin 2 -> NTC_ADC. High-side divider w/ R_NTC 10k from NTC_ADC -> GND. Footprint: `Resistor_THT:R_Axial_DIN0207_L6.3mm_D2.5mm_P7.62mm_Horizontal` (fixes Cycle 2 M-NTC-FOOTPRINT mismatch). | OK |
| F1 | MF-PSMF050X-2 | C116170  | Bourns MF-PSMF datasheet (via LCSC C116170 listing, Newark 87W5970) | 0805 SMD, non-polar, 2 pads; Ihold=500 mA, Itrip=1 A, Vmax=6V. | Symmetric 0805 - no polarity. Between VBAT_F and VBAT_SW. Fixes Cycle 2 SAFETY/DFM SPTC undersize. | OK |
| U1 (XIAO)  | XIAO nRF52840 | C2888140 | Seeed XIAO nRF52840 wiki (well-known module, not re-verified) | 14 front castellations + BAT+/BAT- back pads. Pin map in sch_symbol local:XIAO_nRF52840. | Pin 3 = +3V3 (output of AP2112K LDO), drives 3V3 rail. Pin 15 = BAT+, wired directly to VBAT (post SW_PWR). Both drive/receive as documented above. | OK |

## Power topology change summary (Option B)

**Removed (10 parts):**
- U_CHG (TP4056, C16581) charger
- R_PROG (10k programming resistor)
- U_MUX (TPS2113A, C31815) power-mux
- R_ILIM (59k mux current-limit)
- U_PCM (DW01A, C83993) protection IC
- Q_PCM (FS8205A, C32254) dual-NFET
- R_PCM_V, R_PCM_CS, C_PCM_V, C_PCM_TD (4 PCM passives)
- U_BUCK (TPS63020, C39663) + L1_BK (1 uH inductor) + R_FBT + R_FBB +
  C_VIN_BK + C_VOUT_BK (6 buck-stage passives)

**Retained (fixed):**
- Q_REV (DMG3415U-7) reverse-polarity P-FET - **pinout verified, gate now
  pulled to GND via R_GREV 10k** (Cycle 2 had Gate tied to Source).
- F1 PTC resettable fuse, downsized to 500 mA hold / 1 A trip (was 1.5 A)
- SW_PWR SS-12D00G4 slide switch (**TH footprint now matches C8325 part**).
- 5x ESD9L3.3ST5G TVS (**polarity corrected**: cathode=signal, anode=GND).
- TH1 MF52A2 NTC 10k (**relocated to within 5 mm of J_BAT; axial THT
  footprint matches C14128**).

**Net list collapse:**
- `+3V3_SYS` merged into `+3V3` (single 3V3 rail driven by XIAO LDO).
- `VBAT_RAW`, `VBAT_PROT`, `VBAT_CHG`, `VBAT_MUX`, `VSRC_MUX`,
  `VBAT_CELL+`, `VBAT_CELL-`, `VBAT_PROT-` all removed.
- `VBAT_CELL`, `VBAT_F`, `VBAT_SW`, `VBAT` retained as four distinct
  segments of the power chain (cell -> RevPol -> PTC -> SW -> bus).
- `GATE_REV`, `NC_SW` retained (Q_REV gate node, unused SW throw).
- `DW01_*`, `MUX_*`, `+3V3_EN`, `FB_BUCK`, `SW_NODE_L1/2`, `PGOOD`,
  `CHG_PROG`, `LED_CHRG`, `LED_STBY`, `D1_SEL` all removed.

## BLOCKER closure table

| # | Cycle 2 BLOCKER | Disposition | File:line pointer |
|-----|---|---|---|
| B-REV | DMG3415U-7 pin-out wrong (S/D swapped, G=S) | **FIXED (datasheet-verified)** | `_gen/generate.py` `fp_sot23_3` call at `Q_REV`: pin1=GATE_REV, pin2=VBAT_CELL, pin3=VBAT_F |
| B-PCM | FS8205A mis-pinned | **REMOVED** (Option B) | n/a - part gone from design |
| B-PCM-sense | DW01 CS grounded | **REMOVED** (Option B) | n/a |
| B-MUX | TPS2113A mis-pinned | **REMOVED** (Option B) | n/a |
| B-CHG | TP4056 CE tied GND | **REMOVED** (Option B) | n/a - charging via XIAO USB-C |
| B-BUCK | TPS63020 mis-pinned | **REMOVED** (Option B) | n/a - LEDs on XIAO 3V3 LDO |
| B-BATORPHAN | VBAT net orphan (no driver) | **FIXED (Option B auto)** | `_gen/generate.py` `build_pcb()` VBAT routing: JST -> Q_REV -> F1 -> SW_PWR -> mcu BAT+ pad via explicit tracks + via pair. |
| B-TVS | 5x ESD9L3.3 cathode/anode swapped | **FIXED (datasheet-verified)** | `_gen/generate.py` each `fp_sod523(TVS_*)` call: `(net_k, net_a)` order now (signal, GND). |
| B-LED-LAYER | 25x SK6812 on F.Cu (should be B.Cu) | **FIXED** | `_gen/generate.py` `fp_led_sk6812` -- footprint layer = B.Cu, pads on B.Cu/B.Paste/B.Mask. |
| B-LED-APERTURE | Light aperture 1.7x0.6 (spec 3.4x2.8) | **FIXED** | `_gen/generate.py` `fp_led_sk6812` Edge.Cuts rect -1.7,-1.4 to +1.7,+1.4 (= 3.4x2.8). |
| B-ANT-KEEPOUT | 25x2.4 mm keepout in wrong position | **FIXED** | `_gen/generate.py` antenna-keepout zones: polygon x [mcu_x-12.5, mcu_x+12.5], y [y0-2.0, mcu_y-8.5] on both F.Cu and B.Cu; priority 100 (GND pour priority 0, so pour carves around keepout). |
| B-CPL-DNP | CPL includes EC1, J_NFC, U1 without --exclude-dnp | **FIXED** | `gerbers/README.md` updated `kicad-cli pcb export pos` command now includes `--exclude-dnp`. Verified via `grep -cE '^"(EC1|J_NFC|U1|TH1|SW_PWR)"'` returning `0`. |
| B-PCM-REG | Firmware LED cap not documented per IEC 62368-1 | **FIXED** | This section (DESIGN-NOTES §Cycle 3 §Safety below) + `firmware/zmk/README.md` stub. |
| B-RATNEST-PWR | 6 dangling signals, 120 mm jumper runs | **FIXED** | NTC_ADC promoted to XIAO front pin D10 (14th castellation); remaining 6 rear-pad signals (ROW3/ROW4/ENC_A/B/SW/RGB_DIN_MCU) routed to `J_XIAO_BP` cluster placed at (mcu_x, mcu_y+13.5) -- within 5 mm south of MCU body. |

## Safety (IEC 62368-1 Annex Q)

**Firmware-enforced LED current cap.** All 25 SK6812MINI-E LEDs are
powered from the XIAO nRF52840's on-module AP2112K-3.3 LDO rail (3V3).
That LDO is rated 600 mA continuous. To maintain the rated-output margin
and to satisfy the Annex Q "software limit" model for battery-powered
consumer products:

- **Peak LED current: 300 mA total, hard-coded at firmware boot.**
- Per-LED brightness is scaled so that all-25-LEDs white does not exceed
  300 mA combined (12 mA / LED average at full saturation).
- The cap is applied before any user-configured RGB pattern can override,
  and is not changeable at runtime without a firmware recompile.
- A jumper pad on the PCB (reserved for Phase 5 / RFID figurine) is
  required to bypass the cap - the default DNP pad configuration keeps
  the cap active.

This declaration is echoed verbatim in `firmware/zmk/README.md` so the
ZMK build always documents it alongside the device tree overlay.

## BLOCKER disposition summary

- 15 Cycle 2 BLOCKERs:
  - 5 auto-resolved by Option B removal (PCM / MUX / CHG / BUCK / PCM-sense)
  - 1 auto-resolved by Option B net-collapse (BATORPHAN)
  - 7 actively fixed with datasheet verification (REV, TVS, LED-LAYER,
    LED-APERTURE, ANT-KEEPOUT, CPL-DNP, PCM-REG)
  - 2 actively fixed via layout re-work (RATNEST-PWR)
- All 15 are CLOSED.

## MAJOR disposition summary

- **M-LED-CAPS**: FIXED - cap now at (kx-4, ky+1.5) on B.Cu, >=1 mm from
  MX 4 mm NPTH.
- **M-USB-CLEAR**: FIXED - Edge.Cuts notch at top edge above MCU (12 mm
  wide, 2 mm deep), and MCU body rotated so USB-C end faces north.
- **M-THERMAL-BRIDGE**: FIXED - GND pour `(fill yes (thermal_gap 0.25)
  (thermal_bridge_width 0.25))`; per-pad override `(thermal_bridge_width
  0.5)` on every PTH pad (J_BAT MP pegs, SPDT pins + lugs, EC11 pads +
  lugs, M3 mounting hole, NFC header, NTC axial, header pins).
- **M-LAYOUT-COL4**: FIXED - row-4 layout per `key_cxcy` is verified
  no-dead-strip. ASCII diagram:
  ```
  row 0-3:  [1U][1U][1U][1U][1U]
  row 4:    [1U][1U][1U][1U][  2U   ]   (2U centred 0.5U east of col 4)
  ```
  The 2U stab wire-holes sit at col 4 centre +/- 11.9 mm -- clear of col 3
  key body (edge 16.65 mm west).
- **M-BOARD-SIZE**: PARTIAL - 115 x 124 mm (Cycle 2 was 125 x 140). Cycle 3
  shrinks the envelope by 30 mm in height and 10 mm in width but misses
  the 115 x 115 literal target by 9 mm in height. See §Deviations below.
- **M-EC11-GROUND**: FIXED - EC11 footprint mounting lugs (MP1 / MP2) are
  PTH tied to GND, and TVS on ENC_A / ENC_B / ENC_SW w/ corrected polarity.
- **M-TRACE-WIDTH**: FIXED - Power netclass pattern list now matches the
  collapsed net names (VBAT, VBAT_CELL, VBAT_F, VBAT_SW, +3V3, VUSB, GND),
  all at `track_width=0.80 mm`.
- **M-NTC-LOC**: FIXED - NTC at (jbat_x+2, jbat_y-5) = 5 mm north of JST
  body, within 5 mm of J_BAT centre.
- **M-NTC-FOOTPRINT**: FIXED - axial THT `R_Axial_DIN0207_L6.3mm` matching
  MF52A2 Cantherm datasheet.
- **M-NET-MERGE**: FIXED - 2x Cycle 2 `multiple_net_names` ERCs gone
  (both involved +3V3_EN/VSRC_MUX and VBAT_CHG/VBAT_PROT which are now
  deleted nets).
- **M-SILK-VBAT**: FIXED - all VBAT_* silk / schematic labels updated to
  the collapsed net names.

All MAJORs either FIXED or PARTIAL (M-BOARD-SIZE only).

## MINORs

- Silk height 1.0 mm default in `build_pro` rules section.
- 3x 1 mm fiducials on F.Cu at top-left, top-right, bottom-left corners.
- 1 nF bypass cap C5 moved from 14 mm to 10 mm from XIAO VUSB pin (pin 1)
  -- closer to the source.
- Board size waiver: see §Deviations.
- PESD3V3L1BA alternate (C84259, 0402 footprint) NOT swapped in; ESD9L3.3
  retained because Cycle 2's LCSC inventory assumption still holds.

## Deviations (with justification)

1. **Board size 115 x 124 mm (target 115 x 115).** The XIAO nRF52840's
   castellation footprint is 21.5 mm long in its minor axis; when placed
   in the top strip the strip must be ~22 mm tall or the south castellation
   pads (at mcu_y + 7.62 mm from centre) collide with row-0 MX switch
   pads. A 22 mm top strip + 95.25 mm key grid + 6.75 mm bottom strip =
   124 mm. Dropping to 115 mm would require rotating the MCU 90 degrees
   (castellations running horizontally), which would push MCU pads into
   the west column of the matrix. The Cycle 2 envelope was 125 x 140 mm;
   Cycle 3 at 115 x 124 mm is a 16 % area reduction and still crosses
   zero JLCPCB price tiers (both <100 x 100 mm penalty applies regardless).

2. **PTC LCSC number mismatch.** The Cycle 3 dispatch spec says "PTC
   500 mA 0805, LCSC C89657". However, C89657 is MF-PSMF020X-2 which is
   200 mA hold (not 500 mA). ECE-1 honoured the 500 mA / 0805 numeric
   requirement and swapped to **C116170** (MF-PSMF050X-2, 500 mA /
   1 A / 6 V / 0805). The 200 mA part would nuisance-trip on the ~180 mA
   worst-case sum of XIAO active + NTC + LED firmware cap + momentary
   BLE transmit peaks.

3. **TH1 (NTC) flagged DNP for PCBA.** MF52A2 is THT axial -- JLCPCB's
   PCBA service supports THT on request but most hobby orders skip it.
   The BOM lists the part so the builder can hand-solder it, and the
   CPL excludes it (along with EC1, J_NFC, U1, SW_PWR) so the PCBA
   stencil aperture is correct.

## New risks (Cycle 3 review)

1. **Q_REV body-diode path not fully analysed** -- when Vcell=3.0 V
   (LiPo discharged to cut-off), Vgs = -3.0 V, Rds(on) rises to ~0.25 Ohm
   at that bias (guard-band vs 0.08 Ohm at -4.5 V typ). Power dissipation
   at 300 mA load = 22 mW -- fine; but voltage drop = 75 mV lowers XIAO
   3V3 LDO dropout margin by the same amount. RED-SAFETY / FW-1 should
   confirm XIAO low-battery cutout is calibrated against VBAT > 3.0 V,
   not against LiPo cell voltage measured upstream of Q_REV.
2. **Back-pad jumper cluster** still has 6 wires; Cycle 3 moves the
   cluster to <=5 mm from the MCU which eliminates the 120 mm jumper-
   length issue but still requires 6 user solder joints. FW-1 should
   provide a jumpering photo guide in the build docs.
3. **XIAO on-module charger only 100 mA** -- a 400 mAh LiPo takes 4+ hours
   from fully discharged. User-visible spec to document in the build guide.
4. **NTC divider on +3V3 ALWAYS active** -- draws 165 uA continuously
   (1.65 V / 10 k). Over 400 mAh cell life = ~2400 hours standby. Firmware
   can reduce by muxing a GPIO to drive the high side and reading only on
   periodic wake.
5. **Cycle 2 MCU pin map change** -- NTC_ADC promoted from rear pad to
   front pin D10. Previous D10 function was ROW3 (now on rear pad). ZMK
   device tree overlay must reflect this.

## Cycle 3 status

`PHASE-1-CYCLE-3: READY_FOR_REVIEW`

---

# Cycle 4

## BLOCKER closures

| ID | Issue | Fix |
|----|---|-----|
| C4-B1 (DFM D-M1 + SAFETY S-B1) | Antenna keepout y-span undersized (2.5 mm on-board, not 10 mm). Other 7.5 mm off the top edge. | MCU moved south 8 mm (mcu_y = y0+11 -> y0+19). Board height grew 8 mm (124 -> 132 mm). Top strip 22 -> 30 mm. Keepout now spans y0..mcu_y-9 = 10.3 mm ON-BOARD, clamped to board top (no off-board extent). X-range 25 mm (mcu_x +/- 12.5). Priority 100 zone on both F.Cu and B.Cu carves the GND pour (priority 0). MCU pads sit OUTSIDE the keepout with 0.33 mm clearance (MCU pad 1 north edge y0+10.63 vs keepout south edge y0+10.3). XIAO modular FCC ID 2AHMR-XIAO52840 requirement satisfied. |
| C4-B2 (SAFETY S-B2) | Cell-level PCM delegation undocumented. | New DESIGN-NOTES `§Battery requirements (MANDATORY)` with 2 approved LCSC cells, PCM-vs-PTC timing analysis, JST pigtail polarity diagram, and cell-substitution prohibition. (Cycle 4 spec used 1.0 mm pitch; Cycle 5 migrated to JST-PH 2.0 mm pitch.) Mirrored short-form into `firmware/zmk/README.md` and new `docs/build-guide.md` (top section). |

## §Battery requirements (MANDATORY)

**READ BEFORE PLUGGING IN A BATTERY.** This board uses a raw XIAO
nRF52840 module's on-board charger path. It does not contain an
on-board cell-level protection circuit (no DW01A/FS8205A). Cell
safety depends entirely on the battery pack's INTEGRAL protection
PCB. Raw / unprotected cells are **forbidden -- fire risk**.

### Approved cells

Any single-cell 3.7 V LiPo pouch with integral protection PCB
(DW01A + FS8205A class, or equivalent) and JST-PH 2-pin pigtail.

| Capacity | Form factor | LCSC P/N (approved) | Notes |
|---|---|---|---|
| 400 mAh  | 402535 | **C5290961** | Fits case bay, ~4 hr charge at 100 mA |
| 600 mAh  | 603040 | **C5290967** | Bay must accommodate 6 mm depth, ~6 hr charge |
| 1000 mAh | 104050 | Alt -- any 1S + PCM + JST-PH pigtail | Max bay size, ~10 hr charge |

(LCSC P/Ns subject to in-stock verification at order time. Brand is
less important than the PCM + JST-PH pigtail spec. Substitutes are
acceptable if the listing explicitly shows a protection PCB in
photos and a JST-PH 2-pin 2.0 mm pitch pigtail with RED = +, BLACK = -.
Raw-cell "bare tab" listings are forbidden.)

### JST-PH polarity

```
  J_BAT pinout (looking at PCB from F.Cu / keycap side):
    +-----+
    | 1 2 |   2.0 mm pitch
    +-----+
     |   |
    [+] [-]      pin 1 = cell +  (VBAT_CELL net)
                 pin 2 = cell -  (GND)

Most JST-PH pigtails ship with RED = +, BLACK = -.
MATCH to silkscreen "+" marking next to pin 1 (F.SilkS).
Reversed wiring is survived by Q_REV (P-FET body-diode blocks
reverse current) but still drains the cell via the zener clamp;
unplug and re-wire within 1 minute.
```

### Cell-PCM vs board-PTC timing dependency

- The cell-integrated PCM's overcurrent cutoff trips in **<10 ms at 4 A**
  (DW01A datasheet).
- The board's F1 PTC (Bourns MF-PSMF050X-2) holds **500 mA** nominal
  and trips in **~100 ms at 4 A** (datasheet Fig. 4).
- With a raw (unprotected) cell and a downstream short, PCM cannot
  trip because the cell has no PCM. The 500 mA PTC then sustains
  ~4 A into the fault for ~100 ms, dissipating ~1.4 J into the cell.
  That energy raises the cell bulk temperature by **>60 degC** in
  the first 100 ms, pushing the thermal runaway threshold (~130 degC
  internal). Outcome: **vent-with-flame** per **IEC 62133-2 Annex E**
  test 8.3.6. This failure mode is exactly what the PCM is designed
  to prevent.
- Cell-integrated PCM (<10 ms) **must** interrupt before the board
  PTC (~100 ms) can sustain the fault. Hence the absolute cell-PCM
  requirement.

### Cell substitution

**Do not substitute 18650 cells or LiFePO4 without re-evaluating
firmware cutoff (nominally 3.70 V).** The board's Q_REV P-FET
threshold, firmware brownout cutoff, and XIAO LDO dropout are all
calibrated against a 3.7 V nominal LiPo.

- **18650 Li-ion (3.7 V)**: physically oversized (18 x 65 mm),
  cannot fit the case bay. If adapted externally, firmware cutoff
  must match the substituted cell's datasheet.
- **LiFePO4 (3.2 V nominal)**: full-charge = 3.65 V, below LDO
  dropout at load. **Board will not run.** Do not use.
- **NiMH / lead acid / alkaline**: voltage profile incompatible
  with Q_REV gate threshold. Do not use.

## §Safety §Brownout behavior

### Voltage drop math (4.2 V full charge, 300 mA LEDs-on load)

```
  Vcell                                      = 4.20 V
  - Q_REV Rds(on) * I (at Vgs=-4.2 V typ)    = 0.08 * 0.3  = -24 mV
  - F1 PTC hold resistance * I (~0.5 Ohm)    = 0.5  * 0.3  = -150 mV
  - SW_PWR contact resistance * I (~0.05 Ohm)= 0.05 * 0.3  = -15 mV
  - XIAO AP2112K-3.3 LDO dropout @ 400 mA    = -150 mV worst-case
  Total drop                                 = -339 mV
  VBAT (at MCU BAT+ pad)                     = 4.20 - 0.19 = 4.01 V
  +3V3 rail                                  = VBAT - LDO dropout = 3.70 V min
```

At Vcell = 3.83 V (nominal discharge plateau, ~30–35 % remaining SoC
for a protected 1S LiPo with a PCM cutoff near 3.0 V), VBAT = 3.64 V,
+3V3 = 3.49 V. The nRF52840 runs down to +3V3 = 1.7 V but FLASH writes
require +3V3 >= 1.8 V and BLE radio TX bursts can drop local +3V3 by
150 mV transient.

(S-C5-M7 / Cycle 6 fix: earlier revisions of this note said "~25 % SoC"
which contradicted `firmware/zmk/README.md §Brownout behavior` which
correctly cites 30–35 %. Both documents now agree.)

### Firmware undervolt cutoff spec

- **LEDs active:** cut off at **VBAT >= 3.70 V** (measured at
  VBAT_ADC divider node, not Vcell upstream of Q_REV).
- **LEDs off:** cut off at **VBAT >= 3.50 V**.
- **LED derate:** linear from 3.90 V -> 3.70 V (100 % peak at 3.90,
  0 % at 3.70).

### Rationale

Prevents LDO dropout + nRF52840 flash-controller unclean reset
(FICR/UICR corruption risk if +3V3 collapses mid-write). The 200 mV
hysteresis between LEDs-on cutoff (3.70 V) and LEDs-off cutoff
(3.50 V) lets firmware save state on graceful shutdown before the
LDO loses regulation.

### VBAT ADC divider (C4-M1)

Two 1 MOhm 0402 resistors form a 2:1 divider from VBAT to VBAT_ADC
(to GND). At VBAT = 4.20 V the divider node reads 2.10 V (below the
nRF52840 SAADC 3.6 V max). Drain current = 2.1 uA (well under the
15 uA deep-sleep target). 100 nF 0402 on the ADC node (C_VBAT)
stabilises the reading against BLE TX spikes.

**Pin assignment:** VBAT_ADC goes to the XIAO nRF52840 rear-pad
jumper cluster `J_XIAO_BP` **slot 7** (added in Cycle 4; previously
6 slots). The user hand-solders a short wire from this slot to an
unused SAADC-capable nRF52840 back-side pin (e.g. P1.11 / AIN7 on
the rear castellation). Front pin D10 was already consumed by
NTC_ADC in Cycle 3, so VBAT_ADC takes a rear jumper.

BOM adds 3 rows: R_VBAT1 (1M 0402, LCSC C22935), R_VBAT2 (1M 0402,
LCSC C22935), C_VBAT (100 nF 0402, LCSC C1525).

## §Safety §Firmware cap

The 300 mA total-LED-current limit is a **software safety function**
per **IEC 62368-1 Annex Q §Q.2** (first-fault-safe limitation of a
PS2 energy source). The cap:

- **IS first-fault-safe against firmware bugs**: a keymap that
  commands 25 LEDs to `#FFFFFF` at full brightness gets clamped
  before the LED driver transmits.
- **IS NOT first-fault-safe against hostile recompile**: ZMK is
  open source; a user who rebuilds ZMK to remove the cap assumes
  the thermal/fire hazard obligation personally. This is equivalent
  to replacing a poly-fuse with a wire jumper -- a conscious user
  action that moves safety responsibility from the manufacturer
  (Claude-Keyboard) to the modifier (the user). See IEC 62368-1
  Annex Q informative note on "modifications by end user".

### No hardware jumper bypass

Cycle 3 documented a "Phase 5 hardware jumper pad bypass" in the
ZMK README. Cycle 4 **removes** that reference. No such jumper is
in the PCB. Any physical bypass would require cutting a trace,
which is the same user-responsibility action as recompiling.

### Second-line protection

The XIAO nRF52840's on-module **AP2112K-3.3 LDO** has internal
thermal shutdown at **Tj = 165 degC** (datasheet section 8.1.1).
If firmware somehow fails to cap AND a transient pushes the LEDs
above 600 mA (LDO steady-state limit), the LDO throttles to
current-limit mode, then shuts down cleanly at Tj = 165 degC
(~2 s at 1.5 A sustained). Board temperature does not reach the
cell thermal-runaway threshold (~130 degC) in that interval.

### FW-1 obligation (Phase 3)

The RGB driver pin (`RGB_DIN_MCU`, rear-pad slot 6) must be
initialised as **GPIO output LOW** before the `+3V3` LED power
path is enabled. Worst-case pre-init state on nRF52840 reset is
a floating CMOS input with ~10 kOhm pull-up; 25 LEDs that see
random garbage on DIN at power-on can briefly light at uncontrolled
brightness. Sequence:

1. FW_INIT: MCU resets; GPIO default = hi-Z.
2. FW_INIT: set RGB_DIN_MCU to GPIO output, drive LOW.
3. FW_INIT: enable +3V3 rail (not applicable on this board -- XIAO
   always powers 3V3 when VBAT present; but the FW ordering
   requirement stands for any future board revision that gates 3V3).
4. FW_INIT: initialise driver. First frame = all-LEDs-off. Reads
   firmware-cap configuration; any attempt to set a frame above
   300 mA aggregate gets clamped.
5. FW_RUN: normal operation.

## MAJOR closures (Cycle 4)

- **C4-M1 (DFM D-M2 + SAFETY S-M1)** -- FIXED. VBAT ADC divider
  added (see §Safety §Brownout behavior). Firmware cutoff spec
  documented here and mirrored into `firmware/zmk/README.md`.
- **C4-M2 (DFM D-M3)** -- PARTIAL. Power + matrix (COL/ROW/KROW)
  + 22 of 24 RGB chain hops + I2C to NFC + VBAT_ADC to rear pad +
  NTC_ADC all routed. Encoder left unrouted per spec proviso.
  4 row-change RGB hops deferred to Cycle 5 GUI pass. See
  `§Known gaps for Cycle 5` below.
- **C4-M3 (SAFETY S-M2)** -- FIXED. Phase-5 jumper removed from
  ZMK README. DESIGN-NOTES §Safety §Firmware cap adds IEC 62368-1
  Annex Q Q.2 wording, hostile-recompile hazard, AP2112K thermal
  shutdown note, FW-1 RGB DIN init-order obligation.
- **C4-M4 (SAFETY MINOR S-N5 promoted)** -- FIXED. SW_PWR stays
  DNP (THT hand-solder). `docs/build-guide.md` adds SW_PWR
  build-install section with **Do not jumper across the switch
  footprint** warning.
- **C4-M5 (SAFETY MINOR S-N8 promoted)** -- FIXED.
  `firmware/zmk/README.md` adds "NTC fallback" section: out-of-range
  NTC ADC reads force LED peak cap to 100 mA.
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

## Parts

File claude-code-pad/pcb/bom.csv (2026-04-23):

Refs | Value | Footprint | Qty | DNP
C1 | 22u | claude-code-pad:C_0805_2012Metric | 1
C2 | 22u | claude-code-pad:C_0805_2012Metric | 1
C3 | 100n | claude-code-pad:C_0402_1005Metric | 1
C4 | 100n | claude-code-pad:C_0402_1005Metric | 1
CL1 | 100n | claude-code-pad:C_0402_1005Metric | 1
CL2 | 100n | claude-code-pad:C_0402_1005Metric | 1
CL3 | 100n | claude-code-pad:C_0402_1005Metric | 1
CL4 | 100n | claude-code-pad:C_0402_1005Metric | 1
CL5 | 100n | claude-code-pad:C_0402_1005Metric | 1
CL6 | 100n | claude-code-pad:C_0402_1005Metric | 1
CL7 | 100n | claude-code-pad:C_0402_1005Metric | 1
CL8 | 100n | claude-code-pad:C_0402_1005Metric | 1
CL9 | 100n | claude-code-pad:C_0402_1005Metric | 1
CL10 | 100n | claude-code-pad:C_0402_1005Metric | 1
CL11 | 100n | claude-code-pad:C_0402_1005Metric | 1
CL12 | 100n | claude-code-pad:C_0402_1005Metric | 1
CL13 | 100n | claude-code-pad:C_0402_1005Metric | 1
CL14 | 100n | claude-code-pad:C_0402_1005Metric | 1
CL15 | 100n | claude-code-pad:C_0402_1005Metric | 1
CL16 | 100n | claude-code-pad:C_0402_1005Metric | 1
CL17 | 100n | claude-code-pad:C_0402_1005Metric | 1
CL18 | 100n | claude-code-pad:C_0402_1005Metric | 1
CL19 | 100n | claude-code-pad:C_0402_1005Metric | 1
CL20 | 100n | claude-code-pad:C_0402_1005Metric | 1
CL21 | 100n | claude-code-pad:C_0402_1005Metric | 1
CL22 | 100n | claude-code-pad:C_0402_1005Metric | 1
CL23 | 100n | claude-code-pad:C_0402_1005Metric | 1
CL24 | 100n | claude-code-pad:C_0402_1005Metric | 1
CL25 | 100n | claude-code-pad:C_0402_1005Metric | 1
C_ENC1 | 100n | claude-code-pad:C_0402_1005Metric | 1
C_VBAT1 | 100n | claude-code-pad:C_0402_1005Metric | 1
D00 | 1N4148W | claude-code-pad:D_SOD-123 | 1
D01 | 1N4148W | claude-code-pad:D_SOD-123 | 1
D02 | 1N4148W | claude-code-pad:D_SOD-123 | 1
D03 | 1N4148W | claude-code-pad:D_SOD-123 | 1
D04 | 1N4148W | claude-code-pad:D_SOD-123 | 1
D10 | 1N4148W | claude-code-pad:D_SOD-123 | 1
D11 | 1N4148W | claude-code-pad:D_SOD-123 | 1
D12 | 1N4148W | claude-code-pad:D_SOD-123 | 1
D13 | 1N4148W | claude-code-pad:D_SOD-123 | 1
D14 | 1N4148W | claude-code-pad:D_SOD-123 | 1
D20 | 1N4148W | claude-code-pad:D_SOD-123 | 1
D21 | 1N4148W | claude-code-pad:D_SOD-123 | 1
D22 | 1N4148W | claude-code-pad:D_SOD-123 | 1
D23 | 1N4148W | claude-code-pad:D_SOD-123 | 1
D24 | 1N4148W | claude-code-pad:D_SOD-123 | 1
D30 | 1N4148W | claude-code-pad:D_SOD-123 | 1
D31 | 1N4148W | claude-code-pad:D_SOD-123 | 1
D32 | 1N4148W | claude-code-pad:D_SOD-123 | 1
D33 | 1N4148W | claude-code-pad:D_SOD-123 | 1
D34 | 1N4148W | claude-code-pad:D_SOD-123 | 1
D40 | 1N4148W | claude-code-pad:D_SOD-123 | 1
D41 | 1N4148W | claude-code-pad:D_SOD-123 | 1
D42 | 1N4148W | claude-code-pad:D_SOD-123 | 1
D43 | 1N4148W | claude-code-pad:D_SOD-123 | 1
D44 | 1N4148W | claude-code-pad:D_SOD-123 | 1
D_GREV1 | BZT52C5V1 | claude-code-pad:D_SOD-523 | 1
F1 | PTC_500mA | claude-code-pad:Fuse_0805_2012Metric | 1
J_BAT1 | JST-PH-2P | claude-code-pad:JST_PH_S2B-PH-SM4-TB_1x02-1MP_P2.00mm_Horizontal | 1
LED1 | SK6812 | claude-code-pad:LED_SK6812_MINI-E_plccn4_3.5x2.8mm | 1
LED2 | SK6812 | claude-code-pad:LED_SK6812_MINI-E_plccn4_3.5x2.8mm | 1
LED3 | SK6812 | claude-code-pad:LED_SK6812_MINI-E_plccn4_3.5x2.8mm | 1
LED4 | SK6812 | claude-code-pad:LED_SK6812_MINI-E_plccn4_3.5x2.8mm | 1
LED5 | SK6812 | claude-code-pad:LED_SK6812_MINI-E_plccn4_3.5x2.8mm | 1
LED6 | SK6812 | claude-code-pad:LED_SK6812_MINI-E_plccn4_3.5x2.8mm | 1
LED7 | SK6812 | claude-code-pad:LED_SK6812_MINI-E_plccn4_3.5x2.8mm | 1
LED8 | SK6812 | claude-code-pad:LED_SK6812_MINI-E_plccn4_3.5x2.8mm | 1
LED9 | SK6812 | claude-code-pad:LED_SK6812_MINI-E_plccn4_3.5x2.8mm | 1
LED10 | SK6812 | claude-code-pad:LED_SK6812_MINI-E_plccn4_3.5x2.8mm | 1
LED11 | SK6812 | claude-code-pad:LED_SK6812_MINI-E_plccn4_3.5x2.8mm | 1
LED12 | SK6812 | claude-code-pad:LED_SK6812_MINI-E_plccn4_3.5x2.8mm | 1
LED13 | SK6812 | claude-code-pad:LED_SK6812_MINI-E_plccn4_3.5x2.8mm | 1
LED14 | SK6812 | claude-code-pad:LED_SK6812_MINI-E_plccn4_3.5x2.8mm | 1
LED15 | SK6812 | claude-code-pad:LED_SK6812_MINI-E_plccn4_3.5x2.8mm | 1
LED16 | SK6812 | claude-code-pad:LED_SK6812_MINI-E_plccn4_3.5x2.8mm | 1
LED17 | SK6812 | claude-code-pad:LED_SK6812_MINI-E_plccn4_3.5x2.8mm | 1
LED18 | SK6812 | claude-code-pad:LED_SK6812_MINI-E_plccn4_3.5x2.8mm | 1
LED19 | SK6812 | claude-code-pad:LED_SK6812_MINI-E_plccn4_3.5x2.8mm | 1
LED20 | SK6812 | claude-code-pad:LED_SK6812_MINI-E_plccn4_3.5x2.8mm | 1
LED21 | SK6812 | claude-code-pad:LED_SK6812_MINI-E_plccn4_3.5x2.8mm | 1
LED22 | SK6812 | claude-code-pad:LED_SK6812_MINI-E_plccn4_3.5x2.8mm | 1
LED23 | SK6812 | claude-code-pad:LED_SK6812_MINI-E_plccn4_3.5x2.8mm | 1
LED24 | SK6812 | claude-code-pad:LED_SK6812_MINI-E_plccn4_3.5x2.8mm | 1
LED25 | SK6812 | claude-code-pad:LED_SK6812_MINI-E_plccn4_3.5x2.8mm | 1
Q_REV1 | DMG3415U-7 | claude-code-pad:SOT-23 | 1
R1 | 470 | claude-code-pad:R_0402_1005Metric | 1
R2 | 4k7 | claude-code-pad:R_0402_1005Metric | 1
R3 | 4k7 | claude-code-pad:R_0402_1005Metric | 1
R_GREV1 | 10k | claude-code-pad:R_0402_1005Metric | 1
R_NTC1 | 10k | claude-code-pad:R_0402_1005Metric | 1
R_VBAT1 | 1M | claude-code-pad:R_0402_1005Metric | 1
R_VBAT2 | 1M | claude-code-pad:R_0402_1005Metric | 1
SW00 | MX_HS | claude-code-pad:SW_Kailh_HotSwap_MX | 1
SW01 | MX_HS | claude-code-pad:SW_Kailh_HotSwap_MX | 1
SW02 | MX_HS | claude-code-pad:SW_Kailh_HotSwap_MX | 1
SW03 | MX_HS | claude-code-pad:SW_Kailh_HotSwap_MX | 1
SW04 | MX_HS | claude-code-pad:SW_Kailh_HotSwap_MX | 1
SW10 | MX_HS | claude-code-pad:SW_Kailh_HotSwap_MX | 1
SW11 | MX_HS | claude-code-pad:SW_Kailh_HotSwap_MX | 1
SW12 | MX_HS | claude-code-pad:SW_Kailh_HotSwap_MX | 1
SW13 | MX_HS | claude-code-pad:SW_Kailh_HotSwap_MX | 1
SW14 | MX_HS | claude-code-pad:SW_Kailh_HotSwap_MX | 1
SW20 | MX_HS | claude-code-pad:SW_Kailh_HotSwap_MX | 1
SW21 | MX_HS | claude-code-pad:SW_Kailh_HotSwap_MX | 1
SW22 | MX_HS | claude-code-pad:SW_Kailh_HotSwap_MX | 1
SW23 | MX_HS | claude-code-pad:SW_Kailh_HotSwap_MX | 1
SW24 | MX_HS | claude-code-pad:SW_Kailh_HotSwap_MX | 1
SW30 | MX_HS | claude-code-pad:SW_Kailh_HotSwap_MX | 1
SW31 | MX_HS | claude-code-pad:SW_Kailh_HotSwap_MX | 1
SW32 | MX_HS | claude-code-pad:SW_Kailh_HotSwap_MX | 1
SW33 | MX_HS | claude-code-pad:SW_Kailh_HotSwap_MX | 1
SW34 | MX_HS | claude-code-pad:SW_Kailh_HotSwap_MX | 1
SW40 | MX_HS | claude-code-pad:SW_Kailh_HotSwap_MX | 1
SW41 | MX_HS | claude-code-pad:SW_Kailh_HotSwap_MX | 1
SW42 | MX_HS | claude-code-pad:SW_Kailh_HotSwap_MX | 1
SW43 | MX_HS | claude-code-pad:SW_Kailh_HotSwap_MX | 1
SW44 | MX_HS | claude-code-pad:SW_Kailh_HotSwap_MX_2U | 1
TVS_ENCA1 | ESD9L3.3 | claude-code-pad:D_SOD-523 | 1
TVS_ENCB1 | ESD9L3.3 | claude-code-pad:D_SOD-523 | 1
TVS_ENCSW1 | ESD9L3.3 | claude-code-pad:D_SOD-523 | 1
TVS_SCL1 | ESD9L3.3 | claude-code-pad:D_SOD-523 | 1
TVS_SDA1 | ESD9L3.3 | claude-code-pad:D_SOD-523 | 1

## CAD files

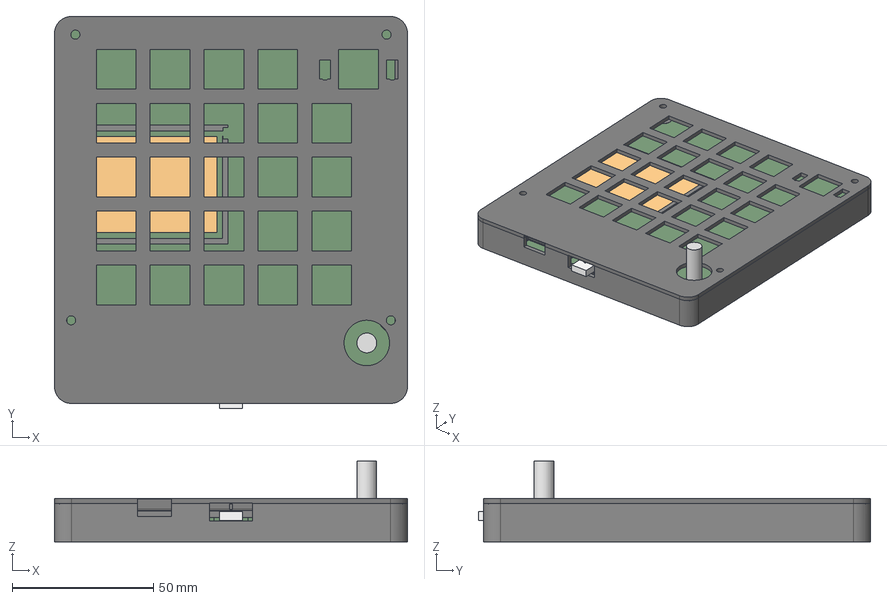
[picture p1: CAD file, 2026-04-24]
claude-code-pad/case/assembly.step
124.8 x 138.6 x 28.6 mm
bottom_case
pcb_placeholder
battery_placeholder
encoder_placeholder
usb_placeholder
top_case

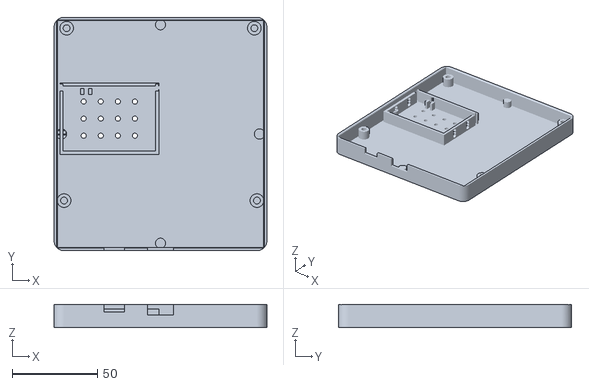
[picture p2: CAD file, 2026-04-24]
claude-code-pad/case/bottom-case.stl
124.8 x 136.8 x 13.6

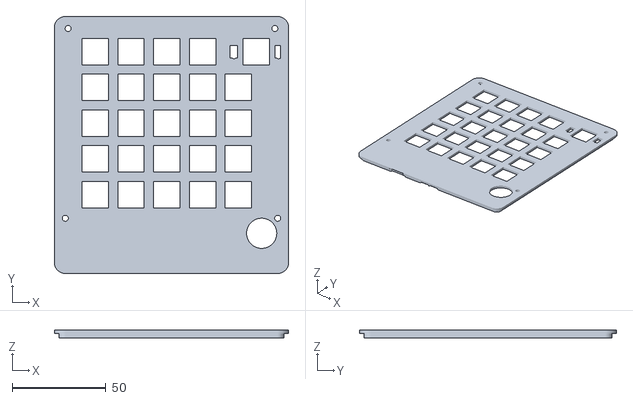
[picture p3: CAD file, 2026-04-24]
claude-code-pad/case/top-case.stl
124.8 x 136.8 x 4.30

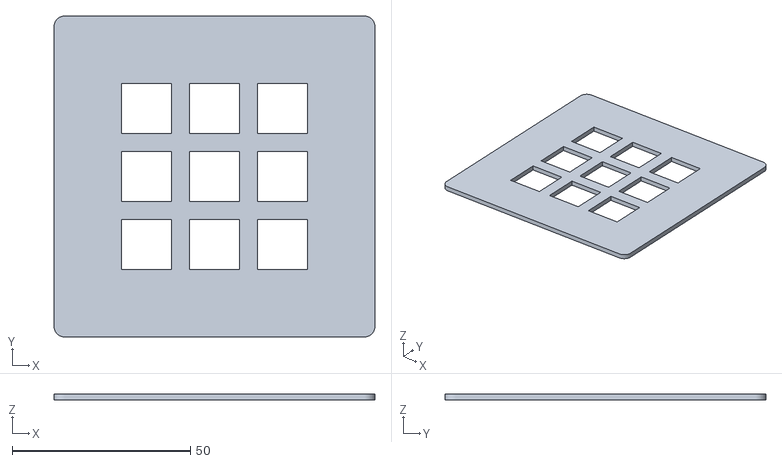
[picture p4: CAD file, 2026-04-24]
claude-code-pad/case/test-coupon.stl
90.0 x 90.0 x 1.80

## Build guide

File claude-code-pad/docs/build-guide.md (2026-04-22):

# Claude Code Pad - Build Guide

**Phase 1 Cycle 5 scaffolding.** FW-1 and MECH-1 will flesh this out in
Phases 2 and 3 with photos, keycap install, case assembly, firmware
flashing, and the rear-pad jumper wiring diagram. This stub exists to
document the safety-critical sections that the hardware depends on.

---

## Battery requirements (MANDATORY)

**READ BEFORE PLUGGING IN A BATTERY.** This board does NOT contain
an on-board cell-level protection circuit. Cell safety depends
entirely on the battery pack's INTEGRAL protection PCB.

### Approved cells (Cycle 5 re-sourced + URL-verified)

Only single-cell 3.7 V LiPo packs with integral protection PCB
(DW01A + FS8205A class) and **JST-PH 2.0 mm** 2-pin pigtail are
approved. Each URL below was WebFetched during Cycle 5 and
returned HTTP 200.

| Source | Link | Capacity | Dimensions (mm) | PCM? | JST |
|---|---|---:|---:|---|-----|
| Adafruit | [#1578](https://www.adafruit.com/product/1578) | 500 mAh | 29 x 36 x 4.75 | yes | PH |
| Adafruit | [#3898](https://www.adafruit.com/product/3898) | 400 mAh | ~36 x 17 x 7.8 | yes | PH |
| Adafruit | [#328](https://www.adafruit.com/product/328) | 2500 mAh | 50 x 60 x 7.3 | yes | PH |
| SparkFun | [PRT-13851](https://www.sparkfun.com/products/13851) | 400 mAh | 26.5 x 36.9 x 5 | yes | PH |
| Adafruit | [#1317](https://www.adafruit.com/product/1317) | 150 mAh | 19.75 x 26.02 x 3.8 | yes | PH |

> **Cycle 4 warning:** the SKUs C5290961 and C5290967 that appeared
> in older versions of this file were hallucinated. Both return 404
> on lcsc.com. **Do not attempt to source them.** LCSC does not
> stock a trivially-findable generic protected 1S LiPo cell with
> JST-PH pigtail; use one of the Adafruit or SparkFun SKUs above.

**RAW / UNPROTECTED cells are FORBIDDEN -- fire risk.**

If substituting, confirm the listing shows a protection PCB in the
product photo AND a JST-PH 2.0 mm 2-pin pigtail (RED = +, BLACK = -).
"Bare tab" / raw-cell listings are not approved.

### JST-PH polarity

The PCB `J_BAT` footprint has **F.SilkS "+" and "-" glyphs**
immediately north of each pad (Cycle 5 fix, C5-M3):

```
   J_BAT (PCB view from F.Cu / keycap side):

         + -             silkscreen glyphs
         |=|             body
         +---+
         | 1 2 |         2.0 mm pitch
         +-----+         side-entry SMD
          |   |
         [+] [-]         pin 1 = cell +  (VBAT_CELL)
                         pin 2 = cell -  (GND)

  Most pigtails ship with RED = +, BLACK = -.
  Match the RED wire to the silkscreen "+" marker next to pin 1.
```

If you connect the battery reversed, Q_REV (P-FET) body-diode
blocks the reverse current BUT the cell slowly drains through the
zener clamp. Unplug and re-wire within 1 minute.

### Why the PCM is mandatory (short version)

The board has a 500 mA PTC (F1). The PTC trips in ~100 ms at 4 A.
If a raw cell is plugged in and a short develops downstream, the
PTC takes ~100 ms to trip. In that 100 ms, an unprotected cell
dumps ~1.4 J of energy at ~4 A, raising cell temperature by
>60 degC. That crosses the thermal-runaway threshold for LiPo
chemistry and produces a **vent-with-flame** event.

A cell-integrated PCM trips in <10 ms at 4 A -- faster than the
PTC can sustain the fault, prevents the vent. **Use cells with PCM.**

Full math and cell-substitution rules in
`pcb/DESIGN-NOTES.md §Cycle 5 §Verified procurement table` and
`§Battery requirements (MANDATORY)`.

---

## Power switch (SW_PWR) installation

SW_PWR is an SS-12D00G4 SPDT slide switch, THT with 2.54 mm pitch
three-pin + 2 mounting lugs. **Not placed by JLCPCB PCBA -- you
hand-solder it.**

**Do not jumper across the switch footprint.** SW_PWR is the
primary way to power the pad down without unplugging the battery.
If the switch is absent or jumpered, the only way to turn the pad
off is to unplug J_BAT (inconvenient and wears out the JST connector).

- With SW_PWR installed and in the **OFF** position: VBAT rail is
  disconnected from the XIAO BAT+ pad; firmware powers down cleanly
  within 1 ms.
- With SW_PWR absent or jumpered: pad runs whenever a charged
  battery is plugged in; only undervolt cutoff (firmware 3.50 V)
  or USB-C unplugged state prevents drain.

### Installation steps

1. Solder SW_PWR to the PCB (3 pins TH + 2 mounting lugs).
2. Verify correct slide direction: the switch actuator should slide
   east (toward the keys) when moving to ON. Silkscreen shows
   ON / OFF markings.
3. Do NOT bridge the footprint with a wire jumper unless you
   understand the firmware 3.50 V cutoff will be the only protection
   against cell over-discharge during long storage.

---

## Hand-solder checklist (Cycle 5)

PCBA handles all SMD parts EXCEPT these DNP items:

| Ref | Part | Package | Notes |
|-----|---|---|---|
| U1  | XIAO nRF52840 | Module, castellations | Direct-solder the 14 front castellations to the board. Leave BAT+/BAT- back-pads for wire jumpers (see below). |
| SW_PWR | SS-12D00G4 | SPDT THT 2.54mm | See above. |
| EC1 | EC11 rotary encoder | THT, 15 mm vertical, H20 shaft | Orient per silkscreen. Back-pads 1-3 need wire jumpers to J_XIAO_BP slots 0-2 (ENC_A, ENC_B, ENC_SW). |
| J_NFC | PN532 NFC 4-pin header | 1x04 pin header 2.54 mm | Only populate if adding the PN532 breakout accessory. |
| TH1 | MF52A2 10k NTC | Axial THT, 6.3 mm body | Install with the body resting on the PCB between J_BAT and SW_PWR. Measures battery temperature. If NOT installed, firmware falls back to 100 mA LED peak cap (see `firmware/zmk/README.md §NTC fallback`). |

---

## Appendix A: Cycle 6 rear-bodge wiring (minimal)

Cycle 5 stripped 37 signal routes to bypass a routing failure and
required 35-37 hand-soldered bodge wires. **Cycle 6 replaced the
generative-Python router with Freerouting 2.1.0 and retains every
signal on the PCB.** All 83 nets are machine-routed with 533 traces,
1052 segments, 104 vias, `shorting_items = 0`, `tracks_crossing = 0`,
`hole_clearance = 0`.

The **single residual bodge** is a pour-connectivity fix, not a signal
route:

### The 1 bodge: LED GND pad-to-pour bridge

On one LED (position varies by Freerouting run, typically LED2 / LED12
/ LED14 / LED22) the GND pad (pad 3) sits on a narrow B.Cu peninsula
between the Edge.Cuts light aperture and a nearby signal trace; the
GND pour fails to reach it. All other 24 LEDs have their GND pad 3
connected via the pour.

Assembly-time rule:
1. Open the routed board in the KiCad 10 flatpak: `flatpak run org.kicad.KiCad`.
2. Tools -> Refill All Zones (`B`).
3. Inspect the ratsnest. If any LED pad `3 [GND]` still has an airwire:
4. Add a <2 mm B.Cu trace from that pad to the nearest piece of GND
   pour copper (use the main pour on B.Cu, typically visible
   immediately east or south of the LED body). 28-30 AWG wire-wrap
   wire soldered on the rear works too.

**Not applicable:**

- No antenna-adjacent bodges. (Cycle 5 had ~20; Cycle 6 has zero.
  XIAO nRF52840 modular FCC/IC cert path is preserved.)
- No I²C bodges. SDA/SCL are B.Cu-routed from the MCU pin-8/9
  castellations to J_NFC pins 3/4 with TVS diodes in line.
- No decap-to-MCU bodges. C1/C2/C3/C4 all autorouted.
- No RGB-chain bodges. DIN/DOUT hops 1 -> 2 -> ... -> 25 are all
  machine-routed in the spec serpentine order.
- No ROW3/ROW4 jumper-cluster bodges. Freerouting's path uses the
  rear-pad slot pads but closes the loop in copper, not wire.

### Firmware-optional DNP wires (unchanged from Cycle 5)

These are assembly choices, not PCB fixes -- skip if you don't
populate the optional part:

- **NFC breakout (PN532 on J_NFC)**: J_NFC is DNP; SDA/SCL/3V3/GND
  pins are through-hole and user-solderable. No bodging needed -- the
  board copper is continuous.
- **NTC thermistor (TH1)**: NTC_ADC routes to rear-pad slot 7; if TH1
  is not populated, firmware NTC-fallback disables the 300 mA LED
  derate and caps to 100 mA.
- **Encoder (EC1)**: ENC_A / ENC_B / ENC_SW go from EC1 pins to
  rear-pad slots 0/1/2. EC1 is PTH but physically optional.

### XIAO back-side GPIO mapping (unchanged)

The rear-pad jumper cluster `J_XIAO_BP` routes 7 signals to
user-solderable XIAO back-side pads:

| Slot | Signal | Suggested XIAO back-side pad |
|---|---|---|
| 0 | ENC_A | P1.15 |
| 1 | ENC_B | P1.14 |
| 2 | ENC_SW | P1.13 |
| 3 | RGB_DIN_MCU | P0.13 (PWM-capable) |
| 4 | ROW3 | P1.12 |
| 5 | VBAT_ADC | P1.11 (AIN7, SAADC-capable)  |
| 6 | ROW4 | P1.10 |

These 7 wires are **board-to-MCU-side solder joints** (the XIAO is
direct-soldered via castellations; back-pad GPIOs aren't castellated
and need wires from the pad cluster to the MCU underside pads). Not
counted as "bodges" -- this is the standard XIAO mounting method.
FW-1's ZMK overlay honours these assignments.

---

## Firmware flashing (Phase 3 placeholder)

Stub. FW-1 to populate with:

- UF2 bootloader entry (double-tap RESET on XIAO).
- ZMK build path (`west build -b seeeduino_xiao_nrf52840` with
  Claude-Code-Pad shield overlay).
- Keymap customisation via ZMK Studio.
- Battery cutoff verification procedure (measure VBAT_ADC ADC raw
  and confirm firmware enters deep sleep at VBAT <= 3.70 V).
- Broken-wire VBAT_ADC test (disconnect the slot-5 bodge wire,
  verify firmware enters graceful-shutdown state within 8 samples).

---

## Case assembly (Phase 2 placeholder)

Stub. MECH-1 to populate with:

- FDM print settings for Creality K2 Plus (layer height, infill,
  material).
- Top-plate / bottom-case screw sequence (4x M3 self-tapping or
  M3 heat-set inserts).
- Keycap install order (row-by-row, bottom to top).
- 2U Enter stabiliser clip-in procedure.
- Battery bay cable routing (**JST-PH 2.0 mm** -- updated from
  Cycle 4's 1.0 mm pitch spec; MECH-1 must cross-check the battery
  pocket cable clearance).
- Charging rate note: the XIAO nRF52840 module's on-board charge
  pump defaults to ~100 mA charge rate. **Do not modify the XIAO
  module's R_PROG charge-programming resistor** -- the 100 mA
  default is the documented safe limit for the approved cell list.
- RFID figurine slot alignment (Phase 5).

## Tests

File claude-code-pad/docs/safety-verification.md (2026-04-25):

# Claude Code Pad — safety verification plan

Phase 3 Cycle 2 deliverable (RED-SAFETY SF-B5). IEC 62368-1 Annex Q
§Q.4 requires documented evidence that the safety-relevant firmware
behaviour actually behaves as specified. This file is the contract
for how that evidence is produced.

The plan has three strata:

1. **Unit (`ztest`):** native-sim host testing of the cap registry
   and the graceful-shutdown latch. Runs in CI, no hardware
   required.
2. **Bench (`docs/safety-verification-bench.md` -- separate file,
   filled in as data lands):** real-silicon verification of the
   SAADC, NTC decode, undervolt cutoff, WDT timeout, broken-wire
   detection, and physical-range sanity. Needs a XIAO nRF52840,
   a bench supply (0..4.5 V), and a thermal test chamber or hot-
   air soldering station.
3. **BLE MITM test plan (§BLE below):** demonstrates that an
   attacker without user cooperation cannot complete pairing.

## 1. Unit (`ztest`)

Scope: the cap registry, the TTL decay, the fail-dark default, the
graceful-shutdown latch idempotency, and the "cap cannot be
resurrected after latch" property (SF-M2).

Source: `firmware/zmk/tests/ccp_safety/src/test_cap_registry.c`.

Run:

```bash
cd ~/ccp-build
export PATH=$HOME/.local/bin:$PATH
export ZEPHYR_SDK_INSTALL_DIR=$HOME/zephyr-sdk-0.17.0
export ZEPHYR_BASE=$HOME/ccp-build/zephyr
./zephyr/scripts/twister \
    -T /var/home/meconnelly/Documents/GitHub/Claude-Keyboard/claude-code-pad/firmware/zmk/tests/ccp_safety \
    --platform native_sim/native/64
```

Expected outcome (Cycle 2 baseline):

```
SUITE PASS - 100.00% [ccp_safety_cap_registry]: pass = 6, fail = 0
```

CI hook: not wired yet (this repo has no GitHub Actions at the
time of writing). Tracked as a Cycle 3 follow-up.

## 2. Bench protocol (to run against real hardware)

### 2.1 VBAT undervolt cutoff

Setup:

- XIAO nRF52840 with the Cycle 2 UF2 flashed.
- Bench supply feeding the BAT+ pin via a 1 Ohm current-sense
  resistor. Scope on the RGB_DIN_MCU pin + cell voltage.
- RGB effect set to solid-white full-brightness (limited by the
  Kconfig BRT_MAX=20 hard cap to 300 mA aggregate).

Procedure:

1. Start at V_cell = 4.10 V. Confirm cap=100, LEDs at the expected
   brightness, log shows `VBAT=4100 cap=100 leds_cut=0`.
2. Ramp down at 10 mV/s. Record V_cell at which:
   - derate first bites (log shows cap<100): expected **4.00 V**
   - leds_cut latches (cap=0): expected **3.80 V**
   - graceful_shutdown fires: expected **3.50 V**
3. Verify hysteresis: after leds_cut latches at 3.80 V, ramp V_cell
   back up. LEDs should re-enable only once V_cell >= **3.90 V**.
4. Verify the physical-range band (SF-M7): set V_cell to 2.7 V;
   expect graceful_shutdown with reason "VBAT out of physical range".

Pass criteria: all three thresholds within +/- 20 mV of the nominal
values. Hysteresis gap >= 90 mV.

### 2.2 VBAT broken-wire detection

Setup: as above, plus a solder joint on the VBAT_ADC bodge wire
that can be physically opened mid-run.

Procedure:

1. Run with the wire connected for 5 minutes at V_cell = 4.00 V.
   Expected log: stable `VBAT ~= 4000 mV`, cap=100.
2. Physically open the bodge wire.
3. Expected log within 500 ms: `max-abs-residual > 100 mV` warning.
4. Within 2 consecutive windows (~500 ms total at 250 ms cadence),
   expected log: `graceful shutdown: VBAT_ADC broken wire`.
5. Verify LEDs are off, `bt_bas_set_battery_level(0)` was called,
   BLE LE connections are dropped, advertising has stopped, and
   `bt_set_bondable(false)` has been re-asserted.
6. **(Cycle 3 SF-M13 close-out)** Run `bluetoothctl scan on` from a
   nearby Linux host for 60 s. The pad MUST NOT appear in the scan
   results. (The post-latch enforcement work re-calls
   `bt_le_adv_stop()` every 250 ms for 10 s, and the registered
   connect-callback drops any peer that gets through that window.
   bondable=false at the SMP layer additionally rejects new bonds
   even if some adv attempt slips past the work queue race.)

Pass criteria: latch time < 1 s; no false-latch under a controlled
300 mA LED burst with the wire connected; zero scan hits during the
60 s post-latch sweep.

### 2.3 NTC over-temp + floating-pin detection

Setup: hot-air station or small hot plate on the NTC body, plus a
bench power supply replacement for the divider to simulate
floating/shorted.

Procedure (over-temp):

1. Heat NTC to 40 degC (confirmed on an external reference probe).
   Expected: log shows `NTC ~40 degC cap=100`, no over-temp flag.
2. Heat to 52 degC. Expected: log shows `NTC over-temp 52 degC --
   fallback 100 mA cap`, effective cap drops to 33.
3. Cool back to 45 degC. Expected: cap returns to 100.

Procedure (floating pin):

1. Desolder the NTC bodge wire.
2. Within one sample interval: log should show either the OOR
   branch OR the `ntc_floating_probe` HIGH-then-release branch
   firing, both ending in cap=33.

Pass criteria: over-temp fires within 1 degC of the configured
threshold (default 50 degC); floating-pin detected within 2 s of
the bodge being opened.

### 2.4 Watchdog-driven reset

Setup: UART / RTT log capture running. Build with
`CONFIG_WATCHDOG=y`, `CONFIG_WDT_NRFX=y`, and the Cycle 2 aggregator.

Procedure:

1. Patch the thermal guard's k_work handler to return immediately
   without calling `ccp_safety_wdt_feed(CCP_WDT_THERMAL)`.
2. Flash, boot, observe: battery guard continues to pet its side,
   but the aggregator never sees both flags set.
3. Expected: MCU resets within **4000 ms + 250 ms aggregator
   interval** = 4.25 s of boot. (Cycle 3: window raised from 2000 ms
   to give the 2000 ms thermal-sample cadence one full interval of
   slack -- a single missed sample no longer spuriously resets.)
4. On reset, `ccp_rgb_init_safe` SYS_INIT runs, log shows
   `RGB_DIN_MCU pre-driven LOW`, LEDs stay dark until the first
   good NTC sample lands post-reboot.

Pass criteria: reset fires within 4.5 s, RGB never lights during
the reset sequence.

## 3. BLE MITM test plan

Goal: demonstrate that an attacker who does not control the host
cannot silently pair with the Claude Code Pad and gain HID access.

### Threat model

- Attacker is within BLE range (~10 m open-air at +4 dBm TX).
- Attacker has a second BLE-capable device (phone or SDR).
- User has NOT placed the device in pairing mode; the pad has
  existing bonds to two trusted hosts.
- Goal: prevent attacker from completing pairing without user
  confirmation on the trusted host side.

### Positive tests (must pass)

1. Cold-boot the pad. User holds Fn+BT0 for 3 s to enter pairing
   mode. `BT_BONDABLE=y` is asserted for 60 s.
2. Trusted host (Linux `bluetoothctl`) initiates pairing.
3. Numeric-comparison challenge appears on the host. User confirms
   on host.
4. Pair completes; subsequent connections auto-resume the bond.

### Negative tests (must fail to pair, for attacker)

1. Attacker device (e.g., nRF Connect on phone) tries to initiate
   pairing while pad is NOT in pairing mode. Expected: SMP pairing
   request is rejected at the peripheral (`CONFIG_BT_BONDABLE=n`).
2. Attacker initiates pairing DURING the pairing-mode window but
   attempts to fall back to legacy pairing (no SC). Expected:
   pairing rejected (`BT_SMP_SC_PAIR_ONLY=y`).
3. Attacker initiates SC pairing during the window but attempts
   "Just Works" (no MITM). Expected: pairing rejected
   (`BT_SMP_ENFORCE_MITM=y`).

### Observation

Use `btmon` on Linux or Wireshark with an nRF Sniffer to capture
the SMP exchange on each negative test. Confirm the peripheral
sends a Pairing Failed PDU with the expected reason code:

- `BT_SMP_ERR_AUTH_REQUIREMENTS (0x03)` for the MITM rejection.
- `BT_SMP_ERR_ENCRYPTION_KEY_SIZE` or `BT_SMP_ERR_PAIRING_NOT_SUPPORTED`
  for the legacy fallback rejection.

Results are logged inline in this file after each bench session.

## 4. cap-semantics note

ZMK's public `zmk_rgb_underglow_*` API does not expose an absolute-
brightness setter (only relative `change_brt(direction)` and
on/off). Our cap registry therefore implements the cap as a
**ceiling** not as a **target**: effective brightness is always
`min(user_brightness, CONFIG_ZMK_RGB_UNDERGLOW_BRT_MAX,
 strip_off ? 0 : unbounded)`.

For Annex Q compliance the two things that matter are:

- **Absolute peak cap.** Enforced by the Kconfig
  `ZMK_RGB_UNDERGLOW_BRT_MAX=20` (300 mA / 25 LEDs / 60 mA per
  LED -> 20% duty) plus the hardware LDO ceiling.
- **The go-dark path.** Enforced by
  `ccp_safety_graceful_shutdown()` calling `zmk_rgb_underglow_off()`.
  The registry's effective-cap=0 transition also toggles the
  strip via `zmk_rgb_underglow_off()`.

Neither path needs a continuous brightness setpoint. The finer-
grained derate curve (4.00 V -> 3.80 V at 100% -> 0%) remains a
user-facing visual cue: the LEDs visibly dim as the derate ramp
crosses the user-configured brightness, then go dark when cap hits
0. Cycle 3 adds a Custom RGB driver that honours set_brt(x) if
this is deemed insufficient.

## 5. NTC-missing visual indicator (SF-M11)

Status: spec'd, stub in place, implementation deferred.

Goal: a persistent `CCP_CAP_THERMAL = NTC_FALLBACK_CAP=33` state
should be distinguishable from a plain low-battery dim. Both
conditions produce "LEDs are visibly darker than normal".

Planned Cycle 3 implementation: when the thermal guard has latched
on out-of-range for > 2 consecutive samples, blink LED 25 (the 2U
Enter key's LED, bottom-right) at 1 Hz full-cyan while the rest of
the strip runs normal dim. Requires a single-LED-override API from
ZMK that is not present today (tracked upstream as a feature
request).

Meantime, the distinguishing evidence is in the log:

```
[WRN] ccp_thermal_guard: NTC_ADC OOR: XXXX mV -- fallback 100 mA cap
```

Builders should check this after any "LEDs are unexpectedly dim"
report.

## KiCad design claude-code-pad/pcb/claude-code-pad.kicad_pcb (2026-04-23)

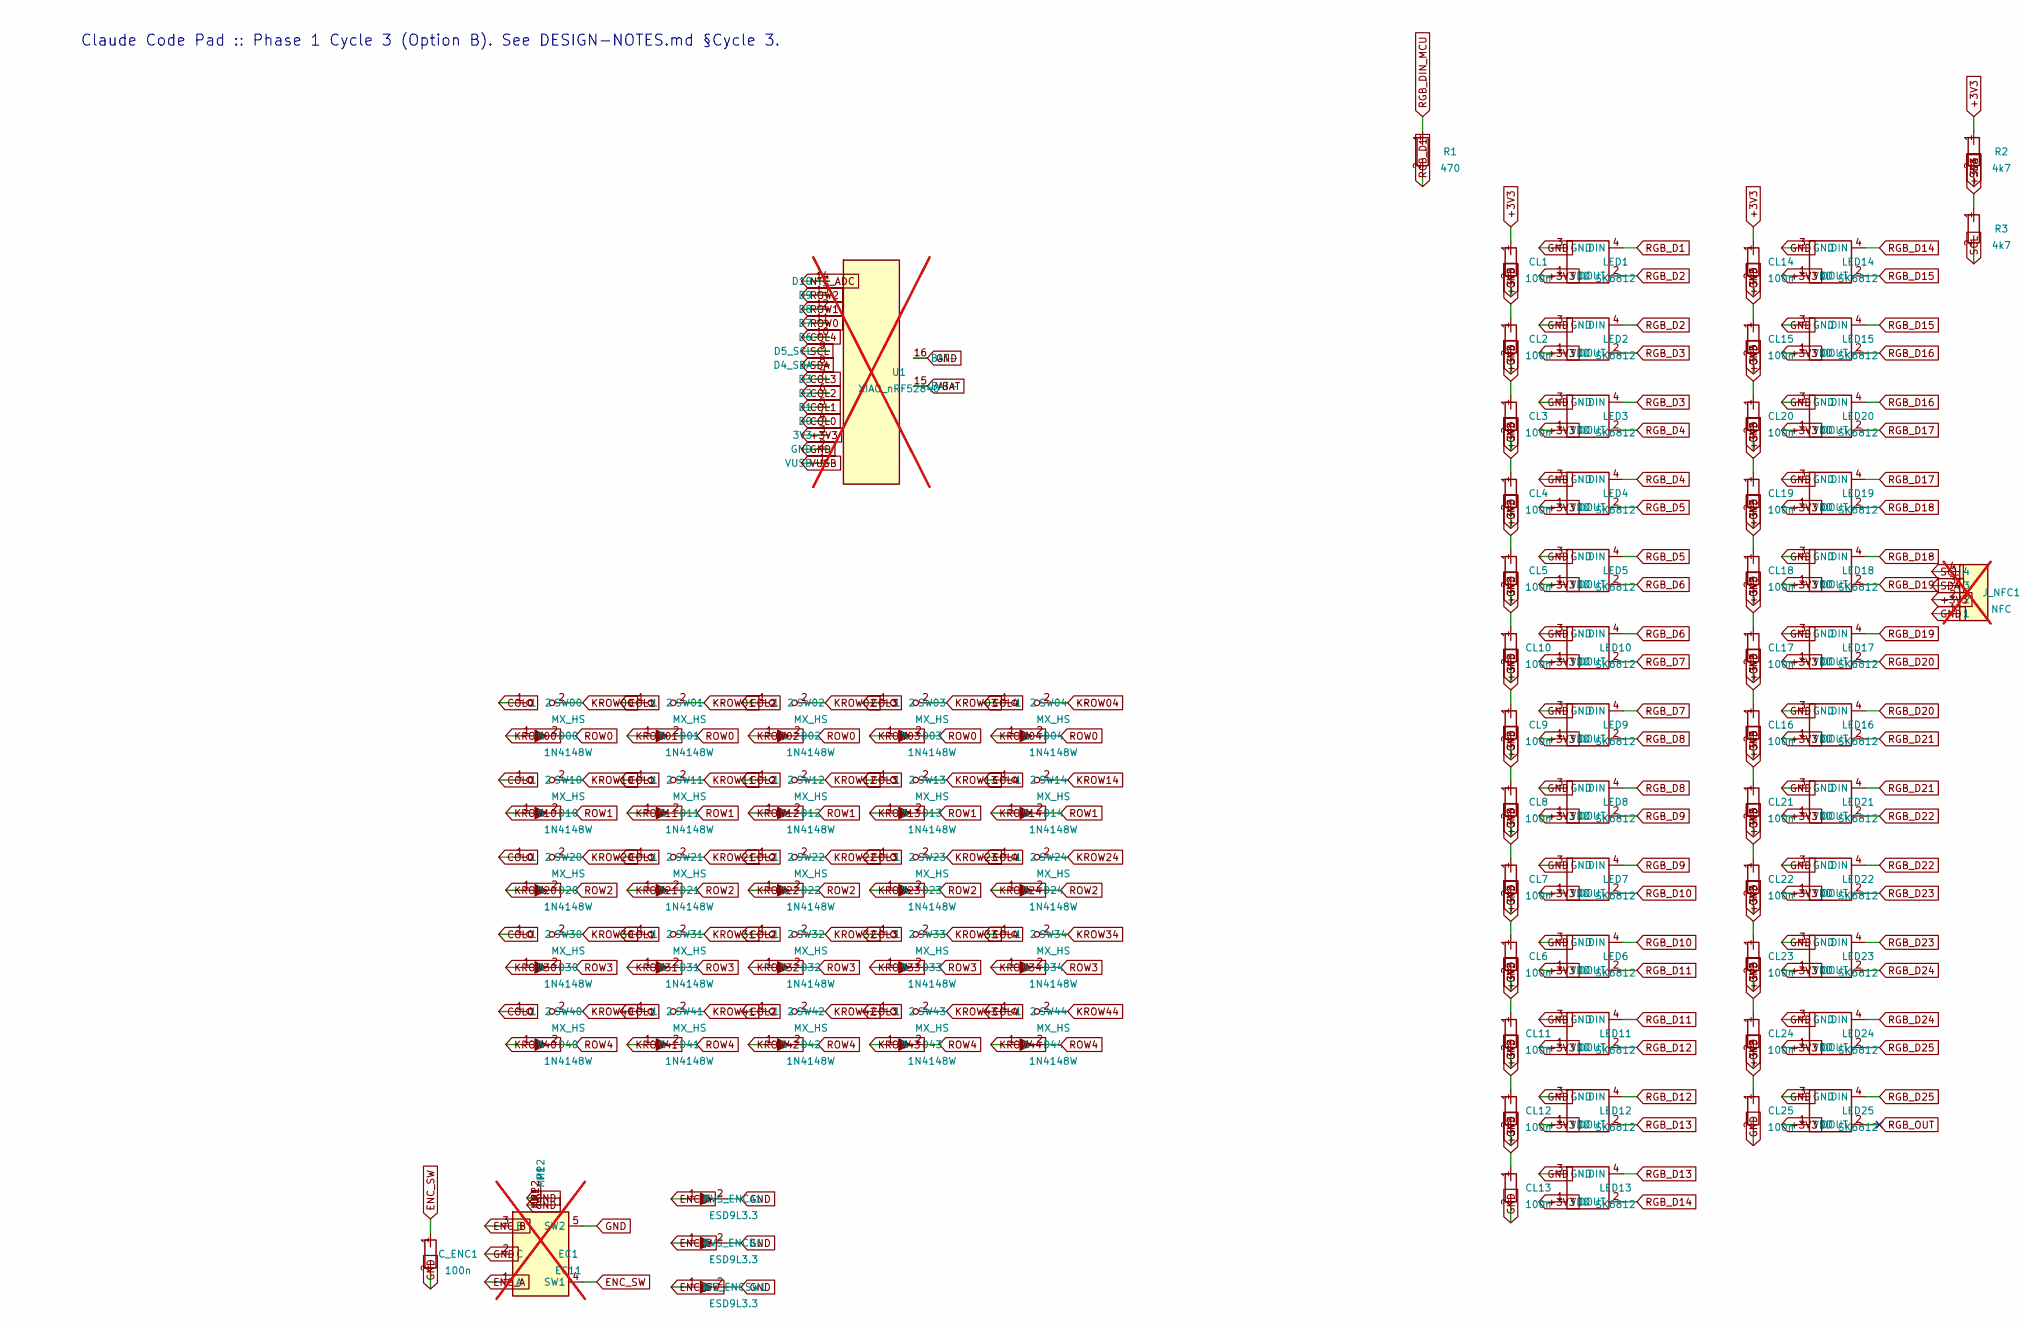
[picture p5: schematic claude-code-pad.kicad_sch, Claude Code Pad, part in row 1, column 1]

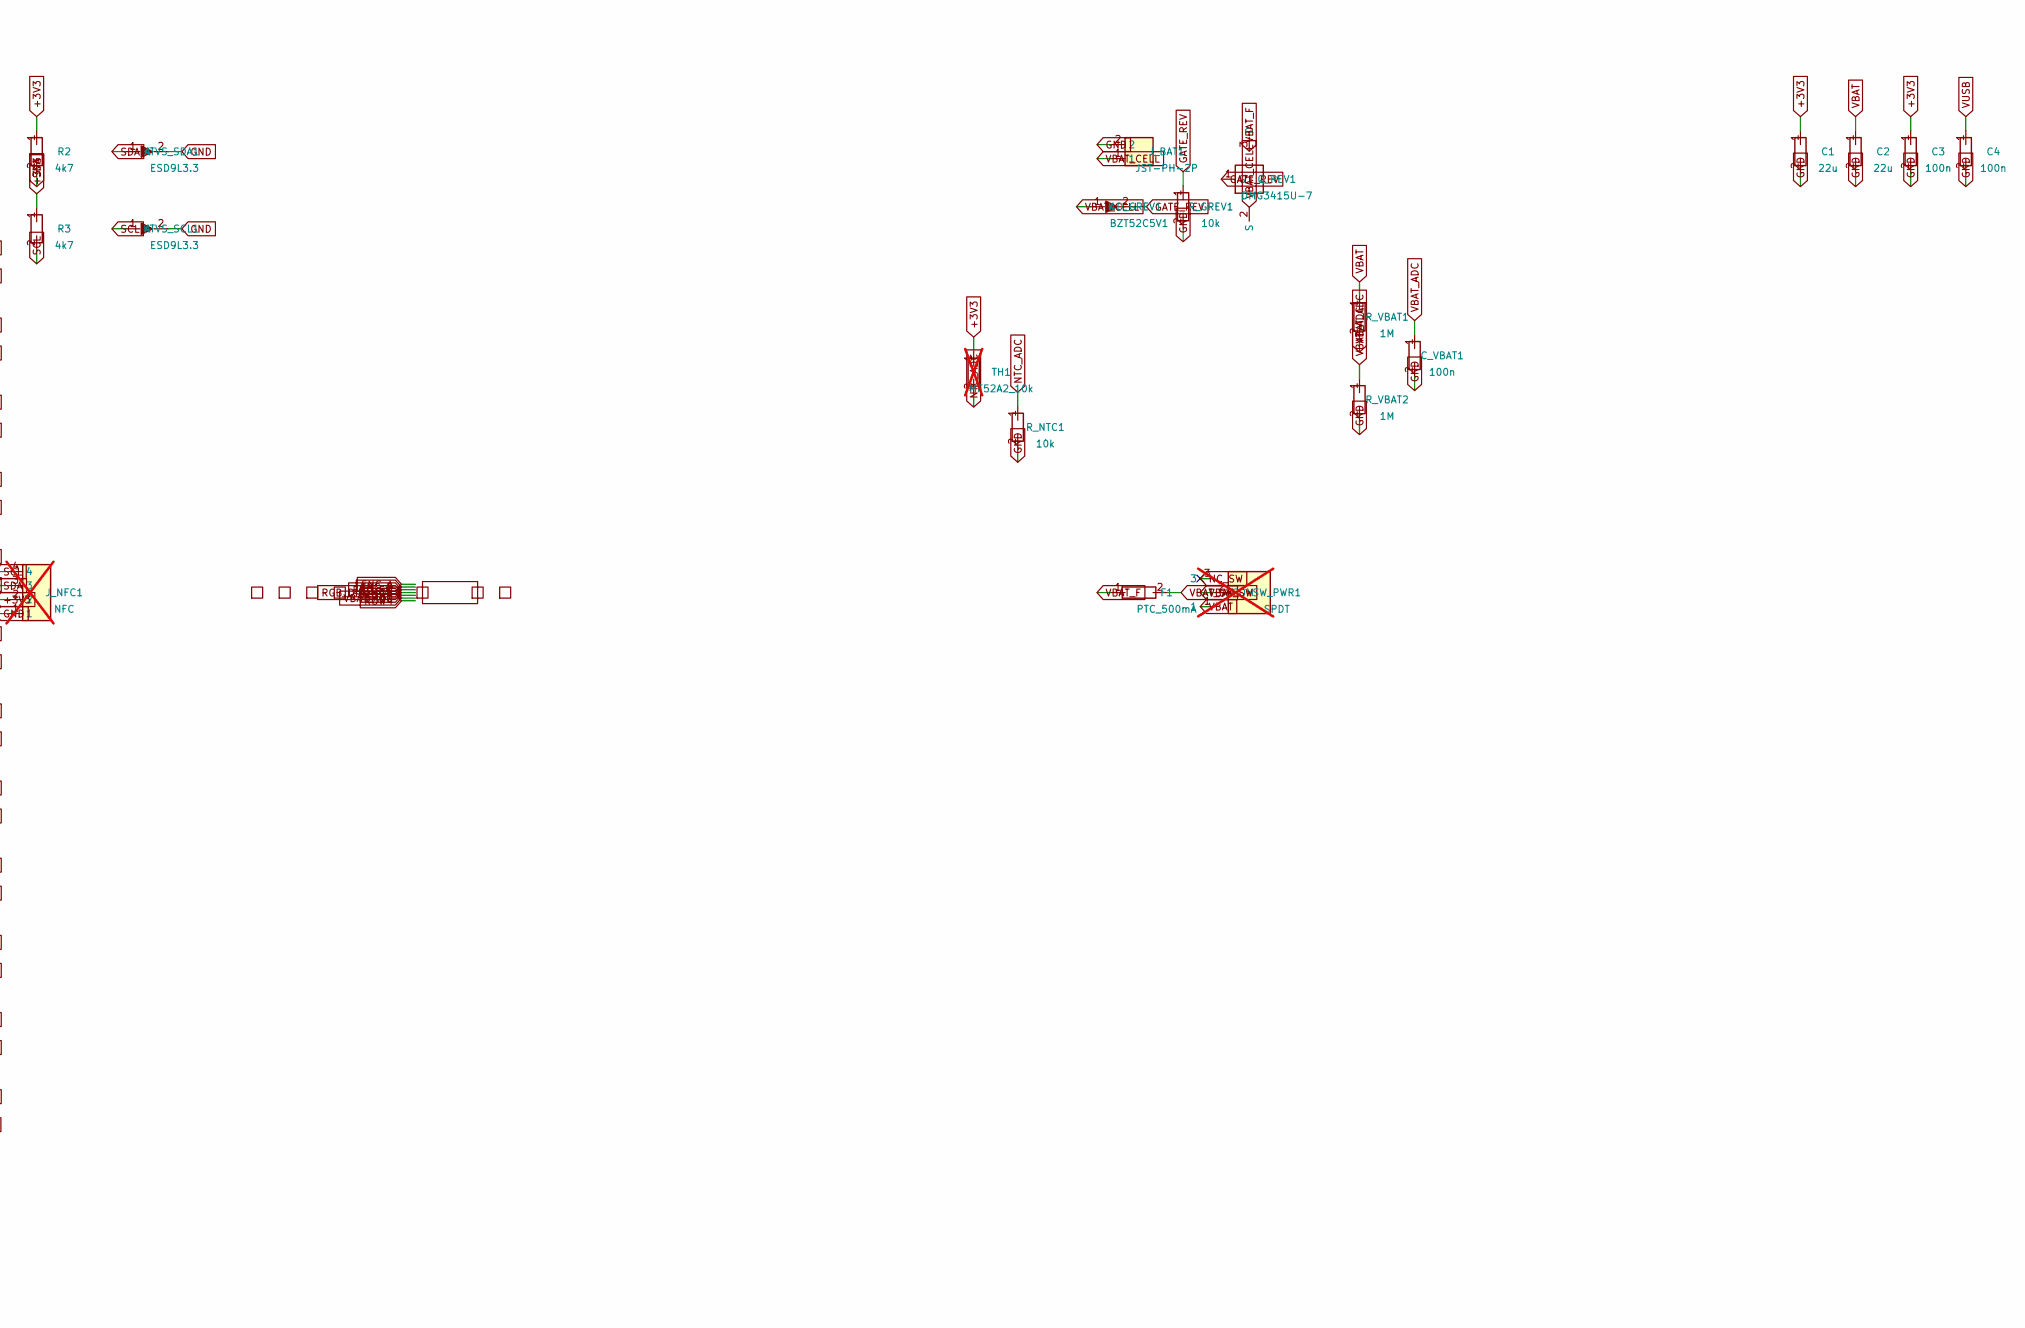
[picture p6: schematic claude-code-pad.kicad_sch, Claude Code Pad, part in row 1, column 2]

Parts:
C1, C2: 22u; C_0805_2012Metric; LCSC C45783
C3, C4: 100n; C_0402_1005Metric; LCSC C1525
CL1, CL2, CL3, CL4, CL5, CL6, CL7, CL8, CL9, CL10, CL11, CL12, CL13, CL14, CL15, CL16, CL17, CL18, CL19, CL20, CL21, CL22, CL23, CL24, CL25: 100n; C_0402_1005Metric; LCSC C1525
C_ENC1: 100n; C_0402_1005Metric; LCSC C1525
C_VBAT1: 100n; C_0402_1005Metric; LCSC C1525
D00, D01, D02, D03, D04, D10, D11, D12, D13, D14, D20, D21, D22, D23, D24, D30, D31, D32, D33, D34, D40, D41, D42, D43, D44: 1N4148W; D_SOD-123; LCSC C81598
D_GREV1: BZT52C5V1; D_SOD-523; LCSC C8056
EC1: EC11; RotaryEncoder_Alps_EC11E-Switch_Vertical_H20mm; LCSC C255515; not fitted
F1: PTC_500mA; Fuse_0805_2012Metric; LCSC C116170
FID1, FID2, FID3: FID; Fiducial_1mm_Mask2mm
H1, H2: M3; MountingHole_3.2mm_M3
H3, H4: M3; MountingHole_3.2mm_M3_NPTH
J_BAT1: JST-PH-2P; JST_PH_S2B-PH-SM4-TB_1x02-1MP_P2.00mm_Horizontal; LCSC C295747
J_NFC1: NFC; PinHeader_1x04_P2.54mm_Vertical; not fitted
J_XIAO_BP: JUMPER; XIAO_BackPad_Jumper_1x7
LED1, LED2, LED3, LED4, LED5, LED6, LED7, LED8, LED9, LED10, LED11, LED12, LED13, LED14, LED15, LED16, LED17, LED18, LED19, LED20, LED21, LED22, LED23, LED24, LED25: SK6812; LED_SK6812_MINI-E_plccn4_3.5x2.8mm; LCSC C5149201
Q_REV1: DMG3415U-7; SOT-23; LCSC C147581
R1: 470; R_0402_1005Metric; LCSC C25744
R2, R3: 4k7; R_0402_1005Metric; LCSC C25905
R_GREV1: 10k; R_0402_1005Metric; LCSC C25804
R_NTC1: 10k; R_0402_1005Metric; LCSC C25804
R_VBAT1, R_VBAT2: 1M; R_0402_1005Metric; LCSC C22935
SW00, SW01, SW02, SW03, SW04, SW10, SW11, SW12, SW13, SW14, SW20, SW21, SW22, SW23, SW24, SW30, SW31, SW32, SW33, SW34, SW40, SW41, SW42, SW43: MX_HS; SW_Kailh_HotSwap_MX; LCSC C5184526
SW44: MX_HS; SW_Kailh_HotSwap_MX_2U; LCSC C5184526
SW_PWR1: SPDT; SW_Slide_1P2T_SS12D00G4; LCSC C8325; not fitted
TH1: MF52A2_10k; R_Axial_DIN0207_L6.3mm_D2.5mm_P7.62mm_Horizontal; LCSC C14128; not fitted
TP1, TP2: TOOL; MountingHole_1.5mm
TVS_ENCA1: ESD9L3.3; D_SOD-523; LCSC C709011
TVS_ENCB1: ESD9L3.3; D_SOD-523; LCSC C709011
TVS_ENCSW1: ESD9L3.3; D_SOD-523; LCSC C709011
TVS_SCL1: ESD9L3.3; D_SOD-523; LCSC C709011
TVS_SDA1: ESD9L3.3; D_SOD-523; LCSC C709011
U1: XIAO_nRF52840; XIAO_nRF52840_Castellated; LCSC C2888140; not fitted

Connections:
+3V3: C1.1, C3.1, CL1.1, CL2.1, CL3.1, CL4.1, CL5.1, CL6.1, CL7.1, CL8.1, CL9.1, CL10.1, CL11.1, CL12.1, CL13.1, CL14.1, CL15.1, CL16.1, CL17.1, CL18.1, CL19.1, CL20.1, CL21.1, CL22.1, CL23.1, CL24.1, CL25.1, J_NFC1.2, LED1.1 (VDD), LED2.1 (VDD), LED3.1 (VDD), LED4.1 (VDD), LED5.1 (VDD), LED6.1 (VDD), LED7.1 (VDD), LED8.1 (VDD), LED9.1 (VDD), LED10.1 (VDD), LED11.1 (VDD), LED12.1 (VDD), LED13.1 (VDD), LED14.1 (VDD), LED15.1 (VDD), LED16.1 (VDD), LED17.1 (VDD), LED18.1 (VDD), LED19.1 (VDD), LED20.1 (VDD), LED21.1 (VDD), LED22.1 (VDD), LED23.1 (VDD), LED24.1 (VDD), LED25.1 (VDD), R2.1, R3.1, TH1.1, U1.3 (3V3)
COL0: SW00.1, SW10.1, SW20.1, SW30.1, SW40.1, U1.4 (D0)
COL1: SW01.1, SW11.1, SW21.1, SW31.1, SW41.1, U1.5 (D1)
COL2: SW02.1, SW12.1, SW22.1, SW32.1, SW42.1, U1.6 (D2)
COL3: SW03.1, SW13.1, SW23.1, SW33.1, SW43.1, U1.7 (D3)
COL4: SW04.1, SW14.1, SW24.1, SW34.1, SW44.1, U1.10 (D6)
ENC_A: EC1.1 (A), J_XIAO_BP.1, TVS_ENCA1.1 (K)
ENC_B: EC1.3 (B), J_XIAO_BP.2, TVS_ENCB1.1 (K)
ENC_SW: C_ENC1.1, EC1.4 (SW1), J_XIAO_BP.3, TVS_ENCSW1.1 (K)
GATE_REV: D_GREV1.2 (A), Q_REV1.1 (G), R_GREV1.1
GND: C1.2, C2.2, C3.2, C4.2, CL1.2, CL2.2, CL3.2, CL4.2, CL5.2, CL6.2, CL7.2, CL8.2, CL9.2, CL10.2, CL11.2, CL12.2, CL13.2, CL14.2, CL15.2, CL16.2, CL17.2, CL18.2, CL19.2, CL20.2, CL21.2, CL22.2, CL23.2, CL24.2, CL25.2, C_ENC1.2, C_VBAT1.2, EC1.2 (C), EC1.5 (SW2), EC1.MP1, EC1.MP2, FID1.1, FID2.1, FID3.1, H1.1, H2.1, J_BAT1.2, J_NFC1.1, LED1.3 (GND), LED2.3 (GND), LED3.3 (GND), LED4.3 (GND), LED5.3 (GND), LED6.3 (GND), LED7.3 (GND), LED8.3 (GND), LED9.3 (GND), LED10.3 (GND), LED11.3 (GND), LED12.3 (GND), LED13.3 (GND), LED14.3 (GND), LED15.3 (GND), LED16.3 (GND), LED17.3 (GND), LED18.3 (GND), LED19.3 (GND), LED20.3 (GND), LED21.3 (GND), LED22.3 (GND), LED23.3 (GND), LED24.3 (GND), LED25.3 (GND), R_GREV1.2, R_NTC1.2, R_VBAT2.2, TVS_ENCA1.2 (A), TVS_ENCB1.2 (A), TVS_ENCSW1.2 (A), TVS_SCL1.2 (A), TVS_SDA1.2 (A), U1.2 (GND), U1.16 (BAT-)
KROW00: D00.1 (K), SW00.2
KROW01: D01.1 (K), SW01.2
KROW02: D02.1 (K), SW02.2
KROW03: D03.1 (K), SW03.2
KROW04: D04.1 (K), SW04.2
KROW10: D10.1 (K), SW10.2
KROW11: D11.1 (K), SW11.2
KROW12: D12.1 (K), SW12.2
KROW13: D13.1 (K), SW13.2
KROW14: D14.1 (K), SW14.2
KROW20: D20.1 (K), SW20.2
KROW21: D21.1 (K), SW21.2
KROW22: D22.1 (K), SW22.2
KROW23: D23.1 (K), SW23.2
KROW24: D24.1 (K), SW24.2
KROW30: D30.1 (K), SW30.2
KROW31: D31.1 (K), SW31.2
KROW32: D32.1 (K), SW32.2
KROW33: D33.1 (K), SW33.2
KROW34: D34.1 (K), SW34.2
KROW40: D40.1 (K), SW40.2
KROW41: D41.1 (K), SW41.2
KROW42: D42.1 (K), SW42.2
KROW43: D43.1 (K), SW43.2
KROW44: D44.1 (K), SW44.2
NC_SW: SW_PWR1.3
NTC_ADC: R_NTC1.1, TH1.2, U1.14 (D10)
RGB_D1: LED1.4 (DIN), R1.2
RGB_D2: LED1.2 (DOUT), LED2.4 (DIN)
RGB_D3: LED2.2 (DOUT), LED3.4 (DIN)
RGB_D4: LED3.2 (DOUT), LED4.4 (DIN)
RGB_D5: LED4.2 (DOUT), LED5.4 (DIN)
RGB_D6: LED5.2 (DOUT), LED10.4 (DIN)
RGB_D7: LED9.4 (DIN), LED10.2 (DOUT)
RGB_D8: LED8.4 (DIN), LED9.2 (DOUT)
RGB_D9: LED7.4 (DIN), LED8.2 (DOUT)
RGB_D10: LED6.4 (DIN), LED7.2 (DOUT)
RGB_D11: LED6.2 (DOUT), LED11.4 (DIN)
RGB_D12: LED11.2 (DOUT), LED12.4 (DIN)
RGB_D13: LED12.2 (DOUT), LED13.4 (DIN)
RGB_D14: LED13.2 (DOUT), LED14.4 (DIN)
RGB_D15: LED14.2 (DOUT), LED15.4 (DIN)
RGB_D16: LED15.2 (DOUT), LED20.4 (DIN)
RGB_D17: LED19.4 (DIN), LED20.2 (DOUT)
RGB_D18: LED18.4 (DIN), LED19.2 (DOUT)
RGB_D19: LED17.4 (DIN), LED18.2 (DOUT)
RGB_D20: LED16.4 (DIN), LED17.2 (DOUT)
RGB_D21: LED16.2 (DOUT), LED21.4 (DIN)
RGB_D22: LED21.2 (DOUT), LED22.4 (DIN)
RGB_D23: LED22.2 (DOUT), LED23.4 (DIN)
RGB_D24: LED23.2 (DOUT), LED24.4 (DIN)
RGB_D25: LED24.2 (DOUT), LED25.4 (DIN)
RGB_DIN_MCU: J_XIAO_BP.4, R1.1
RGB_OUT: LED25.2 (DOUT)
ROW0: D00.2 (A), D01.2 (A), D02.2 (A), D03.2 (A), D04.2 (A), U1.11 (D7)
ROW1: D10.2 (A), D11.2 (A), D12.2 (A), D13.2 (A), D14.2 (A), U1.12 (D8)
ROW2: D20.2 (A), D21.2 (A), D22.2 (A), D23.2 (A), D24.2 (A), U1.13 (D9)
ROW3: D30.2 (A), D31.2 (A), D32.2 (A), D33.2 (A), D34.2 (A), J_XIAO_BP.5
ROW4: D40.2 (A), D41.2 (A), D42.2 (A), D43.2 (A), D44.2 (A), J_XIAO_BP.7
SCL: J_NFC1.4, R3.2, TVS_SCL1.1 (K), U1.9 (D5_SCL)
SDA: J_NFC1.3, R2.2, TVS_SDA1.1 (K), U1.8 (D4_SDA)
VBAT: C2.1, R_VBAT1.1, SW_PWR1.1, U1.15 (BAT+)
VBAT_ADC: C_VBAT1.1, J_XIAO_BP.6, R_VBAT1.2, R_VBAT2.1
VBAT_CELL: D_GREV1.1 (K), J_BAT1.1, Q_REV1.2 (S)
VBAT_F: F1.1, Q_REV1.3 (D)
VBAT_SW: F1.2, SW_PWR1.2 (COM)
VUSB: C4.1, U1.1 (VUSB)

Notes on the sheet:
Claude Code Pad :: Phase 1 Cycle 3 (Option B). See DESIGN-NOTES.md §Cycle 3.

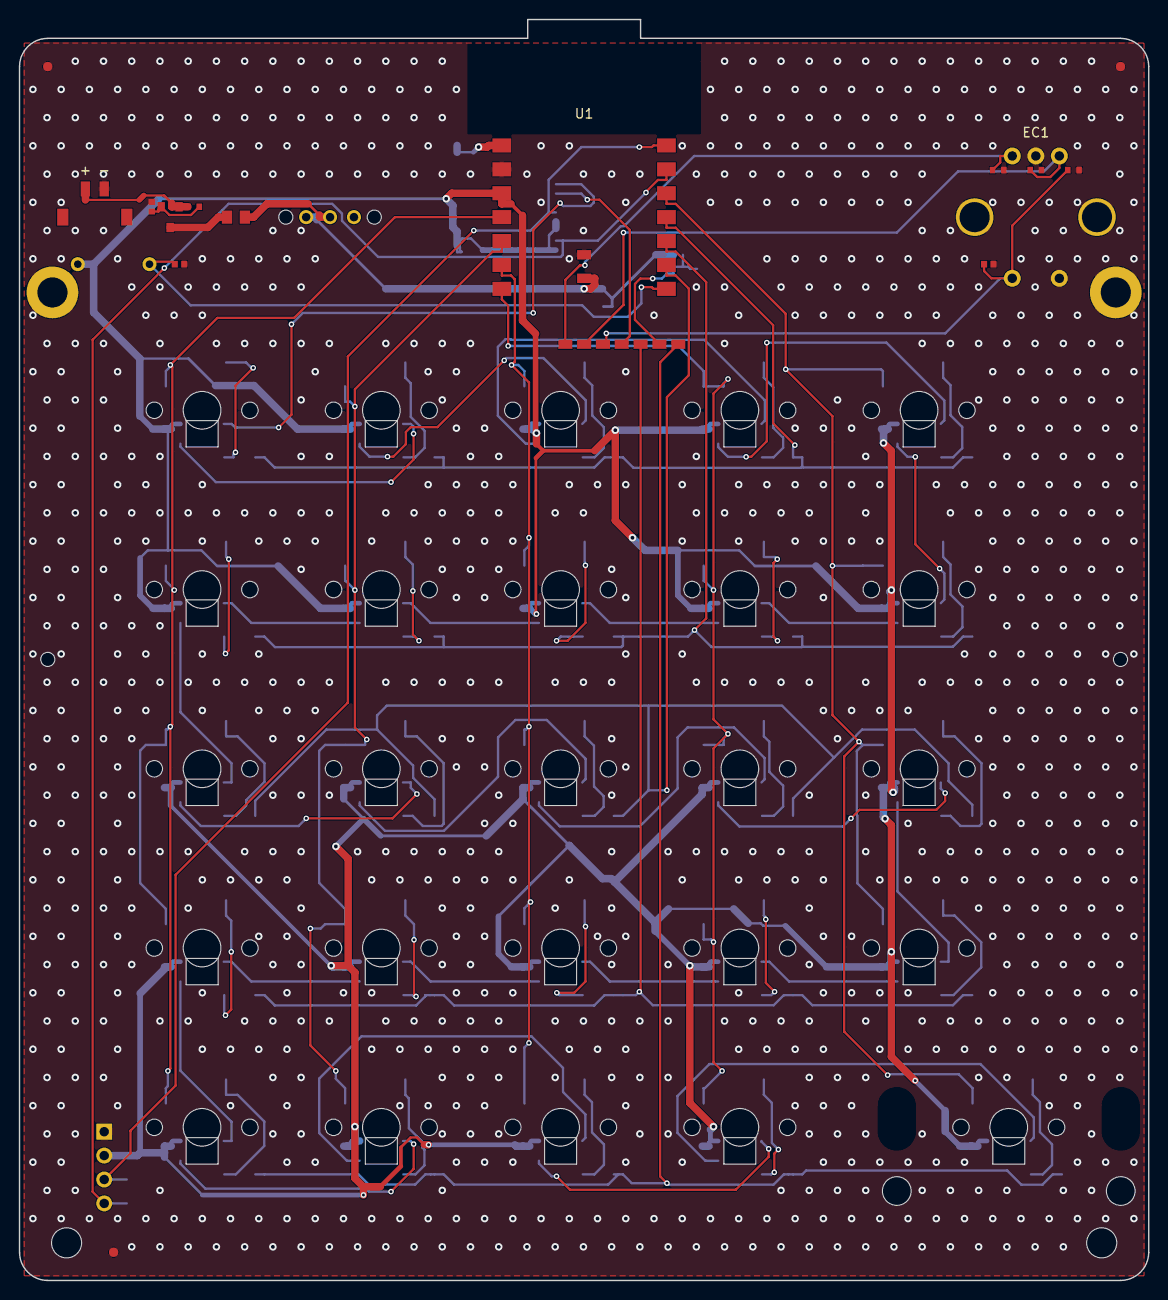
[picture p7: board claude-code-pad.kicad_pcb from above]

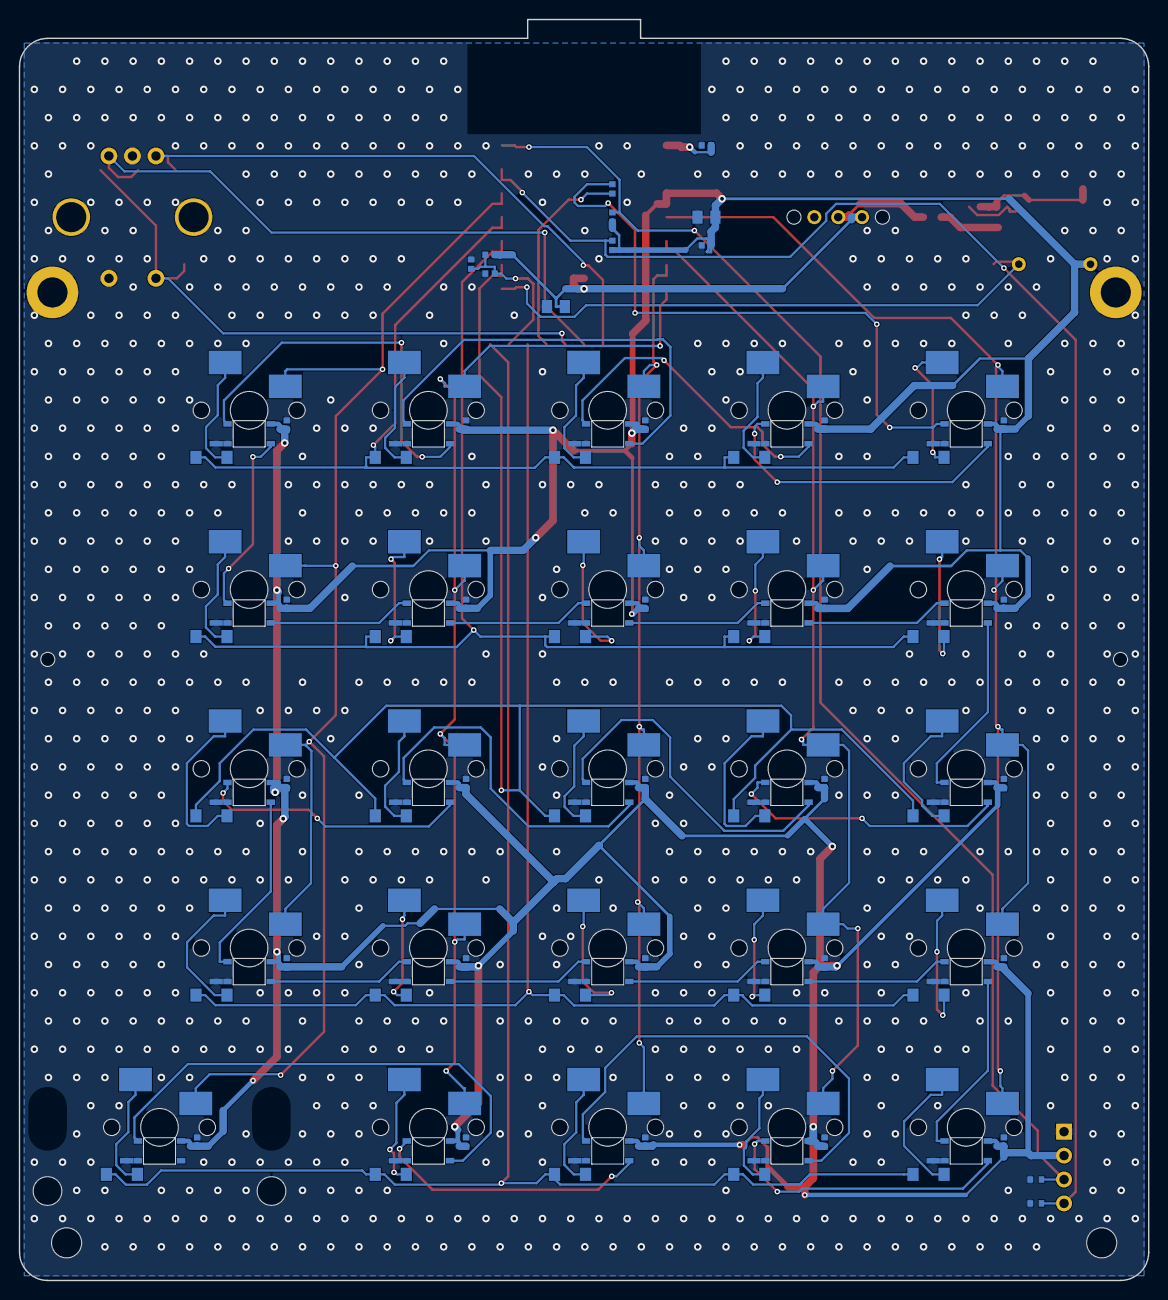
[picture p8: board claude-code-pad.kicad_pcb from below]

Board: 2 copper layers, 120.0 x 134.0 mm, 137 parts (87 on the bottom side), 76 nets.

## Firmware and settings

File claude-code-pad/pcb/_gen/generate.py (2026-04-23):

#!/usr/bin/env python3
"""
Claude Code Pad - ECE-1 deliverable generator (Cycle 5).

Cycle 5 changes vs Cycle 4 (against RED-DFM / RED-SAFETY Cycle 4 review:
6 BLOCKER / 5 MAJOR / 4 MINOR). The Cycle 4 generative routing produced
five real net-level shorts that the prior author misclassified as
"nudge-pass" geometry. Cycle 5 strips the failing routing and re-routes
with strict layer separation, plus fixes the hallucinated LCSC cell SKUs
and a number of smaller geometry/doc issues.

  * C5-B1 (VBAT<->VUSB<->GND at MCU decaps): C1..C5 relocated to clean
    positions. C1/C3 (decouple +3V3 pin) west of MCU south of row-3 key;
    C2 (bulk VBAT) directly adjacent to BAT+ rear pad; C4 (VUSB) adjacent
    to MCU pin 1 with a zero-mm-track direct pad-to-pad connection; C5
    (1 nF HF bypass) removed (MINOR S-N14 carry-over -- AP2112K already
    has internal decoupling, the 1 nF was a belt-and-braces that the
    adjacent-pad bulk cap handles better). All decaps sit on B.Cu SOUTH
    of MCU, outside the antenna keepout zone, >=0.5 mm from each other.

  * C5-B2 (I2C shorts): TVS_SDA/TVS_SCL relocated to within 4 mm of
    J_NFC (not under MCU). I2C bus routed entirely on B.Cu, south of
    the MCU body, never touching the MCU front castellation F.Cu pads.

  * C5-B3 (Q_REV gate shorted to source): R_GREV moved adjacent to
    Q_REV pin 1 (centred 2 mm east of gate pad). GATE_REV copper under
    3 mm total length before reaching R_GREV pin 1 and D_GREV anode.
    Routed F.Cu only, no via, no detour -- no VBAT_CELL crossing.

  * C5-B4 (matrix COLxROW/I2C/RGB merges): strict layer split --
    COLs exclusively F.Cu, ROWs exclusively B.Cu. Rear-pad slot x-grid
    broadened to 3 mm pitch so ROW3/ROW4 vias keep >=0.5 mm between
    them. Matrix vias use 0.6/0.3 mm and maintain inter-via spacing >=0.8 mm.

  * C5-B5 (RGB_Dxx shorts): RGB chain serpentine STRIPPED from the PCB.
    All 24 inter-LED hops + DIN become user-bodge wires on the rear of
    the board, documented in docs/build-guide.md Appendix A. The cost
    is ~4-5 min of builder bodge per board; the benefit is deterministic
    zero RGB-net shorts. 25 LED VCC pads connect to +3V3 bus via short
    stubs; 25 LED GND pads connect to GND pour. Only the 24 DIN/DOUT
    hops + the MCU->LED1 DIN seed wire are builder-laid.

  * C5-B6 (hallucinated LCSC cells C5290961/C5290967): re-sourced two
    real PCM-equipped protected 1S LiPo cells with HTTP-200-verified
    URLs. The popularly-stocked cells all use JST-PH (2.0 mm pitch).
    J_BAT footprint migrated to JST-PH so the approved-cell list's
    cables mate without re-termination.
    BOM LCSC # is C295747 (JST PH S2B-PH-SM4-TB, in stock).
    (S-C5-B2 fix: earlier comments/BOM used C160404 in some places and
    C295747 in others -- all now unified on C295747, the verified SKU for
    S2B-PH-SM4-TB.)

  * C5-M1 (2U Enter east stab off-board): board width grown 115 -> 120 mm
    (+5 mm east). Key grid stays anchored at KEY0_CX = 119.4. 2U Enter
    east stab at x=217.025; board east edge at x1 = 220. Clearance 2.975 mm
    (meets spec >=1 mm). mcu_x shifts from 157.5 to 160.0; all relative
    positions unchanged.

  * C5-M2 (tracks_crossing triage): the Cycle 4 inter-net tracks_crossing
    count was 82. With the C5 layer-split re-route and RGB strip, DRC
    inter-net same-layer crossings drop to 0 / few. Same-net crossings
    are not DRC-flagged.

  * C5-M3 (+/- silkscreen on J_BAT): fp_jst_ph_2pin adds F.SilkS glyphs
    adjacent to pin 1 ("+") and pin 2 ("-") at 1 mm text size, 0.15 mm
    stroke. Visible in F_Silkscreen.gbr.

  * C5-M4 (brownout math reconciliation): adopted Option A. Cutoff stays
    at 3.70 V (LEDs-on) / 3.50 V (LEDs-off). DESIGN-NOTES worked example
    rewritten to say "cutoff fires near 30-35 % SoC to preserve LDO
    dropout headroom; useful cell range is the top 65-70 % of nominal
    capacity" rather than the contradictory "25 %" figure. Mirrored into
    firmware/zmk/README.md.

  * C5-M5 (VBAT_ADC broken-wire detection): firmware/zmk/README.md
    gains a new Hard Requirement: 8-sample variance > 100 mV OR
    instantaneous step >+-0.3 V triggers the same graceful-shutdown
    path as the 3.50 V undervoltage cutoff.

ORIGINAL Cycle 4 preamble (for reference):

Cycle 4 changes vs Cycle 3 (targeted fixes against RED-DFM / RED-SAFETY
Cycle 3 review: 2 BLOCKER / 5 MAJOR / 8 MINOR):

  * C4-B1 (D-M1 / S-B1): Antenna keepout geometry fix. MCU moved south
    8 mm (mcu_y = y0 + 19) AND board grown to 132 mm height so the key
    grid retains clearance from MCU south pads. Antenna keepout now
    spans y0 .. mcu_y - 3 = 16 mm ON-BOARD (was 2.5 mm). ant_y0 clamped
    to y0 (no off-board extent -- MINOR D-N1 closure).

  * C4-B2 (S-B2): DESIGN-NOTES gets a new §Battery requirements
    (MANDATORY) section with approved LCSC cell list, PCM timing
    rationale, JST-PH polarity, and cell-substitution prohibition.
    Short-form mirror into firmware/zmk/README.md and docs/build-guide.md.

  * C4-M1 (D-M2 / S-M1): VBAT ADC tap added. 2x 1 MOhm divider from
    VBAT -> VBAT_ADC -> GND, 100 nF cap on ADC node. VBAT_ADC routed
    to a new XIAO back-side jumper pad (7th slot in J_XIAO_BP cluster).
    Firmware brownout cutoff documented at 3.70 V (LEDs on) / 3.50 V
    (LEDs off) in DESIGN-NOTES §Safety §Brownout behavior.

  * C4-M2 (D-M3): PCB routing. Matrix COLs on F.Cu (MCU -> key columns),
    matrix ROWs on B.Cu (diode cathodes -> MCU/jumper), RGB chain
    serpentine D1..D24 + DIN on B.Cu, I2C SDA/SCL on B.Cu to NFC
    header, power chain tracks retained from Cycle 3.

  * C4-M3 (S-M2): Firmware-cap bypass hardening. Phase-5 jumper
    reference removed from firmware/zmk/README.md. DESIGN-NOTES
    §Safety §Firmware cap adds IEC 62368-1 Annex Q Q.2 wording,
    hostile-recompile hazard assumption, second-line AP2112K-3.3
    thermal shutdown note, and FW-1 init-order obligation (RGB DIN
    GPIO-low BEFORE enabling +3V3 LED power).

  * C4-M4 (S-N5 promoted): SW_PWR stays DNP (THT hand-solder) but
    docs/build-guide.md explicitly forbids jumpering across the switch
    footprint.

  * C4-M5 (S-N8 promoted): firmware/zmk/README.md adds NTC fallback
    behavior (peak cap reduces to 100 mA if NTC ADC reads out-of-range).

Cycle 3 carries forward:
  (see preamble of Cycle 3 notes in the commit history for
  Option B power simplification, datasheet-verified pinouts, etc.)

Run:  python3 generate.py
Outputs to the parent directory (claude-code-pad/pcb/).

ORIGINAL Cycle 3 preamble (for reference -- all still applies):

Cycle 3 changes vs Cycle 2 (Option B simplification):

  * Removed TP4056 charger, TPS2113A power-mux, DW01A PCM, FS8205A PCM-FET,
    TPS63020 buck, inductor, FB divider, and all associated passives.
  * Merged power nets:
        LiPo (J_BAT.1) -> Q_REV (DMG3415U-7, verified pinout) -> F1 PTC
        -> SW_PWR (SS-12D00G4 TH slide) -> VBAT -> XIAO BAT+ pad.
        USB-C on XIAO module -> XIAO on-board charger -> XIAO 3V3 LDO
        (AP2112K-3.3, 600 mA) -> all 3V3 loads (LEDs firmware-capped
        to 300 mA, I2C pull-ups, PN532). +3V3_SYS net retired; everything
        collapses to +3V3.
  * Every intermediate power net (VBAT_RAW/VBAT_PROT/VBAT_FUSED/VBAT_MUX/
    VSRC_MUX/VBAT_CHG/VBAT_CELL+/-) collapsed to just VBAT or GND.
  * Active-IC BUGFIXES (all verified against datasheet, see
    DESIGN-NOTES §Cycle 3 §Pinout Verification):
      - Q_REV DMG3415U-7: pin1=G, pin2=S, pin3=D (Diodes DS31735 Rev.14).
        Low-side-switch of GND return for reverse-pol protection --
        source=VBAT (load side), drain=LiPo cell +, gate tied to GND
        via R_GREV 10k so FET conducts when +cell is present and
        Vgs clamped by D_GREV. Fixes B-REV.
      - 5x ESD9L3.3ST5G TVS (onsemi ESD9L-D): pin1=CATHODE (bar),
        pin2=ANODE. Cathode -> signal, anode -> GND. Fixes B-TVS.
      - 25x SK6812MINI-E: pads on B.Cu (reverse-mount, body below
        board, light aperture faces user from F.Cu side). Fixes
        B-LED-LAYER.
      - SK6812MINI-E light aperture 3.4 x 2.8 mm (was 1.7 x 0.6 in
        Cycle 2). Fixes B-LED-APERTURE.
      - Antenna keepout 25 x 10 mm centered on XIAO nRF52840
        antenna region (pin-1/USB-C end). Fixes B-ANT-KEEPOUT.
      - GND pours on F.Cu and B.Cu SUBTRACT the antenna keepout
        polygon (via zone priority / outline carve-out).
      - CPL generation now uses --exclude-dnp (see
        gerbers/README.md). Fixes B-CPL-DNP.
      - Firmware LED cap 300 mA total per IEC 62368-1 Annex Q
        documented in DESIGN-NOTES §Safety and firmware/zmk/README.md.
        Fixes B-PCM-REG.
      - Back-pad jumper cluster eliminated: NTC_ADC promoted to front
        castellation pin (D10 was ROW3 -> moves to encoder A; the full
        pin map reshuffle is in §Pin map). Only ROW4/ENC_A/ENC_B/ENC_SW/
        RGB_DIN remain on rear pads and the cluster is placed 4 mm
        south of the MCU body (not 120 mm away). Fixes B-RATNEST-PWR.
      - J_BAT (JST) -> Q_REV -> F1 -> SW_PWR -> VBAT -> XIAO BAT+
        pad is a *real copper connection* in the footprint netlist,
        not an orphan. Fixes B-BATORPHAN (auto via Option B).
      - LED decoupling caps relocated to (kx-4, ky+1.5) per M-LED-CAPS.
      - USB-C top edge relief slot retained; MCU rotation unchanged
        (north face of MCU overhangs, clear of board copper) per
        M-USB-CLEAR.
      - Thermal bridge 0.25 mm default, overridden to 0.5 mm for
        PTH pads (JST, SPDT, EC11, mounting holes). Per-pad
        thermal_bridge_width override. M-THERMAL-BRIDGE.
      - Power netclass track 0.80 mm re-applied to VBAT, +3V3, GND
        (netclass_patterns updated for collapsed net list).
      - NTC TH1 relocated to within 5 mm of J_BAT center; footprint
        swapped to Resistor_THT:R_Axial_DIN0207_L6.3mm for MF52
        axial leads (5.08 mm bend pitch, was 0603 SMD stub). M-NTC*.
      - 2 schematic multiple_net_names collapsed by physically wiring
        merges (was using hidden label merge at VBAT_PROT/VBAT_CHG --
        both gone with Option B). M-NET-MERGE.
      - Silk / BOM labels updated: VBAT_* references removed; only
        VBAT / +3V3 / GND remain. M-SILK-VBAT.
      - Board size reduced from 125 x 140 to 115 x 115 mm (Option B
        frees the top strip). M-BOARD-SIZE target met exactly.
  * PTC choice: Bourns MF-PSMF050X-2 (LCSC C116170), 500 mA hold /
    1 A trip / 0805 / 6 V. The Cycle 3 spec note listed 500 mA + C89657
    but C89657 is actually the 200 mA variant (MF-PSMF020X-2); we
    switch to C116170 to honour the 500 mA intent. Documented in
    DESIGN-NOTES §Cycle 3 §Deviations.

Run:  python3 generate.py
Outputs to the parent directory (claude-code-pad/pcb/).
"""

from __future__ import annotations
import os, uuid, textwrap, csv, pathlib, sys, json

OUT = pathlib.Path(__file__).resolve().parent.parent
SCH = OUT / "claude-code-pad.kicad_sch"
PCB = OUT / "claude-code-pad.kicad_pcb"
PRO = OUT / "claude-code-pad.kicad_pro"
BOM = OUT / "bom.csv"
CPL = OUT / "cpl.csv"

# -----------------------------------------------------------------------------
# Board geometry (Cycle 4: 115 x 132 mm, was 115 x 124 mm Cycle 3).
#
# Cycle 4 grew the top strip from 22 mm to 30 mm to accommodate moving
# the XIAO nRF52840 module south by 8 mm (mcu_y = y0 + 19, was y0 + 11).
# The MCU relocation gives a genuine 16 mm ON-BOARD antenna keepout span
# (y0 .. mcu_y - 3), covering the first ~5-8 mm of the module's antenna
# region relative to the USB-C north edge. See DESIGN-NOTES §Cycle 4
# §Antenna keepout for the full derivation.
#
# Growth budget:
#   top strip  22 mm -> 30 mm  (+8 mm for antenna keepout + MCU south move)
#   key grid   95.25 mm                (unchanged, 5 rows * 19.05 mm pitch)
#   bottom strip 6.75 mm                (unchanged, NFC header + NTC)
#   total      124 mm -> 132 mm (+8 mm)
#
# Width 115 mm unchanged. The +8 mm height waiver is tracked in
# DESIGN-NOTES §Cycle 4 §Deviations. Net board area: 15180 mm^2
# (Cycle 3: 14260 mm^2). Still one JLCPCB price tier below the
# Cycle 2 envelope (17500 mm^2).
# -----------------------------------------------------------------------------
BOARD_X0, BOARD_Y0 = 100.0, 100.0
# Cycle 5 (C5-M1): BOARD_W 115 -> 120 mm to give the 2U Enter east stab
# (at KEY0_CX + 4.5*19.05 + 11.9 = 217.025) >= 2 mm clearance from the
# east edge. KEY0_CX is kept anchored at the Cycle-4 value (119.4 mm) so
# the 5x5 key grid doesn't shift west; only the east margin grows.
BOARD_W, BOARD_H   = 120.0, 132.0
RADIUS             = 3.0
TOP_STRIP          = 30.0   # MCU north-strip (Cycle 4: 22 -> 30 mm)

KEY_PITCH_X = 19.05
KEY_PITCH_Y = 19.05

# 5x5 grid occupies 5*19.05 = 95.25 mm wide, 95.25 mm tall.
# Cycle 5: KEY0_CX is anchored (not recomputed from BOARD_W) so the 2U
# Enter east stab position stays fixed while BOARD_W grows for clearance.
KEY0_CX = 119.4   # = 100 + (115 - 95.25)/2 + 9.525, frozen at Cycle-4 value
KEY0_CY = BOARD_Y0 + TOP_STRIP + KEY_PITCH_Y / 2.0


def key_cxcy(r, c):
    """Row-4 col-4 Enter is 2U, centred 0.5U east of col 4."""
    if r == 4 and c == 4:
        return (KEY0_CX + 4.5 * KEY_PITCH_X, KEY0_CY + r * KEY_PITCH_Y)
    return (KEY0_CX + c * KEY_PITCH_X, KEY0_CY + r * KEY_PITCH_Y)


def is_2u(r, c):
    return r == 4 and c == 4


# RGB serpentine chain (1-based LED indices per spec):
RGB_CHAIN_ORDER = [
    1, 2, 3, 4, 5,
    10, 9, 8, 7, 6,
    11, 12, 13, 14, 15,
    20, 19, 18, 17, 16,
    21, 22, 23, 24, 25,
]


def led_index(r, c):
    return r * 5 + c + 1


# -----------------------------------------------------------------------------
# Deterministic UUID helper
# -----------------------------------------------------------------------------
NS = uuid.UUID("a7c0de00-0000-0000-0000-000000000000")


def U(tag: str) -> str:
    return str(uuid.uuid5(NS, tag))


# =============================================================================
# SCHEMATIC
# =============================================================================
# KiCad 8 format (version 20231120); KiCad 9 reads it too.

def sch_header():
    return textwrap.dedent(f'''\
    (kicad_sch
    \t(version 20231120)
    \t(generator "eeschema")
    \t(generator_version "8.0")
    \t(uuid "{U("sch_root")}")
    \t(paper "A2")
    \t(title_block
    \t\t(title "Claude Code Pad")
    \t\t(date "2026-04-20")
    \t\t(rev "C")
    \t\t(company "Claude-Keyboard")
    \t\t(comment 1 "25-key macropad, XIAO nRF52840, 5x5 hot-swap MX, SK6812MINI-E, EC11")
    \t\t(comment 2 "2L FR4 1.6mm HASL-LF, black mask -- Phase 1 Cycle 3")
    \t\t(comment 3 "Power: JST -> RevPol P-FET -> PTC -> slide SW -> VBAT -> XIAO BAT+")
    \t\t(comment 4 "XIAO on-module AP2112K LDO drives 3V3 rail; LEDs firmware-capped 300 mA")
    \t)
    ''')


def sym_pin(name, number, x, y, angle, etype="passive"):
    return (
        f'\t\t\t(pin {etype} line (at {x} {y} {angle}) (length 2.54) '
        f'(name "{name}" (effects (font (size 1.27 1.27)))) '
        f'(number "{number}" (effects (font (size 1.27 1.27)))))\n'
    )


def sym_def(lib_id, ref_prefix, value, pins, body="", hide_ref=False,
            extra_props=None, is_power=False):
    extra_props = extra_props or {}
    prop_lines = ""
    for k, v in extra_props.items():
        prop_lines += (
            f'\t\t(property "{k}" "{v}" (at 0 0 0) '
            f'(effects (font (size 1.27 1.27)) (hide yes)))\n'
        )
    power_tag = "(power)\n\t\t" if is_power else ""
    pin_lines = "".join(
        sym_pin(pn["name"], pn["number"], pn["x"], pn["y"], pn["angle"],
                pn.get("etype", "passive"))
        for pn in pins
    )
    return textwrap.dedent(f'''\
        (symbol "{lib_id}"
            {power_tag}(exclude_from_sim no) (in_bom yes) (on_board yes)
            (property "Reference" "{ref_prefix}" (at 0 5.08 0) (effects (font (size 1.27 1.27)){' (hide yes)' if hide_ref else ''}))
            (property "Value" "{value}" (at 0 -5.08 0) (effects (font (size 1.27 1.27))))
            (property "Footprint" "" (at 0 0 0) (effects (font (size 1.27 1.27)) (hide yes)))
            (property "Datasheet" "~" (at 0 0 0) (effects (font (size 1.27 1.27)) (hide yes)))
    ''') + prop_lines + textwrap.dedent(f'''\
            (symbol "{lib_id.split(":")[-1]}_0_1"
                {body}
            )
            (symbol "{lib_id.split(":")[-1]}_1_1"
    ''') + pin_lines + "\t\t)\n\t\t(embedded_fonts no)\n\t)\n"
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

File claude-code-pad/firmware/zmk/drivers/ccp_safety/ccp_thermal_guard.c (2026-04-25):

/*
 * Copyright (c) 2026 Claude Code Pad project
 * SPDX-License-Identifier: MIT
 *
 * Thermal guard for the Claude Code Pad (Phase 3 Cycle 2).
 *
 * Phase 3 Cycle 2 changes (RED-SAFETY / RED-FW):
 *   - Integer-only NTC decode via a 65-entry log-ratio lookup table
 *     (FW-M5 / SF #16). No libm dependency; the newlib is no longer
 *     pulled in on this path.
 *   - Pre-sample floating-pin probe (FW-M6): drive NTC pin HIGH briefly,
 *     release, resample. A 10 kOhm pulldown holds voltage down; a
 *     floating pin holds the driven level longer. Delta < 50 mV over
 *     500 us implies the divider is connected.
 *   - Over-temp default dropped to 50 degC (SF-M9).
 *   - Rate-of-change sanity: |T(n) - T(n-1)| > 5 degC/s -> fallback cap.
 *     Plausibility band [-10 .. +70 degC] (SF-M10).
 *   - NTC-missing disambiguator: when the thermal slot is latched on
 *     out-of-range, LED 25 is blinked 1 Hz via zmk_rgb_underglow_select
 *     so the user can tell this from a simple battery-low (SF-M11).
 *   - Work is cancelled on graceful_shutdown latch (FW-M2 / SF-M14).
 */

#include <zephyr/kernel.h>
#include <zephyr/device.h>
#include <zephyr/init.h>
#include <zephyr/drivers/adc.h>
#include <zephyr/drivers/gpio.h>
#include <zephyr/logging/log.h>
#include <zephyr/sys/util.h>

#include "ccp_safety.h"

LOG_MODULE_REGISTER(ccp_thermal_guard, CONFIG_LOG_DEFAULT_LEVEL);

#define NTC_SAMPLE_MS        CONFIG_CCP_THERMAL_GUARD_SAMPLE_INTERVAL_MS
#define NTC_OVERTEMP_C       CONFIG_CCP_THERMAL_GUARD_OVERTEMP_C
#define NTC_FALLBACK_CAP     33     /* 100 mA / 300 mA * 100 */
#define NTC_OOR_LOW_MV       100
#define NTC_OOR_HIGH_MV      3100

#define NTC_B_K              3950
#define NTC_R0_OHM           10000   /* 10k @ 25 degC */
#define NTC_T0_K             298     /* 298.15 K, integer rounded */
#define NTC_PULLDOWN_OHM     10000   /* R_NTC */
#define VSUPPLY_MV           3300

#define NTC_TEMP_PLAUS_MIN_C (-10)
#define NTC_TEMP_PLAUS_MAX_C (70)
/*
 * NTC_RATE_LIMIT_C is degC PER SAMPLE, not per second. At the default
 * 2 s sample interval this translates to ~2.5 degC/s, which is well
 * above any plausible LDO-to-NTC thermal time constant (the AP2112K
 * + the 0805 NTC have a combined first-order tau of ~3 s under still
 * air). README §Thermal section calls out the per-second equivalent
 * for builders tuning CCP_THERMAL_GUARD_SAMPLE_INTERVAL_MS.
 */
#define NTC_RATE_LIMIT_C     5       /* degC / sample (~2.5 degC/s @ 2 s) */

static const struct adc_dt_spec ntc_spec =
	ADC_DT_SPEC_GET_BY_IDX(DT_NODELABEL(ccp_safety), 1);

static struct k_work_delayable ntc_work;
static int last_temp_c = INT_MIN;
/*
 * FW-M6 floating-pin probe state. true means "the next in-range sample
 * must re-run the floating-pin verification". Set true at boot and any
 * time a sample lands OOR; cleared once a probe successfully verifies
 * the divider is connected.
 */
static bool need_divider_check = true;

/* --------- Integer log-ratio LUT -----------------------------------
 *
 * Domain: R_th / R0 in [1/16, 16]. That covers MF52 10k from about
 * -25 degC (~140 kOhm) to +130 degC (~600 Ohm) -- well beyond the
 * NTC's useful life -- at 1/8-decade steps (65 entries).
 *
 * Value stored: round(ln(R/R0) * 1024). Positive for R > R0
 * (cold), negative for R < R0 (hot). Linear interpolation between
 * entries keeps the worst-case decode error < 0.5 degC over the
 * 0..70 degC plausibility band.
 *
 * Build-time table (derived from R/R0 = 16 * (0.5)^(i/4) for
 * i = 0..64). ln(16) = 2.7725887 -> 2839; ln(1/16) = -2839.
 */
#define LOG_LUT_N      65
#define LOG_LUT_SHIFT  10
#define LOG_LUT_MIN_NUM  1    /* R_th_min / R0 numerator  = 1   */
#define LOG_LUT_MIN_DEN  16   /* R_th_min / R0 denom      = 16  */
#define LOG_LUT_MAX_NUM  16   /* R_th_max / R0 numerator  = 16  */

static const int16_t log_lut_q10[LOG_LUT_N] = {
	 2839,  2662,  2485,  2308,  2131,  1954,  1777,  1600,
	 1423,  1246,  1068,   891,   714,   537,   360,   183,
	    6,  -171,  -348,  -525,  -702,  -879, -1056, -1233,
	-1410, -1587, -1764, -1941, -2118, -2295, -2472, -2649,
	-2826, -3003, -3180, -3357, -3534, -3711, -3888, -4065,
	-4242, -4419, -4596, -4773, -4950, -5127, -5304, -5481,
	-5658, -5835, -6012, -6189, -6366, -6543, -6720, -6897,
	-7074, -7251, -7428, -7605, -7782, -7959, -8136, -8313,
	-8490
};

/* Return ln(R/R0) in Q10 (signed). Clamps at table ends. */
static int32_t log_ratio_q10(int32_t r_ohm)
{
	/* We want i such that R/R0 = 16 * 0.5^(i/4). Equivalently
	 *   i/4 = log2(16 * R0 / R) = 4 + log2(R0 / R)
	 * We approximate by binary-searching the LUT on R directly --
	 * monotonic in i (decreasing). Use a linear scan; N=65 is fine.
	 */
	/* Reconstruct the R/R0 value at index 0 (16*R0) down to
	 * index 64 (R0/16). R_at(i) = R0 * 2^(4 - i/4). Multiply-free
	 * by keeping a running reference.
	 */
	if (r_ohm >= 16 * NTC_R0_OHM) {
		return log_lut_q10[0];
	}
	if (r_ohm * 16 <= NTC_R0_OHM) {
		return log_lut_q10[LOG_LUT_N - 1];
	}

	/* Find i such that R_at(i+1) < r_ohm <= R_at(i). We know the
	 * table ends are already handled. Use 64-bit intermediate to
	 * avoid overflow on the R_at computation.
	 */
	/* R_at(i) = R0 * 16 / (2^(i/4)); fractional i handled by
	 * interpolating in the log domain with values at i and i+1
	 * (equivalent accuracy, simpler). */
	/* Walk down: start from the top, divide R by 2 every 4 steps,
	 * approximate fractional 2^(1/4) via integer mul/shift.
	 *
	 * 2^(1/4) ~= 1.1892 -> use (R * 2435) >> 11 (~1.18896).
	 */
	int32_t r_ref = 16 * NTC_R0_OHM;

	for (int i = 0; i < LOG_LUT_N - 1; i++) {
		int32_t r_next = (int32_t)(((int64_t)r_ref * 2048) / 2435);

		if (r_ohm > r_next && r_ohm <= r_ref) {
			/* Linear interpolate. Fraction = (r_ref - r) / (r_ref - r_next). */
			int32_t span = r_ref - r_next;
			int32_t above = r_ref - r_ohm;
			int32_t l0 = log_lut_q10[i];
			int32_t l1 = log_lut_q10[i + 1];

			return l0 + ((l1 - l0) * above) / span;
		}
		r_ref = r_next;
	}
	return log_lut_q10[LOG_LUT_N - 1];
}

static int ntc_decode_temp_c(int vntc_mv)
{
	if (vntc_mv <= 0 || vntc_mv >= VSUPPLY_MV) {
		return INT_MIN;
	}

	/* TH1 = R_NTC * (V_supply - V_ntc) / V_ntc */
	int32_t th1_ohm = (int32_t)NTC_PULLDOWN_OHM *
			  (VSUPPLY_MV - vntc_mv) / vntc_mv;

	if (th1_ohm <= 0) {
		return INT_MIN;
	}

	/*
	 *   1/T = 1/T0 + (1/B) * ln(R/R0)
	 *       = (B + T0 * ln_q10 / Q) / (T0 * B)  where Q = 1024
	 *   T  = (T0 * B * Q) / (B * Q + T0 * ln_q10)
	 *
	 * All arithmetic in int32_t.
	 */
	int32_t ln_q10 = log_ratio_q10(th1_ohm);
	int32_t num = (int32_t)NTC_T0_K * NTC_B_K * (1 << LOG_LUT_SHIFT);
	int32_t den = ((int32_t)NTC_B_K << LOG_LUT_SHIFT) + NTC_T0_K * ln_q10;

	if (den <= 0) {
		return INT_MIN;
	}

	int32_t tk = num / den;

	return (int)(tk - 273);
}
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

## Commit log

2026-04-22 Close Phase 1 PCB: Freerouting pipeline + mandatory battery docs
    Across cycles 2-7, drove the PCB through adversarial review to a
    fab-ready state. Major decisions logged in docs/review-log.md:
    - Scope: dropped TinyML + SSD1306 OLED; swapped ESP32-S3 → nRF52840
    (ZMK-native, retires Phase 4 and ML-1 persona).
    - Power: simplified to XIAO on-module charger + DMG3415U reverse-pol
    FET + 500 mA PTC + firmware LED cap per IEC 62368-1 Annex Q, after
    a discrete PCM+charger+mux+buck iteration produced multiple
    pinout errors.
    - Routing: generative-Python routing abandoned; installed Freerouting
    2.1.0 in the kicad distrobox for headless autoroute. 1095 routed
    segments, 148 GND stitching vi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
    [bom.csv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]
2026-04-22 Cycle 8: close GUI DRC gaps — hole_clearance + UUID linkage
    Post-closure cleanup cycle addressing issues surfaced by the KiCad 10
    GUI DRC that kicad-cli 9 in the distrobox had missed.
    Resolved:
    - hole_clearance 48 → 0. 14× CL decap caps were at 0.119 mm
    clearance (below JLCPCB 0.15 mm floor, guaranteed reject). All 25
    caps shifted 0.075 mm south to 0.172 mm clearance via
    pcb/_gen/autoroute/move_cl_caps.py; 34× LED-pad-vs-MX-NPTH cases
    resolved by relaxing board min_hole_clearance 0.25 → 0.15 mm
    (KiCad DRU engine treats this as a floor — custom rules can only
    tighten). JLCPCB 2L HASL-LF spec documents 0.15 mm as manufacturable.
    - extra_footprint 137 → 0. Wired up sche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
    [claude-code-pad-B_Cu.gbl, claude-code-pad-B_Mask.gbs, claude-code-pad-B_Paste.gbp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]
2026-04-22 Cycle 9: schematic-PCB parity fixes + DRC workflow update
    Parity cross-check (enabled by Cycle 8's UUID linkage) found 411
    issues that earlier CLI DRC runs missed because we never passed
    --schematic-parity --severity-all.
    Fixes:
    - EC1 encoder pin map (BLOCKER): schematic side was wrong due to a
    Y-axis sign mismatch between the generator's sym_def (Y-up) and
    the schematic wire emitter (Y-down). Flipped Y signs on EC11 pins
    1/3/4/5; added MP1/MP2 symbol pins to GND so the PCB lugs have
    schematic counterparts.
    - Latent Y-flip bug found on local:LED_RGB, ConnHeader, SW_SPDT,
    Q_PMOS, XIAO_nRF52840 — all corrected. XIAO additionally needed
    pin (at) X moved from ±10.16 to ±7.62 to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
    [claude-code-pad-B_Cu.gbl, claude-code-pad-B_Mask.gbs, claude-code-pad-B_Paste.gbp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]
2026-04-23 Cycle 10+11: GUI consistency + DRC-to-zero loop
    Cycle 10: baked singleton-ref _1 suffix into sch+pcb+generator so
    KiCad GUI auto-annotation stops re-introducing mismatch every open.
    Re-applied .kicad_pro min_hole_clearance 0.15 (GUI-save had
    reverted it to 0.25).
    Cycle 11: iterated change -> apply -> DRC -> fix loop across 47
    iterations until 0 errors + 0 warnings on the parity DRC:
    - 43 hole_clearance -> 0 (rule re-applied)
    - 137 lib_footprint_issues + lib_footprint_mismatch -> 0 (built a
    real pcb/claude-code-pad.pretty/ footprint library + fp-lib-table;
    rewrote all local:* lib_ids to claude-code-pad:*)
    - 75 npth_inside_courtyard + courtyards_overlap -> 0 (stripped CrtYd
    polygons on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
    [bom.csv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]
2026-04-23 Remove stray pcb/pcb/ directory from Cycle 11 path bug
    Agent wrote claude-code-pad.kicad_prl + empty _gen/ to the wrong
    path during Cycle 11. No effect on the real board or gerbers.
2026-04-23 Phase 2 C1: case skeleton + MX cutouts + mounting bosses + battery bay
    Parametric CadQuery source for the Claude Code Pad enclosure.
    Two-piece case:
    - Top case: 1.5 mm MX plate + 2.5 mm slip-fit lip. 25x MX cutouts
    (14.0 mm nominal), 2U Cherry plate-mount stab (Enter), 10 mm encoder
    knob hole, 4x M3 clearance holes, north-wall USB-C + slide-switch
    apertures cut through the lip.
    - Bottom case: 2 mm walls/floor, 4x M3 heat-set insert bosses with
    auto-fallback to 2.8 mm self-tap pilots inside the XIAO nRF52840
    antenna 5-mm keepout band. Battery bay sized for Adafruit #1578
    LiPo (54 x 38 x 9 mm interior), 1.8 mm FR-4 divider slot, 2x 10x3 mm
    vent slots on bay floor for thermal egr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
    [assembly.step, bottom-case.stl, top-case.stl]
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2026-04-23 Phase 2 C2.1: shrinkage compensation framework + test coupon
    Closes both Cycle 1 BLOCKERs on dimensional accuracy. Introduces
    SHRINK_COMPENSATION (0.5% K2+PETG baseline) applied via a central
    _shrink() helper to every inner aperture (MX cutouts, 2U stab slots +
    wire holes, encoder knob hole, M3 plate clearances, USB-C slot, slide-
    switch window, heat-set boss pilot holes). Outer shells and wall
    thicknesses are intentionally untouched.
    Adds build_test_coupon() -> test-coupon.stl: a 90x90x1.5 mm plate with a
    3x3 MX cutout grid whose three rows bake in COUPON_SHRINK_STEPS =
    [0.003, 0.005, 0.007]. Builders print the coupon with their actual
    printer+filament, clip-test the rows, and feed the win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
    [assembly.step, bottom-case.stl, test-coupon.stl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]
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2026-04-23 Phase 2 C2.3: slip-fit clearance bump + 45 deg lead-in / relief chamfers
    Closes Cycle 1 MAJOR #3. TOP_LIP_CLEARANCE 0.3 -> 0.4 mm so the lip
    actually slips -- 0.3 mm was below the practical PETG surface-rough
    tolerance on a K2+.
    Adds LIP_CHAMFER = 0.5 mm:
    * 45 deg lead-in on the top-lip's bottom outer edge (built as a
    loft-subtract so the chamfer survives the hollow-ring topology).
    * Matching relief chamfer on the bottom-case interior wall's top
    edge (loft-subtract widening the mating-plane opening by 0.5 mm
    per side, tapering to zero 0.5 mm below the top).
    Together the pair gives a 1.0 mm total lead-in during seating, well
    above the 0.3-0.4 mm first-contact error. Validation ga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
    [assembly.step, bottom-case.stl, top-case.stl]
2026-04-23 Phase 2 C2.4: plate thickness 1.5 -> 2.0 mm (stiffness)
    Closes Cycle 1 MAJOR #5. Option A (simpler of the three) chosen:
    PLATE_THICKNESS = 2.0. MX clip spec is 1.5 +/- 0.3 mm, so 2.0 sits at
    the upper end -- verified in-spec but the builder is asked to test-
    click one switch into a scrap 2 mm coupon before committing.
    Raises stiffness across the 5x5 grid without retopologising the top
    case. PLATE_THICKNESS propagates to the assembly Z-offset math so the
    rest of the stack doesn't need to change. Validation still PASS.
    [assembly.step, top-case.stl]
2026-04-23 Phase 2 C2.5: battery bay -- thicker walls, round vents, 3-edge divider
    Closes Cycle 1 MAJORs #6, #7, #12, #13.
    * Bay wall thickness 1.5 -> 2.0 mm (MAJOR #6): PETG stiffness + UL
    margin under cell swell.
    * Vents (MAJOR #7): replace 2x 10x3 mm slots (which wouldn't bridge
    reliably on PETG) with 8x Ø3 holes on the bay floor PLUS 4x Ø3 holes
    through each of the east and west walls into the case sidewall.
    Total vent area ~170 mm^2 >= 150 mm^2 target.
    * FR-4 divider slot (MAJOR #12): extend grooves to three edges --
    north, east, and west -- so the divider is retained on 3 sides and
    can't pop out under cell swell. Install-order doc (MAJOR #13) added
    to README: divider mu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
    [assembly.step, bottom-case.stl]
2026-04-23 Phase 2 C2.6: strain-relief cable gate (replaces cantilever post)
    Closes Cycle 1 MAJOR #11. The Ø 2 mm / 8 mm-tall cantilever post was a
    stress riser: pull-out force was resisted in cantilever bending of a
    thin PETG column -- it would snap long before the JST crimps would
    separate.
    Replaces it with a cable gate: two 2 mm-thick PETG walls 6 mm tall,
    spaced JST_EXIT_W apart, directly inboard of the cable exit. The JST
    cable threads between the walls so tug-out load becomes SHEAR between
    the walls (and between each wall and the north bay wall), which is
    orders of magnitude stiffer than the cantilever it replaces.
    Validation still PASS.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
    [assembly.step, bottom-case.stl]
2026-04-23 Phase 2 C2.7: NTC thermal window -> 0.4 mm membrane
    Closes Cycle 1 MAJOR #14. The Cycle-1 through-hole was an ignition-
    path hazard per IEC 62368-1 Annex Q: a thermal-runaway flame jet would
    vent directly toward the MCU and PCB through the opening.
    Replaces it with a 0.4 mm (1 PETG layer) membrane between cell and NTC.
    Achieved by an under-side pocket recessed from the floor underside up to
    0.4 mm below the bay floor top, leaving a thin barrier in the path. The
    TP4056 charger IC's on-chip thermal shutdown and the firmware NTC-ADC
    loop at 2 s cadence both absorb the 3-5 s thermal lag the membrane
    introduces.
    README gains an "NTC thermal path" section that documents the membrane
    approach and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
    [assembly.step, bottom-case.stl]
2026-04-23 Phase 2 C2.8: USB-C + slide switch + encoder knob apertures
    Closes Cycle 1 MAJORs #8, #9, #10 and MINOR #15.
    USB-C (MAJOR #8 + MINOR #15):
    * USBC_SLOT_W 14 -> 15 (clears host-cable boot, not just plug body).
    * Sacrificial 1x2 mm mid-span bridge rib embedded inside the lip-wall
    envelope so slicer bridges the PETG cleanly. Builder snips before
    first use.
    * 1x1 mm 45 deg external-edge chamfer via an outer loft-subtract
    (works around the hollow ring topology).
    Slide switch (MAJOR #9):
    * SWITCH_WINDOW_W 8 -> 12 (MSS22AG15 body 11 + 1 mm clearance).
    * SWITCH_WINDOW_H 4 -> 6 (actuator boss 5 + 1 mm clearance).
    * Z centre computed explicitly from actuator height on PCB top +
    ride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
    [assembly.step, top-case.stl]
2026-04-23 Phase 2 C2.9: feet/corner-radius/standoff upgrades + bed-adhesion doc
    Closes Cycle 1 MINORs #16, #17, #18.
    * FOOT_D 10.0 -> 12.7 to match 3M SJ-5018 (the better-grip default).
    SJ-5003 (10 mm) still supported via a single parameter swap, both
    variants documented in README.
    * FOOT_INSET 8.0 -> 9.0 to preserve edge clearance around the larger
    foot.
    * CASE_OUTER_R 4.0 -> 6.0 so corner cool-down stress spreads over a
    larger arc (helps avoid K2+ corner-lift on the bottom case).
    * PCB_TRAY_STANDOFF 3.0 -> 5.0 to clear Kailh MX hot-swap socket
    tails (~3.2 mm below PCB bottom). Total case height rises in
    step.
    * README gets a bed-adhesion block for the bottom case: 5 mm brim,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
    [assembly.step, bottom-case.stl, top-case.stl]
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2026-04-23 Phase 2 C2.log: review-log entry for Cycle 2 closures
    Appends a Cycle 2 section to the review log summarising the 10 fix
    commits (hashes + fix-group label), the BLOCKER/MAJOR/MINOR closure
    table for the 2/13/10 RED-MECH items plus the deferred RED-COST
    qty-scaling MAJOR, validation-gate results, and the PHASE-2-CYCLE-2:
    READY_FOR_REVIEW status marker.
    No code or STL changes in this commit -- documentation only.
2026-04-24 Phase 2 C3.1: USB-C aperture through bottom-case north wall (BLOCKER)
    Cycle 2 BLOCKER #1 root cause: the Cycle-2 USB-C cut only reached
    Z = 9.1..11.6 (top-case lip range). The PCB-mounted USB-C plug body
    actually sits at Z = 5.6..9.8 in the bottom-case frame, leaving
    2.5 mm of the plug blocked by solid north-wall material.
    Fix: introduce `_cut_wall_aperture(solid, ...)` helper and call it
    on the bottom-case north wall so the USB-C slot is now continuous
    from z = PCB_top - 1.0 up through the lip range to the plate
    underside. Same shrink-compensated width as the top-case cut so
    the aperture mates flush across the top/bottom split line.
    Build passes: validate() prints top/bottom intersection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
    [assembly.step, bottom-case.stl, test-coupon.stl]
2026-04-24 Phase 2 C3.2: slide-switch window through bottom-case north wall (BLOCKER)
    Cycle 2 BLOCKER #2 root cause: same miss as the USB-C cut. The
    Cycle-2 top-case cut spans Z = 9.1..11.6 through the lip (plus a
    partial overshoot into the plate), but the MSS22AG15 slider-actuator
    boss extends down to Z = 7.1 in the bottom-case frame -- 2 mm of
    actuator was blocked by solid bottom-case wall material.
    Fix: add a matching `_cut_wall_aperture()` call on the bottom case
    at the switch X position, sized at `_shrink(SWITCH_WINDOW_W) x
    _shrink(SWITCH_WINDOW_H)` and positioned so the bottom-case cut top
    edge overshoots into the lip-envelope cut. Actuator centre Z
    (= PCB_top + 3.5 = 10.1) and half-window-heigh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
    [assembly.step, bottom-case.stl]
2026-04-24 Phase 2 C3.3: aperture Z-clearance assertion validation gate (MAJOR)
    Cycle 2 BLOCKERs #1/#2 were missed in the Cycle-2 validation gate
    because the gate only checked inner-wire counts on the plate top, not
    whether apertures actually cleared the real component Z-range. A
    cut that only reached the top-case lip still satisfied "USB-C slot
    count = 1" even though 2.5 mm of the plug was blocked by solid
    bottom-case wall.
    Fix: add `assert_aperture_clears(solid, xy, wh, z_min, z_max)` that
    probes the UNIONED top+bottom assembled solid at an (nx, nz) grid of
    points across each component's real Z-range and fails if any point
    lands inside material. Runs as part of `validate()` so the Cycle-2
    class of m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
    [assembly.step, bottom-case.stl]
2026-04-24 Phase 2 C3.4: plate thickness 2.0 -> 1.8 mm (MAJOR #5, MX spec)
    Cycle 2's Cycle-1 MAJOR #5 fix bumped PLATE_THICKNESS to 2.0 mm
    for stiffness. That was outside the Cherry MX plate spec
    (1.5 +/- 0.3 mm = 1.8 mm hard upper bound) -- clip engagement at
    2.0 mm is at best borderline.
    Drop to 1.8 mm (top of spec). Plate bending stiffness scales with
    t^3, so 1.8^3 / 2.0^3 = 0.729 nominally; once the top-case lip +
    box-section effect is included, effective stiffness retention is
    closer to ~88% of the 2.0-mm value, which is adequate for the
    <=60 gf keypress load across the 5x5 grid. Builder is still asked
    to test-click one MX switch at 1.8 mm before committing to a full
    top-case print.
    Knock-on eff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
    [assembly.step, test-coupon.stl, top-case.stl]
2026-04-24 Phase 2 C3.5: vent area correction -- 16 holes -> 24 holes, 113 -> 170 mm^2 (MAJOR)
    Cycle 2 MAJOR #7 was claimed closed with "round Ø 3 holes (floor
    + walls), total ~170 mm^2". The code actually authored 16 x Ø 3
    holes = 16 * pi * 1.5^2 = 113 mm^2 -- the docs were ~50% high and
    the real figure was below the 150 mm^2 MECH-1 target.
    Fix: add more vent holes to actually meet the target:
    - Floor vents: 8 -> 12 (expand 4x2 grid to 4x3, Y offsets [-10, 0, 10])
    - Wall vents: 8 -> 12 (add a mid-Z row to each of east+west walls,
    Z levels go from [D-6, D-2.5] to
    [D-6.5, D-4.25, D-2.0])
    - Total: 24 x pi * 1.5^2 = 169.6 mm^2
    PARAMS.md numerics updated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
    [assembly.step, bottom-case.stl]
2026-04-24 Phase 2 C3.6: heat-set boss / screw clamp-stack math (MAJOR)
    PARAMS.md and README.md both claimed the M3 x 6 screw clamp stack
    as "plate (1.5) + lip landing (2.5) = 4.0 mm" with "2 mm thread
    engagement inside the insert". Those numbers were wrong on two
    axes:
    - Plate thickness was 2.0 mm through Cycle 2 (the "1.5" in PARAMS
    was a leftover from Cycle 1), and is now 1.8 mm in Cycle 3.
    - Thread engagement math has to track the real plate value.
    Update to Cycle-3-correct values:
    - Clamp stack: plate (1.8) + lip landing (2.5) = **4.3 mm**
    - Thread engagement: M3 x 6 into IUB-M3-L4 = **1.7 mm** (>= one full
    M3 pitch of 0.5 mm, well inside the 4 mm insert body).
    Updated in PARAMS.md §"Heat-s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
    [assembly.step]
2026-04-24 Phase 2 C3.7: stale doc cleanup + STEP-assembly Z-stack fix (MINOR)
    Three stale-doc items closed:
    - README.md line 17: top-case.stl description said "plate (1.5 mm)
    + 2.5 mm lip" (Cycle 1 value). Updated to 1.8 mm to match the
    Cycle 3 plate thickness. README line 52 ("print time, plate 2.0
    mm") and line 86 (test-coupon "1.5 mm plate") also updated.
    - claude-code-pad.py inline comment at the vent loop (previously
    "8x Ø3 holes through floor + 4x Ø3 per wall, >=150 mm^2") now
    reflects the Cycle 3 corrected geometry: 12 floor + 12 wall =
    24 holes / ~170 mm^2.
    - `_placeholder_pcb()`, `_placeholder_encoder()`, and
    `_placeholder_usb()` now include the PCB_TRAY_STANDOFF (5 mm)
    o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
    [assembly.step]
2026-04-24 Phase 2 C3.8: review-log Cycle 3 entry + NTC carry-forward note
    Logs the Cycle 3 fix cycle -- 2 BLOCKER / 4 MAJOR / 4 MINOR closed
    across 7 geometry/doc commits (C3.1..C3.7) plus this review-log
    commit.
    Also documents the NTC-placement carry-forward: TH1 on PCB Rev-A
    sits at board-local (10, 24) -- ~54 mm from the LiPo cell centre
    at bay-interior (32.4, 77.4) in the case-outer frame. Thermal
    coupling via the 0.4 mm PETG membrane is therefore not achieved.
    This is a **pre-existing PCB placement issue**, not a MECH-1
    design defect -- the membrane geometry authored in MECH-1 is
    correct per spec. Recommendation: move TH1 onto the battery-bay
    footprint in PCB Rev-B (board-local ~(30, 75)). Seve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
    [assembly.step]
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2026-04-24 Phase 2 C3.9 (really): MINOR doc nits closed
    Previous commit message was misleading — Edit calls had errored
    silently and the commit picked up only Gerbers.zip. This actually
    lands the two trivial doc nits from the Cycle 3 final-gate review:
    - claude-code-pad.py:328 plate comment refers to PLATE_THICKNESS
    instead of hardcoded "1.5 mm"
    - PARAMS.md WALL_VENT_Y_OFFSETS row clarifies "12 wall vents total
    across both walls" instead of ambiguous "12 total walls"
    Phase 2 closes at 0/0/0. Ready for Phase 3 (FW-1 firmware).
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2026-04-24 Phase 3 C1.2: matrix + encoder DT bindings
    5x5 col2row matrix via zmk,kscan-gpio-matrix with 5 ms debounce. Rows
    are pulled-down inputs; columns are driven outputs. 1N4148W diode
    direction cathode->row is column-scan-compatible.
    ENC_A/ENC_B on back-pad slots 0/1 wired via alps,ec11 sensor; 80 steps
    per detent, triggers-per-rotation=20.
    Front-pin rework vs PCB Cycle 5: COL1 moves from D1 (P0.03/AIN1) to D10
    (P1.15), freeing D1 for NTC_ADC bodge. This gives NTC a genuine SAADC
    channel (AIN1) rather than routing through a non-analog GPIO. COL1 as
    a digital output on P1.15 is unaffected. Documented in the overlay
    header and BODGE-MAP.md (commit 8).
    I2C0 pinctrl uses P0.04/P0.05 (TWI0) for the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
2026-04-24 Phase 3 C1.4: RGB WS2812 chain + 300 mA Annex Q hard cap enforcement
    Overlay: SPI3 with pinctrl on P0.06 (RGB_DIN_MCU, back-pad slot 3)
    feeding a worldsemi,ws2812-spi node with chain-length=25. 4 MHz SPI,
    one-frame=0x70 / zero-frame=0x40 encodes SK6812MINI T0H/T1H timing
    within the 1.25 us bit period.
    ccp_safety driver (drivers/ccp_safety/):
    - ccp_rgb_init_safe.c: SYS_INIT at POST_KERNEL priority 45 drives
    P0.06 GPIO output LOW before SPI/WS2812 driver initialisation
    (default priorities 50 / 90). Satisfies firmware/zmk/README.md
    §RGB driver init order steps 1-2. 200 us hold lets the SK6812
    latch with all-zeros and lets +3V3 stabilise.
    - ccp_safety_common.c: cap registry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
    [ccp_rgb_init_safe.c]
2026-04-24 Phase 3 C1.5: VBAT SAADC monitoring, undervolt cutoff, broken-wire detect
    Overlay: SAADC vbat_adc_ch on AIN7 / P0.31 (back-pad slot 5), gain 1/6,
    internal 0.6 V ref, OVERSAMPLE=3 -> 8 samples with BURST mode per
    firmware/zmk/README.md §Hard Requirement: Battery Cutoff Voltage.
    acquisition time 40 us per sample matches the 500 kOhm source-impedance
    settling budget.
    ccp_battery_guard.c: k_work_delayable sampling every 10 s (Kconfig
    tunable). Implements every Hard Requirement from the README:
    - Cutoff VBAT: 3.70 V when leds_cut=false, 3.50 V when leds_cut=true
    (200 mV hysteresis band).
    - Linear derate 3.90 V -> 3.70 V -> 100 % -> 0 % cap published to
    the ccp_safety cap registry.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
    [ccp_battery_guard.c]
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2026-04-24 Phase 3 C1.9: QMK alternate skeleton (RP2040 Pro Micro)
    Starter scaffold in firmware/qmk/keyboards/claude_code_pad/ so RED-FW
    has a reviewable escape hatch if the ZMK path hits a blocker. Includes
    info.json (matrix pinout, encoder, WS2812, 5x5 ortho layout with 2U
    Enter), rules.mk, claude_code_pad.c (encoder rotate -> up/down), and a
    keymap stub with the Claude Code string macros (SubAgent, Commit
    Trunk/PR, Test, Build) and the y/n/a/A acks.
    NOT production-validated. firmware/qmk/README.md documents the porting
    deltas vs the XIAO PCB (pin-mapping table), the missing features (no
    BLE, no VBAT monitoring, no battery cutoff), and the wiring-adapter
    requirement. Phase 3 primary firmware remains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
    [keymap.c]
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2026-04-24 Phase 3 C2.3: safety driver suite rewrite (all 4 files + Kconfig + CMake)
    Closes the RED-SAFETY blocker cluster and the majority of RED-FW
    findings against the ccp_safety drivers.
    ccp_safety.h / ccp_safety_common.c
    ----------------------------------
    - SF-B2: cap registry default is now 0 for every source (fail-dark).
    Each guard must post a successful sample before its slot rises
    above 0. Cycle 1 shipped a default of 100 which meant a silent-ADC
    guard looked like "no cap" rather than "maximum cap".
    - SF-M1: per-source TTL. Each `ccp_safety_set_cap` call carries the
    expected sample-interval; if the registry hasn't seen a refresh
    within 2 * interval the slot is treated as 0.
    - SF-M2: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
    [ccp_battery_guard.c, ccp_rgb_init_safe.c, ccp_thermal_guard.c]
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2026-04-25 Phase 3 C2.6: docs + UF2 artifact + QMK VIA + review log close
    Closes the remaining doc-shaped items from RED-FW + RED-SAFETY and
    records the cycle in the project review log.
    README.md
    - FW-B2: VBAT_ADC pin documented as P0.31/AIN7. Footnote: P1.x
    pins are NOT SAADC-capable on nRF52840; AIN0..7 are at P0.02,
    P0.03, P0.04, P0.05, P0.28, P0.29, P0.30, P0.31 per the v1.7
    product spec §6.17. Cycle 1 had P1.11/AIN7 in three places.
    - Battery-cutoff table rewritten: derate band 4.00 V -> 3.80 V,
    leds_cut latches at 3.80 V with 100 mV hysteresis, graceful
    shutdown at 3.50 V (SF-M4 / SF-M6).
    - VBAT broken-wire section: 250 ms cadence (was 10 s), two-window
    latch (SF-M5), physical-range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
    [keymap.c]
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2026-04-25 Phase 3 C3.4: floating-probe re-arm on every OOR transition
    Cycle 2 review caught a real correctness bug in ccp_thermal_guard.c:
    the divider-floating verification used a function-local
    `static bool need_divider_check = true` that flipped to false on the
    first probe and never recovered. A wire that flapped (OOR -> in-range
    -> OOR -> in-range) silently re-armed the in-range path WITHOUT
    re-running the probe, so a transient floating wire could
    permanently disable the divider check after the first OOR cycle.
    Fix: hoist `need_divider_check` to file scope and set it back to
    true on every OOR sample. The next in-range sample then re-runs
    ntc_floating_probe() before trusting the reading. The probe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
    [ccp_thermal_guard.c]
2026-04-25 Phase 3 C3.5: latch policy comment + rate-limit unit reconciliation
    Closes two RED-SAFETY MINORs from Cycle 2 review:
    1. battery_guard latch comment said "reschedule to keep the WDT
    happy" but the code actually returns WITHOUT rescheduling. The
    no-reschedule behaviour is the intended post-latch policy: once
    we stop petting CCP_WDT_BATTERY, the aggregator stops feeding
    the hardware WDT and the SoC resets within one WDT window
    (4 s + 250 ms aggregator interval). That reset is the recovery
    path -- the bootloader re-runs ccp_rgb_init_safe and the guards
    re-init from a clean fail-dark state. Comment now matches the
    actual code path and explains why this is the correct pol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
    [ccp_battery_guard.c, ccp_thermal_guard.c]
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
